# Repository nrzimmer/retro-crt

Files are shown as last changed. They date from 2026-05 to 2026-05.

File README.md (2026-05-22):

# CRT — Setup de Videogames em CRT

Documentação para uso e modificação de TV CRT Sony Trinitron KV-21FS140 com consoles retro via RGB SCART.

## Estrutura

```
tv/          — tudo sobre a KV-21FS140 (manuais, circuitos, mod, reparo)
scart/       — padrão SCART, switches, cabos por console
consoles/    — mods internos dos consoles (RGB, áudio, etc.)
```

| Pasta | Conteúdo |
|---|---|
| [`tv/`](tv/) | Manual de serviço, análise de circuitos, mod RGB, reparo pincushion |
| [`scart/`](scart/README.md) | Padrão SCART, switch, cabos por console, fornecedores |
| [`consoles/`](consoles/) | Mods de consoles (NES NESRGB/PPU-LITE, N64 RGB, SNES Mini, MD stereo) |

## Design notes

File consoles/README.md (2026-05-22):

# Consoles — Mods Internos

Mods de hardware nos consoles para habilitar ou melhorar saída RGB/áudio.  
Cabos SCART correspondentes estão em [`scart/cables/`](../scart/cables/).

| Pasta | Console | Mods documentados |
|---|---|---|
| [`nes/`](nes/) | NES / Famicom | NESRGB, PPU-LITE (open source), áudio stereo, expansion audio |
| [`n64/`](n64/) | Nintendo 64 | RGB amp (THS7316), opções de mod analógico |
| [`snes/`](snes/) | Super Nintendo | SNES Mini — csync no chip S-RGB |
| [`megadrive/`](megadrive/) | Sega Mega Drive | Mod stereo áudio (MD1) |

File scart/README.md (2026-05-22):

# Cabos SCART RGB

Documentação para construção de cabos SCART RGB para consoles retro.  
Alvo principal: mod RGB no KV-21FS140 (`../tv/mod_rgb/rgb_mod.md`).

## Índice

| Arquivo | Conteúdo |
|---|---|
| [standard.md](standard.md) | Padrão SCART 21 pinos — referência |
| [switch.md](switch.md) | Switch SCART: topologias, chips, projetos OSS |
| [fornecedores.md](fornecedores.md) | Onde comprar conectores e componentes |

### Cabos por console (`cables/`)

| Arquivo | Console | Conector | Status |
|---|---|---|---|
| [cables/nes.md](cables/nes.md) | NES / Famicom | MultiAV 12P (via NESRGB mod) | documentado — requer mod RGB |
| [cables/snes.md](cables/snes.md) | Super Nintendo / Super Famicom | MultiAV 12P card-edge | documentado |
| [cables/megadrive.md](cables/megadrive.md) | Sega Mega Drive 1 e 2 | DIN-8U / mini-DIN 9 | documentado |
| [cables/ps1.md](cables/ps1.md) | PlayStation 1 / PSone | Proprietário 12P | documentado |
| [cables/ps2.md](cables/ps2.md) | PlayStation 2 | Proprietário 12P (= PS1) | documentado |
| [cables/n64.md](cables/n64.md) | Nintendo 64 | MultiAV 12P (= SNES) | documentado — requer mod RGB |
| [cables/saturn.md](cables/saturn.md) | Sega Saturn | mini-DIN 10 | documentado |
| [cables/neogeo.md](cables/neogeo.md) | SNK Neo Geo AES/MVS | DIN-8C | documentado |

### Mods de consoles (`../consoles/`)

| Arquivo | Console | Conteúdo |
|---|---|---|
| [../consoles/nes/](../consoles/nes/) | NES / Famicom | NESRGB, PPU-LITE, mods de áudio |
| [../consoles/n64/](../consoles/n64/) | Nintendo 64 | THS7316, opções de mod RGB |

## Componentes comuns a todos os cabos

| Componente | Valor | Função |
|---|---|---|
| R_blank_top | 820Ω | Divisor blanking (SCART pin 16) |
| R_blank_bot | 1kΩ | Divisor blanking → ~2.6V |

## Componentes específicos por console

| Console | Componente extra | Motivo |
|---|---|---|
| SNES NTSC | 220µF ×3 nas linhas RGB | DC offset ~1V na saída |
| SNES PAL | 75Ω ×3 para GND nas linhas RGB | Redução de contraste |
| NES (NESRGB) | 220µF ×3 nas linhas RGB | Mesmo DC offset do SNES |
| N64 (após mod) | 220µF ×3 nas linhas RGB | Mesmo DC offset do SNES |
| PS1 | 220µF ×3 nas linhas RGB | PS1 não tem caps internamente |
| PS2 | Nenhum extra | PS2 já tem 220µF internamente |
| Saturn | 470Ω + 220µF na linha csync | Artefatos no Model 2 sem eles |

## Avisos críticos

> ⚠️ **SNES PAL:** Pin 3 = +12V. Cabo NTSC em SNES PAL danifica equipamento.  
> ⚠️ **NES:** sem mod NESRGB, zero RGB — nem composite RGB.  
> ⚠️ **N64 NTSC:** sem mod RGB interno, cabo SCART RGB não funciona.  
> ⚠️ **PS1 ≠ PS2:** cabos não são intercambiáveis — caps nos canais RGB diferem.  
> ⚠️ **PS2 + 480p:** muitos jogos forçam 480p (31kHz) — incompatível com KV-21FS140.

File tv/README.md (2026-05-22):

# TV — Sony Trinitron KV-21FS140

Documentação técnica, mods e reparo da KV-21FS140 (chassis BX1S).

## Estrutura

| Pasta | Conteúdo |
|---|---|
| [`manual/`](manual/README.md) | PDFs e páginas extraídas dos dois manuais de serviço |
| [`circuits/`](circuits/) | Análise dos blocos de circuito, service mode, diagnóstico |
| [`mod_rgb/`](mod_rgb/rgb_mod.md) | Mod RGB SCART (esquemático, netlist, KiCad) |
| [`repair/`](repair/) | Reparo pincushion — lista de componentes |

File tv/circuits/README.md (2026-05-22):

# Circuits — Análise de Circuitos KV-21FS140

Análise dos blocos de circuito da A Board e C Board, parâmetros de service mode e diagnóstico.  
Baseado em ambos os manuais — diferenças entre rev_brazil e rev_s79aa são anotadas em cada arquivo.

## Arquivos

### Blocos de circuito (A Board)

| Arquivo | Bloco | Conteúdo |
|---|---|---|
| [block_001_processor.md](block_001_processor.md) | Block 001 | IC001 One-Chip — System/Video/Audio Processor |
| [block_002_audio.md](block_002_audio.md) | Block 002 | IC200 Audio Amp (AN5276T / AN17804A) |
| [block_003_psu.md](block_003_psu.md) | Block 003 | SMPS — transformador T600, reguladores |
| [block_004_deflection.md](block_004_deflection.md) | Block 004 | Deflexão H/V — Q805, IC804, FBT T801, EW |
| [block_005_if_tuner.md](block_005_if_tuner.md) | Block 005 | IF — tuner, VIF SAW, SIF, AGC |
| [block_006_av_inputs.md](block_006_av_inputs.md) | Block 006 | Entradas AV, SCART, RGB |
| [c_board_rgb_amp.md](c_board_rgb_amp.md) | C Board | IC751 TDA6108AJF — RGB amp para cátodos do CRT |

### Service Mode e Diagnóstico

| Arquivo | Conteúdo |
|---|---|
| [self_diagnostic.md](self_diagnostic.md) | Códigos LED, diagnóstico por sintoma, proteções |
| [service_mode_categories.md](service_mode_categories.md) | Todas as categorias GEOM/WHBL/SADJ/etc. com valores por variante |
| [geom_service_params.md](geom_service_params.md) | Parâmetros GEOM detalhados, sequência de ajuste |
| [voltage_waveform_table.md](voltage_waveform_table.md) | Tensões nominais e formas de onda |

### Análise geral

| Arquivo | Conteúdo |
|---|---|
| [schematic_analysis.md](schematic_analysis.md) | Análise completa de todos os blocos do esquemático |

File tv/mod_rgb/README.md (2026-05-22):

# Mod RGB — KV-21FS140

Mod para habilitar entrada RGB SCART via CN004/CN701 (C Board).

| Arquivo | Conteúdo |
|---|---|
| [rgb_mod.md](rgb_mod.md) | Descrição do mod, componentes, procedimento de instalação |
| [rgb_mod_netlist.md](rgb_mod_netlist.md) | Netlist do circuito do mod |
| [rgb_mod_schematic.svg](rgb_mod_schematic.svg) | Esquemático em SVG |
| [rgb_mod.kicad_sch](rgb_mod.kicad_sch) | Projeto KiCad |
| [gen_kicad_sch.py](gen_kicad_sch.py) | Script Python que gerou o esquemático KiCad |

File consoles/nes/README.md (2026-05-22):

# NES / Famicom — Mods RGB e Áudio

---

## RGB — NES não tem saída nativa

NES padrão (front-loader e top-loader USA) só tem saída **RF e composite**.  
RGB requer mod interno obrigatório.

| Modelo | RGB nativo | Notas |
|---|---|---|
| NES front-loader (USA) | ✗ | Mod obrigatório |
| NES top-loader (USA) | ✗ | Mod obrigatório |
| Famicom original (JP) | ✗ | Composite + RF apenas |
| AV Famicom (HVC-101) | ✗ RGB nativo | Composite + S-Video; sem RGB sem mod |
| Famicom Titler | ✓ | Raríssimo — saída RGB/S-Video nativa |

---

## Mods RGB disponíveis

| Mod | Saída | Conector instalado | Notas |
|-----|---|---|---|
| **NESRGB** (Tim Worthington) | RGB analógico | Multi-out estilo SNES | Melhor opção — usa PPU original |
| PC-10 (Playchoice-10) | RGB analógico | Depende da instalação | Original Nintendo, difícil de encontrar |
| Hi-Def NES | HDMI digital | HDMI | Não usa SCART |
| UltraHDMI | HDMI digital | HDMI | Não usa SCART |

---

## PPU-LITE — alternativa open source ao NESRGB

**PPU-LITE** (andkorzh) — substituto FPGA do PPU, open source, custo reduzido.

| Aspecto | NESRGB (original) | PPU-LITE (open source) |
|---|---|---|
| Licença | Proprietário (Tim Worthington) | Open source — GitHub |
| PCB | 4 camadas | **2 camadas** — mais barato |
| FPGA | — | Cyclone I EP1C3T100C8N (Altera) ou Lattice LCMXO2 |
| Forma/tamanho | Referência | **Idêntico ao NESRGB** — mesmos adaptadores |
| Paletas (Cyclone) | — | 4: NES Classic, SONY CXA, Smooth, Natural Nestopia YUV |
| Paletas (Lattice) | — | 8: + CDIRECT, PC-10, PVM Style, WaveBeam |
| Seleção paleta | — | Jumpers J3/J4 (Cyclone) ou J3/J4/J5 (Lattice) |
| DAC | ADV7125 | R2R discreto com arrays de resistores |
| Venda | Tim Worthington / revendedores | Ninguém vendendo ainda — fabricar próprio |
| Instalação | Igual ao NESRGB | Igual ao NESRGB |

**Repositório:** https://github.com/andkorzh/PPU-LITE  
**Gerbers:** inclusos no repo — mandar fabricar JLCPCB/PCBWay  
**Upload FPGA:** somente arquivo `.jic` (Cyclone) ou equivalente Lattice — NÃO usar `.pof`

> PPU-LITE foi intencionalmente dimensionado igual ao NESRGB para reaproveitar todos os métodos de instalação e adaptadores existentes.

---

## Onde comprar

### Conector Multi-out para cabo DIY

| Fornecedor | Link | Notas |
|---|---|---|
| Humble Bazooka | [SNES Multi-Out for NESRGB](https://www.humblebazooka.com/products/snes-style-multi-out-connector-for-nesrgb/) | Conector específico para instalar no NES |
| Console5 | [SNES/N64/GCN AV Multi-Out plug](https://console5.com/store/nintendo-snes-super-famicom-n64-av-multi-out-plug-for-custom-rgb-cables-repair.html) | Conector macho para o cabo (lado do cabo, não do console) |

### Mod NESRGB

| Fornecedor | Link | Notas |
|---|---|---|
| 8BitMods (oficial) | [NESRGB by Tim Worthington](https://8bitmods.com/nesrgb-by-tim-worthington/) | Original — qualidade garantida, frete internacional |
| AliExpress (clone) | [1:1 copy NESRGB kit](https://www.aliexpress.com/item/1005006858950207.html) | Clone — "1:1 copy", funciona mas não é original |
| AliExpress (clone) | [NESRGB kit — busca geral](https://www.aliexpress.com/w/wholesale-nesrgb.html) | Vários vendedores, preços variados |
| AliExpress (clone) | [5× NESRGB PCB board](https://www.aliexpress.com/i/1005003035447719.html) | PCB avulso — precisa soldar componentes |
| **PPU-LITE (open source)** | [GitHub andkorzh/PPU-LITE](https://github.com/andkorzh/PPU-LITE) | Fabricar gerbers no JLCPCB — mais barato |

> **Clone AliExpress vs original:** clones "1:1" geralmente funcionam mas qualidade de fabricação varia. Para uso sério, preferir original da 8BitMods ou fabricar PPU-LITE pelos gerbers.

---

## Alternativas de vídeo ao RGB SCART

NES não tem saída component nativa. Opções além de RGB/SCART:

| Alternativa | Qualidade | Notas |
|---|---|---|
| NESRGB / PPU-LITE → SCART | ✓✓ Melhor analógico | Mod interno obrigatório |
| Hi-Def NES / UltraHDMI | ✓✓ Digital | HDMI direto, sem SCART |
| Upscaler (RetroTINK 2x) | ✓ Boa | Composite/S-Video → HDMI; sem mod no NES |
| S-Video (NES top-loader) | ✓ Razoável | Top-loader tem saída S-Video melhorada |
| Composite direto | Baixa | Sem mod; funciona com mod RGB da KV-21FS140 via AV2 |

> Não existe mod component para NES. RGB → SCART é o melhor analógico disponível.

---

## Mod Áudio

### Áudio mono (sem mod)

Sem nenhum mod de áudio, simplar o pino mono nos dois canais do SCART:

```
NES Audio (mono) ──┬──► SCART Pin 6  (Audio In L)
                   └──► SCART Pin 2  (Audio In R)
```

TV recebe mesmo sinal nos dois canais — ambos os alto-falantes funcionam.

### Mod "Stereo" (pseudo-stereo)

O NES tem APU com **duas saídas separadas antes do mixer interno**:

| Canal | Conteúdo |
|---|---|
| AUX A (canal 1) | Pulso 1 + Pulso 2 (square waves) |
| AUX B (canal 2) | Triângulo + Ruído + DPCM |

Não é stereo real — é separação dos grupos de canais do APU em duas saídas.

**Plain mod:**
- Desconectar AUX A e AUX B do mixer interno
- Adicionar cap 1µF em série em cada canal (polo − para o console)
- Adicionar conector de saída (RCA L/R ou P2 stereo)

**Mixback mod:**
- Tocar AUX A e AUX B sem desconectar do mixer
- Adicionar potenciômetro duplo para misturar o sinal mono de volta (controle de separação)
- Permite ajustar de mono completo a separação máxima

### Expansion Audio (Famicom)

Alguns cartuchos Famicom têm chips de som extras (VRC6, VRC7, MMC5, FDS, etc.) que misturam áudio adicional pelo pino 46 do slot de 60 pinos. No NES (72 pinos) esses pinos não existem — expansão é silenciada.

**O EverDrive N8 suporta expansion audio** — emula os chips de som nos mappers. Mas o NES front-loader precisa de mod para rotear esse áudio até a saída.

#### Mod expansion audio — NES front-loader com EverDrive N8 / flashcart 72 pinos

Soldar **resistor 47kΩ** entre dois pinos da porta de expansão (conector na parte inferior do front-loader):

```
Expansion pin 9  (EXP6) ── 47kΩ ──► Expansion pin 3  (Audio mix input)
```

Opcional mas recomendado para reduzir ruído:
```
Expansion pin 9  (EXP6) ── 1kΩ ──► Expansion pin 2  (GND)
```

> ⚠️ Não confundir **expansion pin 9 (EXP6)** com **expansion pin 6 (EXP9)** — nomes confusos intencionalmente.

**Com NESRGB instalado:** o NESRGB tem ponto de mix dedicado (hole próximo ao jumper J5). Soldar fio blindado 28AWG nesse ponto, passar resistor 47kΩ em série, conectar ao pino de expansão. Guia completo com fotos: [firebrandx.com/edn8tonesrgb.html](http://www.firebrandx.com/edn8tonesrgb.html)

**Volume:** EverDrive N8 firmware controla volume por mapper. Para VRC6, volume level 35 é o mais balanceado. Se necessário, substituir arquivo `EDFC/MAPS/024.RBF` na SD card pela versão fixada em volume 35.

**Adaptador potenciômetro (opcional):** em vez de resistor fixo 47kΩ, usar pot 100kΩ + resistor fixo 20kΩ em série — permite ajustar volume sem abrir o console.

#### Jogos com expansion audio (Famicom)

| Chip | Jogos notáveis |
|---|---|
| VRC6 | Castlevania III (JP), Akumajo Densetsu |
| VRC7 | Lagrange Point |
| MMC5 | Castlevania III (USA tem MMC5 — mas sem expansão no NES) |
| FDS | Metroid (JP), Zelda (JP), Gimmick! |
| Sunsoft 5B | Gimmick! |
| N163 | Megami Tensei II |

---

## Referências

- [NES RGB — RetroRGB](https://retrorgb.com/nesrgb.html)
- [NES "Stereo" Audio Mod — ConsoleMods](https://consolemods.org/wiki/NES:%22Stereo%22_Audio_Mod)
- [NES Expansion Audio Mod — ConsoleMods](https://consolemods.org/wiki/NES:Expansion_(EXP)_Audio_Mod)
- [EverDrive N8 + Expansion Audio + NESRGB — firebrandx.com](http://www.firebrandx.com/edn8tonesrgb.html)

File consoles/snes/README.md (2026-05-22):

# Super Nintendo / Super Famicom — Mods

---

## SNES Mini (Super Famicom Jr.) — csync

SNES Mini não expõe csync no MultiAV. Para usar cabo SCART com csync limpo:

- csync disponível no **pino 18 do chip S-RGB** (PPU2 / S-RGB encoder) na placa
- Requer acesso interno e fio soldado até o conector MultiAV ou diretamente ao cabo

Alternativa sem mod: usar luma (pin 7 do MultiAV) como sync — funciona com a maioria dos displays.

---

## Referências

- [SNES Mini RGB — RetroRGB](https://retrorgb.com/snesminijr.html)

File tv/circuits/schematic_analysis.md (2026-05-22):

# KV-21FS140 — Análise Completa dos Esquemáticos

## Estrutura da A Board (7 Blocos)

A placa principal (A Board) está dividida em 7 blocos funcionais. Cada bloco é uma seção do esquemático com nome e número de referência de grade (letras A–L, números 1–17).

Conexões entre blocos são indicadas como `XXX:YZ` → bloco:coluna/linha.

---

## BLOCK 001 — Processador Central (IC001)

**Função:** Núcleo do sistema. Contém o IC one-chip que faz tudo: controle de sistema, processamento de vídeo, processamento de áudio, demodulação, geometria.

### IC principal
| Ref | Tipo | Função |
|-----|---|---|
| IC001 | TDA12009H (ou variante) | One-chip: System Controller + Video Processor + Audio Processor |
| IC003 | CAT24WC16WI-TE13 | NVM — EEPROM 16kbit (armazena dados de serviço) |
| IC002 | RPM7240-H5 | IC Receiver (controle remoto SIRCS) |

### Transistores de interface e proteção
| Ref | Tipo | Função |
|-----|---|---|
| Q001 | UN2211 | RGB-MUTE SPOT — mute dos sinais RGB no CRT |
| Q006 | UN2216 | G LED SW — switch do LED verde (standby) |
| Q007 | UN2216 | R LED SW — switch do LED vermelho |
| Q010 | 2SA1235-F | Buffer geral |
| Q013 | (XX) | S2 switch |
| Q016 | UN2211 | PROTECTOR |

### Componentes passivos notáveis
| Ref | Valor | Função |
|-----|---|---|
| X001 | 181331121 | Cristal de referência 24.576MHz (clock principal IC001) |
| L036 | 22µH | Filtro de alimentação 3.3V |
| L040 | 10µH | Filtro alimentação |
| D914 | SPB-25MVWF | LED bicolor (standby/ativo) |
| D002 | MMDL914T1 | Diodo fornecimento 3.3V |
| D003 | MMDL914T1 | Diodo fornecimento 5V |
| D057/D058/D059 | MMDL914T1 | R-MUTE / G-MUTE / B-MUTE (mute individual de canhões RGB) |

### Pinos chave do IC001 (por função)
| Pino | Sinal | Destino/Origem |
|---|---|---|
| 21 | EWD | EWD-DEFL → Block 004 grid 5A (sinal de correção pincushion) |
| 32 | EHTO | OCP (detecção overcurrent do +B) |
| 65 | VM | VM OUT — Velocity Modulation (saída para VM coil) |
| 66 | AFC | AFC-DEFL → Block 004 (AFC horizontal) |
| 67 | HOUT | HOUT-DEFL → Block 004 grid 6A (pulso de drive horizontal) |
| 83 | ABL | ABL → Block 004 (Automatic Beam Limiter) |
| 13 | VGUARD | VGUARD-DEFL → Block 004 (proteção vertical) |
| 14/15 | PH2LF/PH1LF | Horizontal PLL phase → Block 004 |
| 22/23 | VD+/VD- | Vertical drive → Block 004 |
| 84 | IK | AKB (Auto Black Level) feedback do C Board |
| 85/86/87 | B/G/R OUT | Saída RGB → C Board via CN004/CN701 |
| 108/109 | SCL0/SDA0 | I²C bus para NVM e dispositivos auxiliares |
| 110 | VDDP(3.3V) | Alimentação digital 3.3V IC001 |

### Conectores do Block 001
| Conector | Pinos | Destino |
|---|---|---|
| CN004 | 7P | → C Board CN701 (R/G/B/IK/GND/9V) |
| CN005 | 3P | Botões frontais (KEY) |
| CN007 | (XX) | → Block 006 CN905 |

### Tensões IC001 (medidas representativas)
- Pin 4: 2.6V, Pin 5: 3.2V, Pin 21: 3.2V (EWD)
- Pin 45 (VCC8V): 8.3V, Pin 84 (IK): 1.5V
- Pin 110 (VDDP 3.3V): 3.2V

---

## BLOCK 002 — Amplificador de Áudio

**Função:** Amplificação final de áudio, circuito de mute, proteção de saída.

### IC principal
| Ref | Tipo | Função |
|-----|---|---|
| IC200 | AN5276T | Audio Amplifier — 2× 10W |

### Transistores
| Ref | Tipo | Função |
|-----|---|---|
| Q200 | UN2211 | BUFFER |
| Q201 | 2SA1235-F | BUFFER |
| Q202 | 2SA1235-F | AC MUTE |
| Q204, Q205 | (XX) | BUFFER (não montados neste modelo) |
| Q206 | UN2211 | MUTE CCT |

### Passivos notáveis
| Ref | Valor | Função |
|-----|---|---|
| C214/C215/C216/C217 | 1000/2200µF 25V | Capacitores de saída do amp |
| C218/C219 | 22µF | Filtros de feedback |
| R234, R235 | 47Ω FPRD | Resistores fusíveis de proteção (saída do amp) |
| R2646, R2647 | 1Ω / 10k FPRD | Resistores de sensing de saída |
| J200 | 177078631 | Conector de entrada de áudio |
| CN200 | 4P WHT | Conector de saída para alto-falantes |

### Sinais de controle
- `AUDIO-STDBY` ← 001:1F (standby de áudio)
- `AUDIO-MUTE` ← 001:4L (mute geral)
- `MOMUTE-AUDIO` ← 001:7A (mute de monitor out)
- `PWR-OFF-MUTE` ← 001:5A

### Tensões
- IC200: alimentado por 9V
- Q201: B=82.3V, C=0V, E=0V (em standby)

---

## BLOCK 003 — Fonte de Alimentação (SMPS)

**Função:** Conversora chaveada principal. Gera todas as tensões secundárias a partir de 110–220V AC.

### ICs e reguladores
| Ref | Tipo | Função |
|-----|---|---|
| IC601 | (175519811) | SWITCHING REGULATOR IC principal do SMPS |
| IC602 | KIA78R09API | Regulador linear 9V (entrada 11V) |
| IC603 | PQ018EF01SSH | Regulador 1.8V (para áudio) |
| IC604 | KIA7805API | Regulador linear 5V |
| IC605 | SE135N-LF38 | ERROR AMP / REG auxiliar |
| IC606 | KIA78D33P1 | Regulador linear 3.3V |
| IC607 | BA18BC0FP-E2 | Regulador 1.8V principal (digital) |

### Transistores de potência
| Ref | Tipo | Função |
|-----|---|---|
| Q601 | (não listado explicitamente) | RELAY SW — chave do relé principal |
| Q605 | (XX) | BUFFER regulador |
| Q606 | (componente crítico !) | Transistor principal de chaveamento |
| Q608 | 2SC1623-L5L6 | SW auxiliar |
| Q609 | 2SC1623-L5L6 | SW auxiliar |

### Componentes críticos de segurança (marcados !)
| Ref | Valor/Tipo | Função |
|-----|---|---|
| THP600 | TERMISTOR PTC | Proteção térmica / limitação de inrush |
| C660 | 0.22µF 275V PP | Filtro EMI fase/neutro |
| T600 | MTZJ-T-77-15 | Transformador principal SMPS (!!) |
| T603 | — | Transformador auxiliar |
| T604, T605 | — | Transformadores de isolação |
| PS602, PS603, PS604, PS605 | 5A 90V | Varistores PTC de proteção |
| F600 | FUSÍVEL | Fusível principal da A Board |
| S600 | — | Varistor de proteção (VDR600) |
| VDR600 | — | Varistor de surto |
| D604 | D3SB60F3 | Ponte retificadora AC |
| RY600 | RELAY AC POWER | Relé de entrada AC |

### Tensões produzidas
| Linha | Tensão | Observação |
|---|---|---|
| +B | ~135V | Linha principal para deflexão H |
| 11V | 11V | Input para IC602 |
| 9V | 9V | IC602 output; para áudio, tuner, etc. |
| 5V | 5V | IC604; para digital |
| 3.3V | 3.3V | IC606; para digital |
| 1.8V | 1.8V | IC607 e IC603 |
| 30V | 30V | Para RF Amp/Tuner |

### Proteções
- OCP: detectado por IC001 pin 32 ← feedback de Q816 collector (Block 004)
- OVP: detectado por IC001 pin 13 (V-GUARD) ← pulso vertical ausente
- Relé DGC: acionado por DGC-RELAY signal de IC001 (desmagnetização)

---

## BLOCK 004 — Deflexão (DEFLECTION)

**Função:** Geração e amplificação dos sinais de deflexão horizontal e vertical, incluindo circuitos de pincushion EW, S-correction, ABL, proteções OCP/OVP.

Este bloco é o mais crítico para geometria da imagem.

---

### 4A. Estágio de Driver Horizontal + Pincushion (EW)

#### Cadeia de sinal horizontal:
```
IC001 pin HOUT → [HOUT-DEFL] → Q807 (PIN DRIVE) → T800 → Q805 (H-OUT) → T801 (FBT)
```

| Ref | Tipo | Função | Tensões medidas |
|-----|---|---|---|
| Q807 | 2SA1235-F | PIN DRIVE — transistor PNP de pré-drive do horizontal + pincushion | E=0.1V, B=1.1V, C=0V |
| Q803 | 2SC3209LK | PIN AMP / H-DRIVE — amplificador do sinal de pincushion | C≈70V, E=0V, B≈133V |
| T800 | 143793622 | Transformador driver horizontal — acopla o drive para Q805 | — |
| Q805 | 2SC5885 | H-OUT — transistor de saída horizontal principal (NPN alta tensão) | Coletor: pulso >500Vp-p |
| D807 | BY228GP | DAMPER — diodo amortecedor horizontal (essencial para forma de onda) | — |
| D817 | PG156R | DAMPER secundário | — |

#### Componentes do circuito de pincushion EW (East-West):

O pincushion (efeito almofada) resulta do fato de que a tela plana ou levemente curvada precisa de maior amplitude de varredura nas linhas do centro (onde a distância ao canhão é maior) e menor nos extremos verticais. O circuito EW modula a amplitude do sinal horizontal com uma forma de onda parabólica sincronizada com a frequência vertical.

**Fluxo de sinal EW:**
```
IC001 pin EWD → [EWD-DEFL → Block 004 grid 5A]
    → IC802 (op-amp TJM4558CDT) → amplifica/formata sinal parabólico
    → Q806 (MIXER 2SC1623) → combina com sinal H
    → L802 (22mH) → bobina EW em série com yoke H
    → DY800 → Deflection Yoke (bobinas horizontais)
```

| Ref | Valor/Tipo | Função |
|-----|---|---|
| IC802 | TJM4558CDT | Op-amp duplo — formata/amplifica sinal EWD da IC001 |
| Q806 | 2SC1623-L5L6 | MIXER — mistura sinal EW na corrente horizontal |
| Q809 | 2SC3209LK | Transistor auxiliar EW/drive |
| Q810 | 2SC3209LK | Transistor auxiliar EW |
| L802 | 22mH | **Bobina EW** — em série na alimentação do yoke horizontal, modula amplitude H |
| C857 | 220µF 25V | Filtro/reservatório EW |
| C861 | 220µF 25V | Filtro/reservatório EW |
| C867 | 33µF 160V | Capacitor ressonante do estágio H-OUT (junto com L805) |
| C878 | 0.01µF 25V | Bypass EW |
| D818 | 10ERB20-TB3 | Retificador EW |
| D819 | 10ERB20-TB3 | Retificador EW |
| D821 | 10ERB20-TB3 | H-CENT1 — circuito de posição horizontal |
| D823 | PG104R | RECTIFIER EW |
| D824 | PG104R | RECTIFIER EW |
| D827 | PG104R | RECT |
| D828 | — | circuito auxiliar |
| R890 | — | Resistor de ajuste EW |
| R888 | 47kΩ | Divisor de sinal EW |
| C860 | 1000p 500V | Filtro HV EW |

**Tensões medidas IC802 (TJM4558CDT):**
| Pino | V | Função |
|---|---|---|
| 1 | 3.3V | OUT1 (saída do 1º amp) |
| 2 | 2.2V | IN1- |
| 3 | 6.0V | IN1+ (recebe EWD de IC001) |
| 4 | 8.8V | V+ (alimentação positiva) |
| 5 | 2.4V | IN2+ |
| 6 | 3.1V | IN2- |
| 7 | 3.0V | OUT2 |
| 8 | 0V | V- (GND) |

#### Circuito de S-Correction:

A S-correction compensa a distorção em S na varredura horizontal (causada pela diferença entre a trajetória do feixe e a tela plana ao longo do eixo X).

| Ref | Tipo | Função |
|-----|---|---|
| Q808 | IRF614-037 | **S-CORRECTION** — MOSFET de potência, controla a modulação de largura horizontal para compensar distorção em S |
| C825 | 0.022µF 200V PP | Capacitor de S-correction |
| C842 | 0.022µF 400V PP | Capacitor de S-correction |
| R406 | XX | Resistor de S-correction |
| D801 | — | STOPPER do S-correction |

**Tensões Q808 (IRF614 MOSFET):**
- S: 1.8V, G: 0.1V, D: 0V (em repouso)

#### Circuito de H-Center (posição horizontal):

| Ref | Tipo | Função |
|-----|---|---|
| IC801 | LM2903DT | COMPARATOR — detecta e controla posição do centro H |
| S800 | 157270711 | Ajuste de centro H (trim) |
| D819 | 10ERB20-TB3 | H-CENT1 |
| R412 | 22kΩ 1/2W | Divisor do comparador |
| R411 | 68kΩ 1/2W | Divisor do comparador |
| R413 | 0.47Ω | Sensing de corrente |
| R405 | 0.47Ω | Sensing de corrente |
| R896 | 10kΩ | Pull-up |

---

### 4B. Estágio de Saída Horizontal (H-OUT) e FBT

| Ref | Tipo | Função |
|-----|---|---|
| Q805 | 2SC5885 | **H-OUT** — transistor de saída horizontal. Coletor conectado ao FBT (T801). Alta tensão de coletor em operação. |
| Q804 | KTA1279 | STOPPER — limita o pico de tensão no coletor de Q805 |
| Q814 | 2SC1623-L5L6 | Transistor auxiliar H |
| T801 | NX-4751//M3A4 | **FBT (Flyback Transformer)** — gera HV para ânodo do CRT (~25kV), e tensões secundárias (SV, FV, -13V para vertical, etc.) |
| T802 | (XX) | — não montado |
| D807 | BY228GP | DAMPER — absorve a energia de retrace, protege Q805 |
| D816 | — | Diodo auxiliar |
| C841 | 0.1µF 400V PP | Capacitor de ressonância H |
| C846 | — | Capacitor HV |
| C847 | — | Capacitor auxiliar |
| C867 | 33µF 160V | **Capacitor de ressonância principal** — junto com L805, determina frequência de ressonância do estágio H |
| L805 | 2.2mH | **Bobina de linearidade** — em série com yoke H, corrige linearidade |
| L804 | (XX) | — não montado |
| R400, R401 | 0.47Ω 1/2W FPRD | Sensing de corrente do yoke H (resistores fusíveis!) |
| R416 | 4.7kΩ 1/2W | Resistor no circuito FBT |
| JW1840, JW1841 | fios 5mm / 7.5mm | Conexões de ajuste da bobina de linearidade |

#### Tensões do FBT (T801) — saídas secundárias
| Enrolamento | Tensão | Destino |
|---|---|---|
| HV | ~25kV | Ânodo do CRT (via cabo HV) |
| FV | ~600V | Focus (G3) do CRT |
| SV | ~500V | Screen (G2) do CRT |
| -13V (VSS) | -13V | IC804 (vertical IC) pin 1 |
| +13V (VCC) | +13V | IC804 pin 3 |

#### Pinos do FBT usados no esquemático
| Terminal | Destino |
|---|---|
| T801-1 | HV + GND_1 |
| T801-2 | HV + GND_1 |
| T801-4 | HV + GND_1 |
| T801-5 | FV / SV |
| T801-7 | Secondary |
| T801-9 | Secondary |
| T801-11 | Secondary |

---

### 4C. Estágio Vertical (IC804)

| Ref | Tipo | Função |
|-----|---|---|
| IC804 | STV9302A | **VERTICAL IC** — amplificador de deflexão vertical completo |
| Q009 | (MIXER) | Amplificador auxiliar do vertical |
| C854 | 2.2µF 35V | Capacitor de bootstrap vertical |
| C855, C858 | — | Filtros verticais |
| R326 | 220Ω | Resistor de ganho |
| R327 | 3.3kΩ | Resistor de ganho |
| D820 | PG102R | Retificador auxiliar vertical |
| R891 | 100Ω FPRD | Resistor fusível de saída vertical |
| R895 | 2.2Ω FPRD | Sensing de corrente vertical (fusível) |

**Tensões IC804 (STV9302A):**
| Pino | V | Função |
|---|---|---|
| 1 | -13.5V | VSS — alimentação negativa |
| 2 | * | (pulso — não mensurável com multímetro) |
| 3 | 13.9V | VCC — alimentação positiva |

**Sinais de entrada no IC804:**
- VD+ e VD-: pulso vertical de IC001 (pinos 22/23)
- PH2LF: sinal de fase horizontal baixo de IC001

**Sinais de saída do IC804:**
- V+ e V- → Yoke vertical via DY800
- H+ → parte do estágio H (feedback)

---

### 4D. Conectores e Proteções do Block 004

| Ref | Pinos | Função |
|-----|---|---|
| DY800 | 6P | **Deflection Yoke** — pinos H.DY (2 pinos H) e V.DY (2 pinos V) |
| CN801 | (XX) → CN703 | Conector → C Board (sinal H1 para yoke de foco) |

**Proteções:**
| Sinal | Detectado por | Ação |
|---|---|---|
| OVP-DEFL | IC001 pin 13 (VGUARD) | Standby se deflexão V parar |
| OCP-PROTECT | IC001 pin 32 (EHTO) ← Q816 | Standby se +B tiver overcurrent |
| HOLD_DOWN | ← Block 003 (fonte) | Mantém transistores desligados |
| ABL | IC001 pin 83 ← FBT | Limita corrente do feixe |

**Componentes de proteção adicionais:**
| Ref | Tipo | Função |
|-----|---|---|
| D829 | (FPRD) | Clamp |
| D812 | RD5.1ESB2 | PROTECTOR |
| D816 | RD5.6SB-T1 | CLAMP REG |
| D832, D833 | MMDL914T1 | STOPPER — proteção do CN801 |
| D804, D805, D808, D809 | 1SS133T-77 | STOPPER |
| TH800 | — | Termistor — proteção térmica do estágio H |
| R421, R422, R423 | — | Resistores de proteção |

---

### 4E. Circuito de Rotation (Rotação de Imagem)

| Ref | Função |
|-----|---|
| IC800 | (XX) ROTATION AMP — não montado neste modelo |
| CN800 | (XX) — não montado |
| R800–R817 | (todos XX) — não montados |

Sinal ROT_CTRL e ROT_SW vêm de IC001 mas o circuito de rotação não está populado.

---

## BLOCK 005 — IF / Tuner

**Função:** Recepção e demodulação do sinal de RF. Inclui tuner, filtros SAW, circuito IF de vídeo e áudio.

### Componentes principais
| Ref | Tipo | Função |
|-----|---|---|
| TU101 | 169369411 | **Tuner principal** |
| TU102 | (XX) | Tuner secundário — não montado |
| SWF100 | 179592911 | SAW filter — filtro IF de vídeo (44MHz) |
| SWF101 | 181339111 | SAW filter — filtro IF de som |
| SWF103 | (XX) | SAW auxiliar — não montado |
| CF101 | (XX) | Filtro cerâmico — não montado |
| CT131 | (XX) | Capacitor trim — não montado |
| CT139 | 178152621 | Capacitor trim do PLL |
| L100 | 100µH | Indutor filtro do tuner |
| L101 | 0.33µH | Indutor IF |
| L102 | (XX) | Não montado |
| L103, L107 | 0Ω (short) | Jumpers de roteamento |
| L105 | (XX) | Não montado |
| L106 | 100µH | Indutor de filtro |

### Transistores
| Ref | Tipo | Função |
|-----|---|---|
| Q100 | 2SC1623-L5L6 | BUFFER — buffer de saída IF |
| Q102 | 2SC3779C,D-AA | BUFFER — buffer de sinal IF |
| Q103, Q104 | (XX) | SWITCH — não montados |
| Q111 | (XX) | BUFFER — não montado |

### Reguladores auxiliares
| Ref | Tipo | Função |
|-----|---|---|
| D103 | MTZJ-33B | Regulador 33V para o tuner |
| D106 | RD3.3B | Regulador 3.3V auxiliar |

### Sinais de saída do Block 005
| Sinal | Destino |
|---|---|
| VIFIN1, VIFIN2 | → IC001 pins (entrada IF de vídeo) |
| SIFIN1, SIFIN2 | → IC001 pins (entrada IF de som) |
| PLLIF | → IC001 (PLL do tuner) |
| IFVO/IF_MON_OUT | → IC001 e Block 006 (monitor out de IF) |
| TU-AGC | → Block 006 (AGC do tuner) |
| 2SIF | → IC001 (2nd IF de som) |

---

## BLOCK 006 — Entradas AV / SCART / Monitor Out

**Função:** Gerencia todas as entradas e saídas de A/V: AV1, AV2, AV3, SCART, DVD/RGB, monitor out.

### Transistores
| Ref | Tipo | Função |
|-----|---|---|
| Q900 | 2SA1235-F | MONITOR OUT BUFFER |
| Q901 | UN2216 | Chave auxiliar |
| Q902 | UN2216 | Chave de vídeo |
| Q910, Q911 | (XX) | Não montados |
| Q912 | (XX) | AMP GAIN ADJUST — não montado |

### Passivos notáveis
| Ref | Valor | Função |
|-----|---|---|
| C901, C900 | 2.2µF 16V | Acoplamento AV |
| C955 | 47µF 35V | Filtro de alimentação |
| L902 | 47µH | Filtro de áudio |
| R9028, R9030 | 100Ω | Terminadores de entrada de vídeo |
| R928, R929, R930 | 75Ω | Terminadores de saída de vídeo (75Ω standard) |

### Conectores
| Ref | Pinos | Função |
|-----|---|---|
| J900 | (XX) | AV1 (não montado neste modelo) |
| J901 | 11P | SCART / AV |
| J903 | 3P | Conector auxiliar |
| J904 | (XX) | Não montado |
| J905–J909 | (XX) | Não montados |
| CN903, CN904 | — | I²C bus do tuner / conector auxiliar |
| CN905 | (XX) | → Block 001/002 |

---

## BLOCK 007 — (Referenciado como HS-A007)

Referenciado no Block 003 como "HS-A007:1B". Provavelmente circuito de soft-start ou Horizontal-Sync auxiliary. Detalhes não extraídos nos TXTs disponíveis.

---

## C BOARD (C/CV Board) — Amplificador RGB para o CRT

**Função:** Recebe os sinais RGB processados da A Board e os amplifica para o nível necessário para pilotar os cátodos do tubo (tipicamente 100–200V de excursão).

### IC principal
| Ref | Tipo | Função |
|-----|---|---|
| IC751 | TDA6108AJF/N1 | **RGB Output Amplifier** — 3 canais de alta tensão para cátodos R, G, B |

### Componentes de alta tensão
| Ref | Valor | Função |
|-----|---|---|
| C752 | 4700p 2kV | Desacoplamento de HV |
| C754 | 4.7µF 250V | Filtro 250V |
| C751 | 10µF 250V | Filtro HV |
| L780 | 22µH | Indutor de suavização HV |
| R781 | 0.56Ω 2W | Resistor de sensing |
| R795 | 100kΩ 1/2W FPRD | Divisor de HV (resistor de descarga!) |
| R757, R756, R758 | 1kΩ 1/2W | Resistores de entrada RGB |
| R774 | 150Ω 3W RS | Resistor de sensing de corrente (IK) |
| RV750 | 110MΩ | Resistor de descarga do ânodo (!) |
| D750 | PG102R | PROTECTOR |
| D780 | 1SS133T-77 | STOPPER |
| D781 | 1SS133T-77 | STOPPER |
| D754, D755, D756 | HSS82-TJ | PROTECTOR — proteção de HV |
| J751 | 145154411 | **Socket do CRT** — encaixa no neck do tubo |

### Pino IK (AKB)
- R774 (150Ω 3W) faz sensing da corrente de cátodo
- Sinal IK vai via CN701 → CN004 → IC001 pin 84 (feedback de auto black level)

### Conectores da C Board
| Conector | Pinos | Destino |
|---|---|---|
| CN701 | 7P WHT | ← A Board CN004 (R/G/B/IK/GND/9V) |
| CN703 | 5P WHT | ← A Board CN801 (H1/GND/NC) |
| CN704 | 1P | GND do CRT |
| CN705 | 1P | Aterramento |

### Ajuste de convergência estática
- RV750 (H.STAT) — ajuste horizontal de convergência estática (potenciômetro de 110MΩ... na verdade este valor parece ser da C Board, é um resistor de descarga. O potenciômetro H.STAT é mecânico na placa.)

---

## Resumo dos Sinais de Interface Entre Blocos

```
IC001 (Block 001)
  │
  ├─ EWD ──────────────────────────→ Block 004 (pincushion/EW)
  ├─ HOUT ─────────────────────────→ Block 004 (drive horizontal)
  ├─ AFC ──────────────────────────→ Block 004 (AFC horizontal)
  ├─ VD+/VD- ──────────────────────→ Block 004 (drive vertical)
  ├─ VGUARD ───────────────────────→ Block 004 (proteção V)
  ├─ ABL ──────────────────────────→ Block 004 ← (FBT feedback)
  │
  ├─ R/G/B OUT ────────────────────→ C Board (cátodos do CRT)
  ├─ IK ───────────────────────────← C Board (auto black level)
  │
  ├─ VIFIN1/2 ─────────────────────← Block 005 (IF vídeo)
  ├─ SIFIN1/2 ─────────────────────← Block 005 (IF áudio)
  │
  ├─ OUTL/OUTR ────────────────────→ Block 002 (áudio para amp)
  └─ I²C (SCL0/SDA0) ─────────────→ IC003 (NVM) + Tuner

Block 003 (SMPS)
  ├─ +B (135V) ────────────────────→ Block 004, Block 005, Block 001
  ├─ 9V ───────────────────────────→ Block 001, 002, 004, 005, 006
  ├─ 5V ───────────────────────────→ Block 001, 002, 004, 005, 006
  ├─ 3.3V ─────────────────────────→ Block 001, 004
  └─ 1.8V ─────────────────────────→ Block 001

Block 004 (Deflexão)
  ├─ FBT (T801) → HV (25kV) ───────→ C Board (ânodo CRT)
  ├─ FBT → FV/SV ──────────────────→ C Board (focus/screen CRT)
  ├─ FBT → -13V/+13V ──────────────→ IC804 alimentação
  ├─ OCP-PROTECT ──────────────────→ Block 001 (IC001 proteção)
  ├─ OVP-DEFL ─────────────────────→ Block 001 (IC001 proteção)
  └─ DY800 ─────────────────────────→ Deflection Yoke (externo)
```

---

## ANÁLISE DETALHADA: Circuito Horizontal / Pincushion (EW)

### Visão Geral do Problema

O efeito almofada (pincushion) é uma distorção geométrica onde os lados verticais da imagem se curvam para dentro. Acontece porque:
- O CRT tem geometria cônica/esférica
- A tela é plana (ou quase)
- As linhas horizontais do centro têm maior amplitude que as dos extremos verticais (top/bottom)

A correção EW modula a **amplitude do sinal horizontal** com uma onda **parabólica na frequência vertical** (50Hz/60Hz): nas linhas do centro da tela a amplitude H é maior, nos extremos é menor.

### Cadeia Completa do Sinal EW neste TV

```
[Dados GEOM no NVM (IC003)]
        │
        ▼
[IC001 — calcula forma de onda EWD digital]
  pino EWD (pin 21) → sinal analógico parabólico a 50/60Hz
        │
        │ EWD-DEFL (001:10L → 004:5A)
        ▼
[IC802 — TJM4558CDT — Dual Op-Amp]
  Amplifica e formata o sinal EWD
  Pin 3 (IN1+): recebe EWD da IC001
  Pin 1 (OUT1): sinal EW amplificado → 3.3V medido
  Pin 7 (OUT2): saída para próximo estágio → 3.0V medido
        │
        ▼
[Q806 — 2SC1623-L5L6 — MIXER]
  Combina o sinal parabólico EW com a corrente DC de alimentação
  E=(9.3)V, B=0V (ou próximo), C=4.9V
        │
        ▼
[L802 — 22mH — Bobina EW]
  ← Ponto crítico! Esta bobina fica em série com o fornecimento de +B
     para o estágio horizontal. A corrente através dela modula a 
     tensão disponível para Q805 (H-OUT), alterando a amplitude
     de varredura horizontal proporcionalmente.
        │
        ▼
[Q805 — 2SC5885 — H-OUT]
  Transistor de saída horizontal. Sua amplitude de operação varia
  conforme a tensão de alimentação modulada por L802.
        │
        ▼
[T801 — FBT — Flyback]
        │
        ▼
[DY800 — Deflection Yoke]
  Bobinas horizontais com amplitude variável → corrige pincushion
```

### Parâmetros de Serviço que Controlam o Pincushion EW

Todos estes parâmetros são programados digitalmente via IC001 e afetam o sinal EWD:

| Código GEOM | Nome | Efeito no pincushion |
|---|---|---|
| GEOM 005 | HSIZ (EW Width) | Amplitude geral do pincushion — aumentar = ampliar todos os lados |
| GEOM 006 | EWPW (EW Parabola/Width) | Curvatura da parábola EW — ajusta quanto os lados curvam |
| GEOM 007 | UCOP (EW Upper Corner Parabola) | Correção de pincushion no canto superior |
| GEOM 008 | LCOP (EW Lower Corner Parabola) | Correção de pincushion no canto inferior |
| GEOM 009 | EWTZ (EW Trapezoid) | Correção trapezoidal — corrige se um lado é maior que o outro |
| GEOM 000 | HPOS | Posição horizontal (não afeta pincushion, só shift) |
| GEOM 001 | HPAR | Horizontal Parallelogram (inclinação das linhas H) |
| GEOM 002 | HBOW | Horizontal Bow (curvatura em arco das linhas horizontais) |

**Como ajustar via service mode:**
1. Entrar: `[DISPLAY] → [5] → [VOL+] → [POWER]` (standby)
2. Navegar: `[1]/[4]` para selecionar GEOM
3. Selecionar item: `[2]/[5]` para navegar nos números
4. Ajustar: `[3]/[6]` para mudar valor
5. Gravar: `[MUTING] → [-]`

**Padrão recomendado para ajuste de geometria:** SPCB (Special Color Bar) ou Monoscópio

### Pinos do STV9302A (IC804) — Vertical IC

| Pino | Sinal | V medido |
|---|---|---|
| 1 | VSS (-13V) | -13.5V |
| 2 | Input (pulso V) | * |
| 3 | VCC (+13V) | 13.9V |
| 4,5 | Saídas V | Para yoke vertical via DY800 |

### Componentes da Bobina de Deflexão (DY800 — 6 pinos)
| Pino DY800 | Sinal | Origem |
|---|---|---|
| H.DY (2 pinos) | Bobinas horizontais | Q805 ← T801 + L805 + C867 |
| V.DY (2 pinos) | Bobinas verticais | IC804 (STV9302A) |

### Falhas Comuns no Circuito Horizontal/Pincushion

| Sintoma | Causa provável | Componente |
|---|---|---|
| Sem imagem, TV liga e desliga (OCP) | Q805 em curto | Q805 (2SC5885) |
| LED pisca 2x | Q805 ou IC751 em curto | Q805 / IC751 |
| Raster muito estreito / largo | Valor errado em HSIZ | Ajuste GEOM 005 |
| Pincushion não corrige | L802 aberta ou Q806 defeituoso | L802 (22mH) / Q806 |
| Pincushion só em cima ou só embaixo | UCOP ou LCOP incorreto | Ajuste GEOM 007/008 |
| Imagem trapezoidal | EWTZ incorreto | Ajuste GEOM 009 |
| Imagem em S (largura varia verticalmente) | Q808 (IRF614) defeituoso | Q808 |
| Falta de linearidade H | L805 com valor alterado | L805 (2.2mH) |
| Posição H incorreta | HPOS errado | Ajuste GEOM 000 |
| Imagem inclinada | HPAR incorreto | Ajuste GEOM 001 |
| Scan width instável | C867 seco | C867 (33µF 160V) |
| LED pisca 4x (V-Protect) | IC804 (STV9302A) | IC804 |
| Sem varredura vertical (raster horizontal único) | IC804 defeituoso | IC804 (STV9302A) |
| Deflexão vertical pequena | R891 ou R895 abertos (fusíveis) | R891/R895 FPRD |

### Tensões de Referência no Circuito H

| Ponto | V esperado | Observação |
|---|---|---|
| +B linha principal | 135V DC | Alimenta Q805 via L802 |
| Coletor Q805 (em operação) | Pulso >500Vp-p | Nunca medir com multímetro comum |
| IC804 VCC | +13.9V | Saída do FBT |
| IC804 VSS | -13.5V | Saída do FBT (negativa) |
| IC802 pin 4 | 8.8V | Alimentação op-amp EW |
| IC802 pin 3 | 6.0V | Entrada do sinal EWD |
| Q806 emitter | ~9.3V (PAL) / 9.9V (NTSC) | Ponto de operação EW |
| DY800 H | Pulso ~28Vp-p (na yoke) | Waveform 15 NTSC: 28.80Vp-p |

---

## Formas de Onda Chave (da tabela de medições, pág. 47–48)

| Ref | Waveform | Amplitude | Observação |
|-----|---|---|---|
| 15 | DY800 H (yoke horizontal) | 28.80Vp-p | Medida na bobina H do yoke |
| 16 | Q806 (EW MIXER) | 9.20Vp-p | Sinal EW no transistor mixer |
| 12 | Estágio H | 132.0Vp-p | Pulso horizontal no circuito |
| 14 | IC804 saída V | 1.40Vp-p | Saída vertical |
| 17 | IC804 saída V | 1.34Vp-p | Saída vertical |

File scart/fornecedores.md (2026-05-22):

# Fornecedores — Componentes para Cabos SCART e Mod RGB

## Conectores

### Conector SCART macho soldável (ponta do cabo → entra na TV)

| Fornecedor | Link | Notas |
|---|---|---|
| AliExpress | [SCART solder plug](https://www.aliexpress.com/w/wholesale-scart-connector.html) | Buscar "Euro SCART solder plug" — vende em kit de 5–20 |
| AliExpress direto | [Euro SCART macho soldável](https://www.aliexpress.com/item/32568127296.html) | ~$2–3/un |
| AliExpress lote | [Lote 20 pçs SCART macho](https://es.aliexpress.com/i/1005004046744467.html) | Mais barato em lote |
| Console5 (USA) | [SCART connectors](https://console5.com/store/parts/av-jacks-1/scart.html) | Qualidade confirmada, frete internacional |
| Mercado Livre | [busca: conector scart](https://lista.mercadolivre.com.br/conector-scart) | Verificar se é soldável e não apenas adaptador |

### Conector SCART fêmea PCB-mount (soquete no painel da TV — para o mod)

Para instalar na traseira/lateral da TV KV-21FS140 como entrada SCART permanente.

| Fornecedor | Link | Notas |
|---|---|---|
| AliExpress | [21 pin SCART fêmea 90° PCB — lote 50](https://www.aliexpress.com/item/1005004046652944.html) | 90° right-angle, through-hole — ideal para painel |
| AliExpress | [21 pin SCART fêmea 90° PCB — un.](https://www.aliexpress.com/item/4000771556293.html) | ~$1/un, right angle |
| eBay | [Euro SCART female socket PCB x10](https://www.ebay.com/itm/155519159118) | Lote de 10 |
| Console5 (USA) | [SCART fêmea 90° through-hole](https://console5.com/store/female-scart-jp21-through-hole-pcb-mount-21-pin-connector-right-angle.html) | Qualidade boa, frete caro |
| Console5 (USA) | [SCART fêmea 180° sem abas](https://console5.com/store/female-scart-jp21-through-hole-pcb-mount-21-pin-connector-straight-angle-180-no-mounting-tabs.html) | Montagem reta |

> **Ângulo:** 90° (right-angle) é mais fácil de montar em painel — cabo sai paralelo à superfície.

### Conector AV PlayStation 1 / PSone (macho, para plug no console)

Conector proprietário Sony 12 pinos. **Mesmo conector no PS1 fat e PSone slim** — e também PS2.

| Fornecedor | Link | Notas |
|---|---|---|
| AliExpress | [PS1 multi AV connector](https://www.aliexpress.com/w/wholesale-ps1-multi-av-connector.html) | Buscar "PS1 AV multi out connector" |
| AliExpress | [Playstation AV connector](https://www.aliexpress.com/w/wholesale-playstation-av-connector.html) | Alternativa de busca |
| Console5 (USA) | [PS1/PS2 AV Multi Out plug](https://console5.com/store/sony-playstation-1-2-ps1-ps2-av-multi-out-plug-for-custom-rgb-cables-repair.html) | Conector avulso soldável, qualidade confirmada |
| eBay | [PS1 AV cables/adapters](https://www.ebay.com/b/Video-Game-AV-Cables-and-Adapters-for-Sony-PlayStation-1/171814/bn_73692602) | Buscar plug avulso |
| **Opção prática** | Cabo AV composto PS1 barato | Comprar cabo composite genérico PS1 no ML (~R$15) e reaproveitar o plug |

> **PS1 = PS2 = PSone:** mesmo conector AV nos três. Um cabo serve para todos.

#### ⚠️ Cuidados ao reutilizar cabo composite barato (PS1 e SNES)

Cabos composite/RCA baratos frequentemente **não conectam todos os pinos** do plug ao cabo — apenas os necessários para composite + áudio. Pinos RGB ficam presentes fisicamente no conector mas **não soldados ou sem contato**.

**Como verificar antes de usar:**
1. Abrir o plug (geralmente encaixe snap ou parafuso pequeno)
2. Checar se pinos R, G, B têm fios soldados — no PS1: pins 9 (B), 11 (R), 12 (G)
3. No SNES: pins 1 (R), 2 (G), 4 (B) devem ter contato
4. Medir com multímetro: continuidade entre pino do plug e terminal no cabo

**Se pinos RGB não estiverem soldados:** o conector ainda é aproveitável — soldar fios diretamente aos pinos no plug.

**Alternativa segura:** Console5 vende plugs avulsos "fully populated" com todos os pinos presentes e prontos para soldar.

### Conector MultiAV SNES (macho, para plug no console)

O conector é um card-edge 12 pinos de 0.1" passo dupla face — muito raro.

| Fornecedor | Link | Notas |
|---|---|---|
| AliExpress | [Multi AV SNES female connector DIY](https://www.aliexpress.com/item/1005008842958975.html) | Fêmea (para fazer extensão) |
| AliExpress (lote) | [2 sets SNES/N64/GCN 12pin connector](https://www.aliexpress.com/i/4000049095963.html) | Macho para cabo |
| eBay | [SNES MultiAV plug](https://www.ebay.com/itm/233655497140) | Importado, demora |
| Retro Access (USA) | [Connector Male AV Multi-Out SNES](https://retro-access.com/product/connector-male-snes/) | Melhor qualidade, frete caro |
| **Opção prática** | Cabo AV composto barato SNES | Comprar cabo genérico barato e reaproveitar o plug — mais fácil |

> **Recomendação:** comprar cabo AV composto genérico para SNES no Mercado Livre (~R$20) e usar o plug MultiAV dele. Cabo em si é lixo, mas o conector serve.

---

## Componentes eletrônicos — Brasil

### Lojas online nacionais

| Loja | URL | Observação |
|---|-----|---|
| GSV Eletrônica | gsveletronica.com.br | Tem 74HC4053 em estoque |
| Evatron | evatron.com.br | 74HC4053 SMD confirmado |
| Ponto da Eletrônica | pontodaeletronica.com.br | >13.000 itens, entrega rápida |
| Achei Componentes | acheicomponentes.com.br | SP, atacado e varejo |
| Mamute Eletrônica | mamuteeletronica.com.br | Arduino/ESP + componentes |

### Componentes por item

#### 74HCT4053 (mux analógico — mod board)

| Opção | Fornecedor | Notas |
|---|---|---|
| 74HC4053 DIP-16 | GSV Eletrônica | HC (não HCT) — threshold CMOS, ok para sinal 5V |
| 74HCT4053 DIP-16 | AliExpress | Buscar "74HCT4053 DIP" — confirmar HCT (threshold TTL ~1.4V) |
| 74HC4053 SMD | Evatron | Se preferir montar SMD |

> **HCT vs HC:** Para controle via fast blanking SCART (1–3V), o HCT é mais seguro (threshold ~1.4V). HC requer >2.5V para acionar — pode não funcionar com alguns consoles. Preferir HCT.

#### Capacitores eletrolíticos

| Valor | Uso | Onde comprar |
|---|-----|---|
| 220µF 6.3V ou 16V | Acoplamento RGB (SNES NTSC) | Qualquer loja nacional, muito comum |
| 47µF 16V | Acoplamento RGB (mod board) | Qualquer loja |
| 220µF 16V | Saturn — linha csync | Qualquer loja |
| 10µF 16V | Bulk decoupling mod board | Qualquer loja |
| 100nF cerâmico | Bypass VCC | Qualquer loja |

#### Resistores 1/4W

| Valor | Uso |
|---|-----|
| 820Ω | Divisor blanking (top) |
| 1kΩ | Divisor blanking (bottom) |
| 75Ω | Terminação RGB (mod board) |
| 10kΩ | Vários (bias, pull-up/down, BC547) |
| 1.5kΩ | Bias mod board |
| 470Ω | Saturn csync |

Resistores são commodity — qualquer loja nacional (Ponto da Eletrônica, GSV, etc.).

#### Transistor BC547 NPN

Disponível em qualquer loja de eletrônica nacional — ~R$0,30/unidade.  
Substituto: 2N2222, BC548, PN2222.

---

## Materiais de cabo

### Vias necessárias para cabo SCART completo

| Sinal | Qtd | Shield individual? | Impedância |
|---|-----|---|---|
| R, G, B | 3 | **Sim** — obrigatório | 75Ω |
| CSync | 1 | **Sim** — recomendado | 75Ω |
| Audio L, Audio R | 2 | Recomendado | ~600Ω |
| GND geral | 1 | Não (não blindado) | — |
| **Total** | **7** | 6 blindados + 1 nu | — |

### Opção 1 — Cabo VGA reutilizado (melhor custo-benefício)

Cabo VGA interno contém **3 coaxiais 75Ω individuais** (R, G, B) + fios extras não blindados.  
Com VGA de boa qualidade (cabo grosso):
- 3 coaxiais individuais → R, G, B
- Fios extras → Sync, Audio L, Audio R, GND
- Malha geral → shield externo

**Onde encontrar:** Goodwill / brechós de informática / sucata de TI. Cabo VGA grosso de monitor CRT é o ideal.  
**Custo:** praticamente zero.

### Opção 2 — Mini-Coax profissional (melhor qualidade)

| Produto | Fornecedor | Specs | Preço |
|---|---|---|---|
| Mini-Coax 75Ω — 6 blindados + 1 nu | [Retro Access](https://retro-access.com/product/mini-coax/) | 9mm OD, 7 condutores, 6 shields isolados | ~$3/pé (USA) |

Fabricado especificamente para cabos RGB retro. Qualidade broadcast. Frete dos EUA.

### Opção 3 — Cabo paralelo blindado (prática, menos ideal)

| Material | Onde comprar | Notas |
|---|---|---|
| Cabo impressora paralela blindado (DB25) | Mercado Livre | Múltiplos condutores blindados coletivamente — shield único, não individual |
| Cabo CFTV RG59 ×3 + cabo áudio | ML / eletrônicas | 3× RG59 para RGB, cabo áudio par trançado para L/R |

> Blindagem coletiva (um shield pra todos) é inferior — pode haver crosstalk entre RGB e áudio.  
> Aceitável para cabos curtos (<1m), ruim para comprimentos maiores.

### Componentes auxiliares de cabo

| Material | Onde comprar | Notas |
|---|---|---|
| Termocontrátil sortido | Mercado Livre / eletrônicas | Isolamento das soldas no SCART |
| Fio esmaltado 0.1mm | Eletrônicas especializadas | Para pontes em perfboard |
| Ferrite bead (núcleo ferrite) | Mercado Livre / AliExpress | Opcional — suprimir RFI se aparecer ruído |

---

## Fontes de referência consultadas

- [RetroRGB — SNES RGB Cables](https://retrorgb.com/snescsync.html)
- [RetroRGB — Genesis RGB Cables](https://retrorgb.com/genesisrgbcables.html)
- [Retro Access — connectors](https://retro-access.com/knowledge-center/connectors/)
- [sector.sunthar.com — SNES DIY SCART](https://sector.sunthar.com/guides/nintendo/snes/snes-diy-scart-cable.html)
- [Console SCART Diagrams — arcadecontrols](https://mirrors.arcadecontrols.com/eviltim/eviltim/gamescart/gamescart.htm)

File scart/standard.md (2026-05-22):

# SCART — Padrão Euro (IEC 60807-9 / BS EN 50049-1)

## Pinagem completa (conector fêmea, vista frontal)

```
         ┌─────────────────────────────────────────┐
         │  1   3   5   7   9  11  13  15  17  19  21 │
         │   2   4   6   8  10  12  14  16  18  20    │
         └─────────────────────────────────────────┘
```

| Pin | Sinal | Direção (TV) | Nível | Impedância |
|-----|---|---|---|---|
| 1 | Audio Out R | saída | 0.5 Vrms | <1kΩ |
| 2 | Audio In R | entrada | 0.5 Vrms | >10kΩ |
| 3 | Audio Out L + Mono | saída | 0.5 Vrms | <1kΩ |
| 4 | Audio GND | — | — | — |
| 5 | Blue GND | — | — | — |
| 6 | Audio In L + Mono | entrada | 0.5 Vrms | >10kΩ |
| 7 | **Blue In** | entrada | 0.7 Vpp | 75Ω |
| 8 | Switch / Widescreen | — | 0V=4:3, 12V=16:9 | — |
| 9 | Green GND | — | — | — |
| 10 | Clock Out (legado) | — | — | — |
| 11 | **Green In** | entrada | 0.7 Vpp | 75Ω |
| 12 | Data Out (legado) | — | — | — |
| 13 | Red GND | — | — | — |
| 14 | Data GND | — | — | — |
| 15 | **Red In** | entrada | 0.7 Vpp | 75Ω |
| 16 | **Fast Blanking** | entrada | 1–3V=RGB / 0–0.4V=composto | 75Ω |
| 17 | Video / Luma GND | — | — | — |
| 18 | Blanking GND | — | — | — |
| 19 | Composite Video Out | saída | 1 Vpp | 75Ω |
| 20 | **Composite Video In / Sync** | entrada | 1 Vpp | 75Ω |
| 21 | Shield / Chassis GND | — | — | — |

## Modos de operação

| Pin 16 (Blanking) | Pin 20 (sync) | Modo |
|---|---|---|
| 0–0.4V (ou aberto) | composite video | composite |
| 1–3V | csync ou composite | **RGB** ← usar este |

## Fast Blanking — como gerar

Fonte típica dos consoles é 5V (de pino de alimentação do conector AV). Precisa reduzir para 1–3V:

**Divisor resistivo simples:**
```
+5V ──┬── R1 (820Ω) ──┬── SCART pin 16
      │               │
      │              R2 (1kΩ) ── GND   → ~2.6V ✓
```

**Ou via pino de controle do console (quando disponível):**
Alguns consoles já fornecem sinal de blanking correto — verificar pinout específico.

## Sync — opções por ordem de preferência

1. **csync** — sync composto dedicado, melhor opção
2. **luma** (pino Y do S-Video) — sync em cima do sinal de luminância
3. **composite video** — sync extraído do sinal composto (aceito pela maioria dos CRTs)

> Para displays que exigem csync limpo (PVMs, scalers): usar sync stripper (LM1881 ou 74HC04).

## Aterramento — regra

Conectar **todos** os GNDs de vídeo ao aterramento comum do cabo:
- Pins 4 (audio), 5 (B), 9 (G), 13 (R), 17 (video), 18 (blanking), 21 (shield)

Malha do cabo blindado → pin 21 (shield), conectada em **uma ponta apenas** para evitar ground loop.

## Referências

- Fonte: [SCART pinout — PinoutGuide](https://pinoutguide.com/Audio-Video-Hardware/Scart_pinout.shtml)
- Fonte: [SCART specs — sector.sunthar.com](https://sector.sunthar.com/guides/crt-rgb-mod/scart.html)
- Fonte: [RGB Blanking — martin.hinner.info](http://martin.hinner.info/vga/scart.html)

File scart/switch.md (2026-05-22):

# Switch SCART RGB

**Função:** N consoles conectados simultaneamente → 1 entrada SCART na TV. Troca de fonte sem desconectar cabo.

```
Console 1 ──► [SCART IN 1] ┐
Console 2 ──► [SCART IN 2] ├── Switch ──► [SCART OUT] ──► TV
Console 3 ──► [SCART IN 3] ┘
Console 4 ──► [SCART IN 4]
```

---

## Tipos

### Passivo (chave mecânica)

Chave rotativa conecta pinos diretamente — sem eletrônica. Funciona mas carrega o sinal: cada entrada desconectada cria impedância paralela → atenuação e possível reflexão. Aceitável para 2–3 entradas, problemático com mais.

### Ativo (com amplificação)

Mux eletrônico + buffer de saída. Sinal regenerado — qualidade independente do número de entradas.

---

## Por que 74HC4053 não serve para wired-bus

4053 é SPDT: Y sempre conectado a A ou B, **nunca high-Z**. Se Y de múltiplas unidades em paralelo:

- Selecionado: Y → sinal ✓
- Não selecionados: Y → GND (ou input flutuando) → pull-down no barramento

Resultado: sinal atenuado ou curto. Não funciona para topologia wired-bus.

O 4053 é adequado apenas como **mux em árvore** (2:1 por estágio):

```
4 entradas, 6 sinais (R,G,B,sync,L,R):

Entrada 1 ─┐
Entrada 2 ─┤── 4053_A (2:1, 3ch) ──┐
Entrada 3 ─┤                        ├── 4053_C (2:1, 3ch) ──► R,G,B out
Entrada 4 ─┘── 4053_B (2:1, 3ch) ──┘
(repetir com 4053_D para sync+audio)
```

2 bits de controle → 4 entradas. Sem barramento compartilhado.

---

## Chip correto para wired-bus: SN74CBT3244

FET bus switch octal. Tem pino **OE#** (output enable ativo baixo) que coloca **todas as saídas em high-Z** quando desabilitado — permite barramento compartilhado real.

| Parâmetro | 74HC4053 | SN74CBT3244 |
|---|---|---|
| Tipo | Mux CMOS SPDT | FET bus switch |
| Ron típico | 100–200Ω | <5Ω |
| High-Z disponível | ✗ | ✓ (via OE#) |
| Canais | 3× 2:1 | 8× SPST |
| Uso em vídeo | Sofrível | Transparente |

**Topologia com CBT3244:**

- Um IC por entrada SCART (habilita/desabilita todos os sinais daquela entrada)
- Todas as entradas no mesmo barramento
- MCU controla OE# de cada IC — só um habilitado por vez
- Barramento → buffer de vídeo → saída

---

## Arquitetura típica de switch ativo completo

```
Console 1 ──► CBT3244 (OE# = LOW  → ativo) ──┐
Console 2 ──► CBT3244 (OE# = HIGH → high-Z) ──┤── barramento RGB+sync+audio
Console 3 ──► CBT3244 (OE# = HIGH → high-Z) ──┤         │
Console N ──► CBT3244 (OE# = HIGH → high-Z) ──┘         ▼
                                                     THS7374 (buffer 4ch)
                    MCU ──► OE# de cada IC               │
                    ▲                                     ▼
              IR remote /                          LM1881 (sync stripper)
              botões /                                    │
              fast blanking                               ▼
              detector                              SCART OUT → TV
```

### Chips de buffer e sync

| Chip | Função | Notas |
|---|---|---|
| THS7374 | Buffer vídeo 4ch + LPF | Regenera sinal após mux, filtro selecionável |
| THS7314/THS7316 | Buffer vídeo 3ch | Alternativa mais simples |
| LM1881 | Sync stripper | Extrai csync de composite ou luma |
| LMH1980 | Sync stripper alternativo | Auto-detecta tipo de sync |

### Auto-switch por fast blanking (pin 16 SCART)

Console ligado → pin 16 vai para 1–3V → comparador detecta → MCU comuta para essa entrada. Sem apertar botão.

Implementação simples: comparador LM393 ou transistor NPN em cada entrada monitorando pin 16.

---

## Projetos open source

### OSSW — Open SCART SWitch ⭐ ativo

**Repositório:** https://github.com/BinaryS010/ossw  
**Status:** alpha/protótipo funcional. Autor não vende kit, gerbers disponíveis para fabricação própria.

**Especificações:**
- 8 entradas SCART, 2 saídas SCART simultâneas (não testado)
- Euro SCART apenas (sem JP-21)
- Switching manual (auto-switch planejado, não implementado)
- Saída de áudio stereo via RCA

**Hardware principal:**
| Chip | Função |
|---|---|
| SN74CBT3244 | FET bus switch octal (mux das entradas) |
| THS7374 | Amp vídeo 4ch + LPF selecionável |
| LM1881 | Sync stripper + seleção csync/composite/luma |
| ATSAMD21J18A | ARM Cortex-M0 (controle, UI, IR) |
| 24LC64 | EEPROM 64Kb (salva configuração) |
| TSOP38238 | Receptor IR 38kHz |
| SN74HC14 | Debounce hardware dos botões |

**PCB:** 4 camadas (~400×130mm) + placa filha LCD 2 camadas. Case acrílico cortado a laser.  
**Alimentação:** 7.5V DC 1A, conector 2.5mm barrel jack centro-positivo.

**Limitações:**
- Switching somente manual (auto por blanking não implementado)
- Sync TTL pode danificar dispositivos upstream — usar apenas cabos com sync 75Ω atenuado
- Firmware: upgrade requer programador Atmel ICE

---

### Osmagtor/8-to-4-scart-switch ⭐ ativo (atualizado abr/2026)

**Repositório:** https://github.com/Osmagtor/8-to-4-scart-switch  
**Status:** passivo, funcional, PCB KiCAD disponível. Sem eletrônica ativa.

**Especificações:**
- 8 entradas, 4 saídas simultâneas — diferencial raro
- Passivo: spring-loaded push buttons mecânicos (mesmo mecanismo de switches baratos de hardware store)
- Seleção RGB via botão dedicado (controla pin 16)
- Diodos 1N4148 em pin 8 (aspect ratio) e pin 16 (blanking) para evitar feedback entre entradas
- Entradas RCA: injeção de áudio estéreo (ex: Mega Drive headphone jack) e lightgun
- Saídas RCA: para captura ou monitor externo

**Como funciona internamente:**
```
Cada spring-loaded button commuta 6 sinais de uma entrada:
  SCART pins: 2 (R audio), 6 (L audio), 7 (B), 11 (G), 15 (R), 20 (composite/sync)
Pin 8 e pin 16: roteados via traces separados com diodos 1N4148
  → impede que uma entrada "alimente" outra quando múltiplos botões pressionados
```

**Limitações:**
- Passivo: sem buffer → alguma degradação com muitas entradas
- Sem auto-switch por blanking
- STL para case não incluído

---

### mrehkopf/WuetendesSeil — firmware para Hydra SCART

**Repositório:** https://github.com/mrehkopf/WuetendesSeil  
**Status:** ativo (last commit 2025-09). Firmware replacement para o Hydra SCART switch v1 (produto comercial).

**Melhorias sobre firmware original:**
- Seleção manual de input (botão do meio alterna auto/manual)
- Busca rápida de input — sem running light animation
- PWM dos LEDs desabilitado (eliminava buzzing no áudio)
- Tolerância de 2s para perda de sinal (evita troca acidental no reset do console)

> Hydra é produto comercial com hardware fechado. Firmware open source apenas.

---

### gbrown128/SCARTer — crosspoint matrix (abandonado)

**Repositório:** https://github.com/gbrown128/SCARTer  
**Status:** abandonado desde 2018. Interessante pelo chip usado.

12 entradas × 3 saídas com **FMS6501** — crosspoint matrix de vídeo 12×9. Permite qualquer entrada para qualquer saída simultaneamente. ATMEGA328 como controlador. Não chegou a ser finalizado.

---

### Numbski/open-source-scart-switch (2017, inativo)

**Repositório:** https://github.com/Numbski/open-source-scart-switch  
3 entradas, manual. Chips: CBT3244 + LMH1980. Sem firmware documentado. Não recomendado — desatualizado.

---

## Como switch passivo barato funciona (dissecado)

O projeto Osmagtor documenta o mecanismo dos switches de R$20–50 vendidos em hardwares stores e AliExpress:

- Spring-loaded push buttons de 18 pinos (2×9): cada botão commuta 6 sinais da sua entrada
- Mecanismo físico garante só um botão pressionado por vez (como botões de rádio vintage)
- Todas as saídas dos botões conectadas em barramento comum → saída SCART
- Pin 8 e pin 16 em traces separados com diodos 1N4148 (sem passar pelos botões) — evita feedback
- Botão RGB adicional corta/passa o sinal RGB (controla pin 16)

**Degradação:** sem high-Z real no barramento — entradas não selecionadas ficam "penduradas". Aceitável para 3–4 entradas, perceptível com 8+.

---

## Aplicação: NES/SNES/N64/PS1/PS2 na KV-21FS140

5 consoles → 1 entrada SCART (via mod CN004 da TV).

OSSW cobre com folga (8 entradas). Opção mais simples: switch de 4–5 entradas com CBT3244 + THS7374 + LM1881.

| Console | RGB nativo | Obs |
|---|---|-----|
| SNES | ✓ | Direto, caps 220µF no cabo |
| PS1 | ✓ | Direto, caps 220µF no cabo |
| PS2 | ✓ | Direto, sem caps no cabo |
| N64 | ✗ | Requer mod RGB interno |
| NES | ✗ | Requer NESRGB ou PPU-LITE |

Todos operam em 240p/480i — 100% compatíveis com 15kHz do KV-21FS140.

---

## Opções comerciais — AliExpress e lojas retro

### AliExpress — switches passivos baratos

Switches mecânicos passivos vendidos em AliExpress por ~$5–25. Funcionam, qualidade variável.

**Links de busca diretos:**

| Busca | Link |
|---|---|
| SCART switch geral | [aliexpress.com/w/wholesale-scart-switch.html](https://www.aliexpress.com/w/wholesale-scart-switch.html) |
| SCART switcher 4 port | [aliexpress.com — "scart switcher 4 port"](https://www.aliexpress.com/wholesale?SearchText=scart+switcher+4+port) |
| Euro SCART selector | [aliexpress.com — "euro scart selector"](https://www.aliexpress.com/wholesale?SearchText=euro+scart+selector) |
| SCART switch RGB | [aliexpress.com — "scart switch rgb"](https://www.aliexpress.com/wholesale?SearchText=scart+switch+rgb) |

> AliExpress bloqueia scraping automatizado — links de busca são mais confiáveis que links diretos de produto (expiram ou mudam de vendedor).

**O que esperar:**
- Spring-loaded push buttons mecânicos (mesmo mecanismo do Osmagtor acima)
- Sem buffer ativo — sinal pode degradar com muitas entradas
- Sem auto-switch
- Qualidade aceitável para 2–3 consoles, problemática para 5+
- Muitos não comutam todos os 21 pinos — verificar se comuta R/G/B/sync e não só composite+audio

> ⚠️ Switches baratos de AliExpress frequentemente **omitem pin 16 (blanking)** do barramento — TV pode não ativar modo RGB automaticamente. Testar antes de comprar.

### gSCARTsw — Lotharek (comercial, ativo, recomendado)

**Loja:** https://lotharek.pl (buscar "gSCARTsw")  
Produto polonês, enviado para o Brasil via correios. Referência da comunidade retro.

- 8 entradas, 2 saídas
- Ativo com buffer — sinal limpo independente do número de entradas
- **Auto-switch por fast blanking** (pin 16) — troca automático ao ligar console
- Suporta todos os 21 pinos SCART incluindo pin 8 e pin 16
- Firmware: closed source, hardware fechado (firmware replacement open source: WuetendesSeil acima)

**Custo:** ~€60–80 + frete internacional (~€15–25 para Brasil).

### Hydra SCART Switch (comercial)

Produto da comunidade retro europeia. Auto-switch por blanking, 8 entradas. Hardware fechado, firmware substituível pelo WuetendesSeil (ver acima).

### Keene Electronics SCART Switch (comercial UK)

Switches SCART ativos de qualidade, 4–8 entradas. Difícil de encontrar fora da Europa.

---

## Recomendação para o setup NES/SNES/N64/PS1/PS2

| Opção | Custo | Auto-switch | Buffer | DIY |
|---|---|---|---|-----|
| Switch passivo AliExpress | ~$10 | ✗ | ✗ | ✗ |
| Osmagtor PCB (fabricar) | ~$5 PCB + ~$10 componentes | ✗ | ✗ | ✓ |
| OSSW (fabricar, 4 camadas) | ~$40 PCB + ~$50 componentes | ✗ (planejado) | ✓ THS7374 | ✓ |
| gSCARTsw Lotharek | ~$90 com frete | ✓ | ✓ | ✗ |

Para 5 consoles sem auto-switch: switch passivo de AliExpress funciona. Para uso confortável com auto-switch: gSCARTsw é o mais maduro e testado pela comunidade, mas caro. OSSW é a melhor alternativa DIY ativa.

---

## Referências

- [OSSW — GitHub BinaryS010](https://github.com/BinaryS010/ossw)
- [Osmagtor/8-to-4-scart-switch — GitHub](https://github.com/Osmagtor/8-to-4-scart-switch)
- [WuetendesSeil firmware Hydra — GitHub mrehkopf](https://github.com/mrehkopf/WuetendesSeil)
- [SN74CBT3244 datasheet — TI](https://www.ti.com/product/SN74CBT3244)
- [THS7374 datasheet — TI](https://www.ti.com/product/THS7374)
- [LM1881 datasheet — TI](https://www.ti.com/product/LM1881)
- [gSCARTsw — Lotharek](https://lotharek.pl) — referência comercial de qualidade
- [SCART Switches — RetroRGB](https://retrorgb.com/scartswitches.html)

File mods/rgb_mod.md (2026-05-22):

# RGB Mod — KV-21FS140 (Chassis BX1S)

**Status:** Documentado, não executado  
**Dificuldade:** Média — sem mexer em HV se seguir procedimento correto

---

## Contexto

IC001 (TDA12009H) **não tem** pinos de entrada RGB analógico externo para SCART.  
Sinais SCART presentes no IC001 são apenas:
- `SCARTFBL/A16` — fast-blanking (detecta presença de SCART)
- `CVBSO` — composto do SCART (não RGB)
- `SCARTHPR/L` — áudio do SCART

O conector J901 (11P, borda direita da placa, D13/14) carrega **vídeo componente (Y/Pb/Pr)** + áudio, não RGB.

**Único ponto de injeção RGB viável: CN004 (A Board) / CN701 (C Board).**

---

## Caminho do sinal RGB atual

```
IC001 pin87(R) / pin86(G) / pin85(B)
    → CN004 (A Board, 7 pinos)
    → [cabo]
    → CN701 (C Board, 7 pinos)
    → IC751 (TDA6108AJF)
    → Cátodos R/G/B do CRT
```

### Pinagem CN701 (C Board) / CN004 (A Board)

| Pin | Sinal |
|-----|---|
| 1 | GND |
| 2 | B OUT |
| 3 | G OUT |
| 4 | R OUT |
| 5 | GND |
| 6 | IK (AKB sensing) |
| 7 | 9V |

### Resistores de entrada na C Board (antes do IC751)

| Ref | Valor | Canal |
|-----|---|---|
| R757 | 1kΩ | R |
| R756 | 1kΩ | G |
| R758 | 1kΩ | B |
| R752 | 680Ω | R (da A Board) |
| R753 | 680Ω | G |
| R754 | 680Ω | B (não montado neste modelo) |

---

## Esquema do mod

```
                    ┌─────────────────────────────┐
                    │        MOD BOARD            │
                    │                             │
 Fonte RGB          │  75Ω    100µF   R_bias      │
 R (0–0.7V) ───────┤──┤├──┤├──────┤>─────────────┼──┐
 G (0–0.7V) ───────┤──┤├──┤├──────┤>─────────────┼──┤  74HCT4053 ──> CN004
 B (0–0.7V) ───────┤──┤├──┤├──────┤>─────────────┼──┘     │
                    │                             │         │
 Enable (5V=RGB) ──┼─────────────────────────────┼─── pino S (controle)
 Enable (0V=TV)    │                             │
                    │                             │
 IC001 RGB out ────┼─────────────────────────────┼──> CN004 (passthrough quando S=0)
                    └─────────────────────────────┘
```

### Chip de chaveamento: 74HCT4053

- 3× mux analógico 2:1, single supply 5V
- Um pino de controle (S) chave os 3 canais simultaneamente
- S = LOW (0V) → passa sinal IC001 (TV normal)
- S = HIGH (5V) → passa RGB externo

---

## Detecção automática + chave manual

### Detecção automática via Fast Blanking (SCART pino 16)

Cabos SCART RGB enviam 1–3V no pino FB (fast blanking) quando console está ativo.
Esse sinal controla o pino S do 74HCT4053 automaticamente via transistor NPN.

```
Pino FB (SCART p16)
    │
    R1 (10kΩ)
    │
    Base ── Q1 (BC547 / 2N2222)
    Emissor ── GND
    Coletor ── pino S do 74HCT4053
              └── R2 (10kΩ pull-down para GND)
```

- FB alto (console ativo) → Q1 conduz → S=HIGH → RGB ativo
- FB baixo / cabo desconectado → Q1 corta → S=LOW → TV normal

**Requisito:** cabo SCART deve conectar pino 16 (FB). Verificar no cabo utilizado.

---

### Chave manual de 3 posições

Permite forçar modo independente do FB — útil para debug, consoles sem FB, ou forçar TV normal sem desconectar cabo.

| Posição | Comportamento | Conexão do pino S |
|---|---|---|
| AUTO | FB controla via Q1 | Saída do coletor de Q1 |
| RGB | Força RGB sempre | VCC 5V fixo |
| TV | Força TV normal sempre | GND fixo |

```
                    ┌─── AUTO: coletor Q1 (saída FB)
Pino S (74HCT4053) ─┤─── RGB:  VCC 5V
                    └─── TV:   GND
```

Chave: rotativa 3 posições ou alavanca ON-OFF-ON (SP3T). Custo ~R$5–10.

### Alimentação 5V para o mod

**Ponto de coleta:** IC604 (KIA7805API) pino 3 — saída regulada 4.8V.

IC604 fica na PSU board (Block 003), fora do RF shield do IC001. TO-220, pino 3 = saída 5V. Solda fio direto no pino ou no capacitor de filtro de saída adjacente.

Não usar CN004 pino 7 (9V) — exigiria regulador adicional.

### Componentes adicionais

| Componente | Qtd | Observação |
|---|-----|---|
| Transistor NPN BC547 ou 2N2222 | 1x | Driver FB |
| Resistor 10kΩ 1/4W | 2x | Base (R1) e pull-down (R2) |
| Chave SP3T (3 posições) | 1x | AUTO / RGB / TV |

### Nível de sinal e acoplamento

| Parâmetro | IC001 out | Fonte externa | IC751 espera |
|---|---|---|---|
| DC offset | ~1.5V | ~0V | ~0.7V |
| Swing | ~0.7Vpp | ~0.7Vpp | ~0.7Vpp |

Solução: cap de acoplamento (100µF) remove DC da fonte + resistor para referência de ~0.7V via divisor resistivo (ex: 1kΩ para 1.5V, 680Ω para GND → ~0.8V de bias).

---

## Conexões completas do mod

| Sinal da fonte | Conecta em | Observação |
|---|---|---|
| CSYNC (ou composite com sync) | J901 pin 1 (V1) | IC001 trava deflexão aqui |
| R (0–0.7V, 75Ω) | CN004 pin 4 via 74HCT4053 | Com cap + bias |
| G (0–0.7V, 75Ω) | CN004 pin 3 via 74HCT4053 | Com cap + bias |
| B (0–0.7V, 75Ω) | CN004 pin 2 via 74HCT4053 | Com cap + bias |
| Audio L | J901 pin 5 (L1) | AV1 áudio esquerdo |
| Audio R | J901 pin 4 (R1) | AV1 áudio direito |
| Enable/FB | 74HCT4053 pino S | LOW=TV, HIGH=RGB |
| GND | Chassis / CN004 pin 1 ou 5 | Referência comum |

**TV deve estar no modo AV1** para receber sync e áudio da fonte externa.

---

## Compatibilidade com videogames

### Funciona nativamente (saída 15kHz)

| Console | Resolução típica | Observação |
|---|---|---|
| SNES / Super Famicom | 224p / 240p / 448i | RGB nativo, perfeito |
| Mega Drive / Genesis | 224p / 240p | RGB nativo, perfeito |
| Master System | 192p / 224p | RGB nativo |
| Neo Geo (AES/MVS) | 240p | RGB nativo |
| PlayStation 1 | 240p / 480i | Ambos 15kHz, troca transparente |
| Saturn | 240p / 480i | Ambos 15kHz |
| N64 | 240p / 480i | Requer mod RGB interno |
| GameCube | 480i | Modo 480i = 15kHz |
| Dreamcast | 240p / 480i | Via SCART, não VGA |

### Problemático

| Console | Problema |
|---|---|
| PS2 | Muitos jogos forçam 480p (31kHz) — imagem some nesses momentos |
| GameCube | 480p mode = 31kHz, não funciona |
| Dreamcast VGA | 31kHz, não funciona |
| Xbox / PS3+ | 31kHz+, incompatível sem upscaler |

### Mudança de resolução em tempo real

- **Mesma freq H (ex: PS1 trocando 240p ↔ 480i):** IC001 re-trava automaticamente. Sem problema.
- **Muda freq H (15kHz → 31kHz):** IC001 perde sync. Imagem some até voltar a 15kHz. Sem dano.
- **Muda largura de pixels (ex: MD 256↔320):** Mesma freq H, só muda pixels ativos. IC001 fica travado. Funciona.

### Solução para fontes 31kHz

Interpor um **RetroTINK 2x-Mini** ou similar entre console e TV:
```
Console → RetroTINK 2x-Mini → [480p → 480i 15kHz] → TV
```
Adiciona ~1 frame de latência. Permite qualquer console independente de resolução.

---

## Segurança

### Para a TV

| Risco | Mitigação |
|---|---|
| Overdrive do CRT por nível alto | 75Ω terminação + cap acoplamento corretos |
| AKB ler nível errado durante bypass | Causa variação de brilho por alguns frames — sem dano |
| Mod reversível | CN004/CN701 é conector físico — desconecta e volta ao original |

### Para você — PERIGOS DO CRT

> **ATENÇÃO: A TV mantém tensões letais após desligar da tomada.**

| Tensão | Local | Tempo de descarga |
|---|---|---|
| ~25kV | Ânodo do CRT (capa vermelha) | **horas a dias** |
| ~200V | C Board — alimentação IC751 | minutos |
| ~135V | B+ na A Board | minutos |

**Procedimento obrigatório antes de abrir a TV:**

1. Desligar da tomada
2. Aguardar 5 minutos mínimo
3. Descarregar ânodo do CRT:
   - Resistor **10MΩ 2W** em série com fio isolado
   - Inserir ponta sob a capa vermelha do ânodo
   - Outra ponta no chassis metálico da TV
   - Segurar pelo cabo, nunca pelo resistor
   - Aguardar até parar faíscas/som de descarga
4. Só então trabalhar

**Este mod específico (CN004/CN701)** fica na A Board, longe do FBT e ânodo. Com TV desligada e ânodo descarregado, área segura para trabalhar. Não é necessário mexer perto do HV.

---

## Lista de materiais

| Componente | Qtd | Observação |
|---|-----|---|
| 74HCT4053 (DIP ou SMD) | 1x | Mux analógico 3× 2:1 |
| Resistor 75Ω 1/4W | 3x | Terminação RGB |
| Capacitor eletrolítico 100µF 16V | 3x | Acoplamento AC |
| Resistor bias ~1kΩ 1/4W | 3x | Bias para IC751 |
| Resistor bias ~680Ω 1/4W | 3x | Divisor de bias |
| Conector compatível CN004/CN701 | 1x | Verificar passo e tipo in situ |
| Cabo para sinais RGB | — | Blindado |
| Chave ou transistor de controle | 1x | Para pino S do 74HCT4053 |

---

## Referências internas

- `circuits/cboard_rgb_amp.md` — IC751, CN701, resistores de entrada R/G/B
- `circuits/block006_av_inputs.md` — J901 pinagem, entradas AV1/SCART
- `circuits/voltage_waveform_table.md` — IC001 pinos 85/86/87 tensões
- `circuits/block001_processor.md` — IC001 TDA12009H visão geral

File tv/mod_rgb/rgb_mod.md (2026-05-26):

# RGB Mod — KV-21FS140 (Chassis BX1S)

**Status:** Documentado, não executado  
**Dificuldade:** Média — sem mexer em HV se seguir procedimento correto

---

## Contexto

IC001 (TDA12009H) **não tem** pinos de entrada RGB analógico externo para SCART.  
Sinais SCART presentes no IC001 são apenas:
- `SCARTFBL/A16` — fast-blanking (detecta presença de SCART)
- `CVBSO` — composto do SCART (não RGB)
- `SCARTHPR/L` — áudio do SCART

O conector J901 (11P, borda direita da placa, D13/14) carrega **vídeo componente (Y/Pb/Pr)** + áudio, não RGB.

**Único ponto de injeção RGB viável: CN004 (A Board) / CN701 (C Board).**

---

## Caminho do sinal RGB atual

```
IC001 pin87(R) / pin86(G) / pin85(B)
    → CN004 (A Board, 7 pinos)
    → [cabo]
    → CN701 (C Board, 7 pinos)
    → IC751 (TDA6108AJF)
    → Cátodos R/G/B do CRT
```

### Pinagem CN701 (C Board) / CN004 (A Board)

| Pin | Sinal |
|-----|---|
| 1 | GND |
| 2 | B OUT |
| 3 | G OUT |
| 4 | R OUT |
| 5 | GND |
| 6 | IK (AKB sensing) |
| 7 | 9V |

### Resistores de entrada na C Board (antes do IC751)

| Ref | Valor | Canal |
|-----|---|---|
| R757 | 1kΩ | R |
| R756 | 1kΩ | G |
| R758 | 1kΩ | B |
| R752 | 680Ω | R (da A Board) |
| R753 | 680Ω | G |
| R754 | 680Ω | B (não montado neste modelo) |

---

## Esquema do mod

```
                    ┌─────────────────────────────┐
                    │        MOD BOARD            │
                    │                             │
 Fonte RGB          │  75Ω    100µF   R_bias      │
 R (0–0.7V) ───────┤──┤├──┤├──────┤>─────────────┼──┐
 G (0–0.7V) ───────┤──┤├──┤├──────┤>─────────────┼──┤  74HCT4053 ──> CN004
 B (0–0.7V) ───────┤──┤├──┤├──────┤>─────────────┼──┘     │
                    │                             │         │
 Enable (5V=RGB) ──┼─────────────────────────────┼─── pino S (controle)
 Enable (0V=TV)    │                             │
                    │                             │
 IC001 RGB out ────┼─────────────────────────────┼──> CN004 (passthrough quando S=0)
                    └─────────────────────────────┘
```

### Chip de chaveamento: opções

#### 74HCT4053 — recomendado

- 3× mux analógico 2:1, single supply 5V
- Um pino de controle (S) chave os 3 canais simultaneamente
- S = LOW (0V) → passa sinal IC001 (TV normal)
- S = HIGH (5V) → passa RGB externo
- Ron ~80–120Ω, BW ~100MHz, DIP-16 disponível
- Entrada de controle compatível com TTL (threshold ~1.4V) — FB de console aciona direto

#### Alternativas drop-in (mesmo pinout DIP-16)

| Chip | Diferença | Quando usar |
|---|---|---|
| **74HC4053** | Threshold de controle CMOS (~2.5V) em vez de TTL | Se sinal de controle for 3.3V ou CMOS |
| **CD4053** | CMOS 4000 original — Ron ~300Ω a 5V, BW menor | Só se não achar HCT/HC — Ron mais alto mas aceitável no trecho curto |
| **MAX4053** | Ron ~30Ω, melhor crosstalk, mesmo pinout | Melhor performance, mesma montagem |

#### Alternativas SMD (performance superior, mais difícil de soldar)

| Chip | Package | Ron | Vantagem |
|---|---|-----|---|
| TS3A5017 (TI) | SOT-23-8 | ~3Ω | Ron muito baixo, single supply |
| ADG712 (AD) | SOIC-16 | ~5Ω | Baixo distorção, precisão |
| TS5A3159 (TI) | SOT-23-6 | ~1Ω | Single channel — precisa 3x |

**Para este projeto:** 74HCT4053 DIP é suficiente. Ron de 100Ω no trecho curto interno introduz atenuação de ~0.06% com carga de 1kΩ+680Ω — imperceptível.

---

## Detecção automática + chave manual

### Detecção automática via Fast Blanking (SCART pino 16)

Cabos SCART RGB enviam 1–3V no pino FB (fast blanking) quando console está ativo.
Esse sinal controla o pino S do 74HCT4053 automaticamente via transistor NPN.

```
Pino FB (SCART p16)
    │
    R1 (10kΩ)
    │
    Base ── Q1 (BC547 / 2N2222)
    Emissor ── GND
    Coletor ── pino S do 74HCT4053
              └── R2 (10kΩ pull-down para GND)
```

- FB alto (console ativo) → Q1 conduz → S=HIGH → RGB ativo
- FB baixo / cabo desconectado → Q1 corta → S=LOW → TV normal

**Requisito:** cabo SCART deve conectar pino 16 (FB). Verificar no cabo utilizado.

---

### Chave manual de 3 posições

Permite forçar modo independente do FB — útil para debug, consoles sem FB, ou forçar TV normal sem desconectar cabo.

| Posição | Comportamento | Conexão do pino S |
|---|---|---|
| AUTO | FB controla via Q1 | Saída do coletor de Q1 |
| RGB | Força RGB sempre | VCC 5V fixo |
| TV | Força TV normal sempre | GND fixo |

```
                    ┌─── AUTO: coletor Q1 (saída FB)
Pino S (74HCT4053) ─┤─── RGB:  VCC 5V
                    └─── TV:   GND
```

Chave: rotativa 3 posições ou alavanca ON-OFF-ON (SP3T). Custo ~R$5–10.

### Alimentação 5V para o mod

**Ponto de coleta:** IC604 (KIA7805API) pino 3 — saída regulada 4.8V.

IC604 fica na PSU board (Block 003), fora do RF shield do IC001. TO-220, pino 3 = saída 5V. Solda fio direto no pino ou no capacitor de filtro de saída adjacente.

Não usar CN004 pino 7 (9V) para alimentar o mod board 5V — exigiria regulador adicional.  
**Opção B (LM1203N):** CN004 pino 7 (9V) pode alimentar o LM1203N diretamente (margem reduzida) ou via módulo boost MT3608 para 12V.

### Componentes adicionais

| Componente | Qtd | Observação |
|---|-----|---|
| Transistor NPN BC547 ou 2N2222 | 1x | Driver FB |
| Resistor 10kΩ 1/4W | 2x | Base (R1) e pull-down (R2) |
| Chave SP3T (3 posições) | 1x | AUTO / RGB / TV |

### Nível de sinal e acoplamento

| Parâmetro | IC001 out | Fonte externa | IC751 espera |
|---|---|---|---|
| DC offset | ~1.5V | ~0V | ~0.7V |
| Swing | ~0.7Vpp | ~0.7Vpp | ~0.7Vpp |

Fonte externa tem DC em 0V e swing de ~0.35Vpp no ponto de terminação (divisor 75Ω+75Ω). Precisa de ganho ×2 + acoplamento + bias antes do mux.

Duas opções de implementação:

---

### Opção A — Op-amp (TLV2374) + componentes discretos

**Alimentação:** 5V do IC604. Componentes comuns, fáceis de encontrar.

#### Cadeia de sinal por canal

```
Fonte RGB
(0–0.7V, 75Ω)
     │
     ├──[R_term 75Ω]── GND               ← termina linha → ~0.35Vpp no nó
     │
     ├──[C_in 47µF 16V]                  ← remove DC da fonte
     │         │
     │    [R_a 33kΩ]── 5V  ┐
     │         │            ├── virtual GND ~1.16V (compartilhado R/G/B)
     │    [R_b 10kΩ]── GND ┘
     │         │ (+ C_vgnd 10µF em paralelo com R_b)
     │
     [TLV2374 — não-inversor, alimentado a 5V]
          (+) = ~1.16V + sinal AC
          (−) conectado à saída via R_f (10kΩ) e ao GND via R_g:
          R_g = R_gmin(5kΩ) + R_wb(trimpot 0–1kΩ) + R_contraste(0–10kΩ, seção pot 3-gang)
          Ganho = 1 + 10k / (5k + R_wb + R_contraste)
          Nominal (R_wb=0, R_contraste=5kΩ): ganho = 2.0 → 0.35×2 = 0.70Vpp ✓
          DC saída = 1.16V × ganho (máx 3.48V a ganho=3 — dentro do rail 5V ✓)
     │
     ├──[C_out 47µF 16V]                 ← remove DC do op-amp (~1.16V×ganho)
     │
     ├──[R_top 10kΩ]── 5V    ┐
     │                        ├── divisor de bias de brilho
     ├──[R_bmin 470Ω]─┐       │
     │         [pot_brightness 2kΩ lin]── GND
     │                 │
     │          bias DC ~0.22–0.99V (compartilhado R/G/B)
     │
     └──── entrada do 74HCT4053 (canal externo)

IC001 RGB out ──────────── entrada do 74HCT4053 (canal TV)
74HCT4053 saída ────────────────────────────────────────> CN004 pin R/G/B
```

#### Contraste — ganho do op-amp

`Ganho = 1 + R_f / (R_gmin + R_wb + R_contraste)`

| R_contraste | R_wb | Ganho | Swing saída | DC saída op-amp | Headroom (5V) |
|---|---|---|---|---|---|
| 0Ω (máx) | 0Ω | 3.00× | 1.05Vpp | 3.48V → pico 4.0V | 1.0V ✓ |
| 5kΩ (meio) | 0Ω | 2.00× | 0.70Vpp ✓ | 2.32V → pico 2.67V | 2.33V ✓ |
| 10kΩ (mín) | 0Ω | 1.67× | 0.58Vpp | 1.94V → pico 2.23V | 2.77V ✓ |
| 5kΩ | 1kΩ | 1.83× | 0.64Vpp | 2.13V → pico 2.45V | 2.55V ✓ |

Ponto nominal: R_contraste ≈ 5kΩ (meio do pot). White balance trim ajusta ganho ±8% por canal.

> **Erro anterior corrigido:** virtual GND em 2×10kΩ (2.5V) colocaria DC de saída em 5V exatos a ganho=2 — clipping garantido. Correto é 33kΩ+10kΩ → ~1.16V.

#### Brilho — bias compartilhado

`V_bias = 5V × (R_bmin + pot) / (R_top + R_bmin + pot)`

| pot_brightness | V_bias | Efeito |
|---|---|---|
| 0Ω | ~0.22V | Imagem escura, pretos esmagados |
| ~900Ω | ~0.59V | Neutro — equivale ao IC001 nominal |
| 2kΩ | ~0.99V | Imagem clara, pretos elevados |

R_bmin=470Ω evita bias=0V. Um pot, 3 canais simultâneos — sem desvio de cor.

#### Polaridade dos capacitores eletrolíticos

| Cap | Polo + | Polo − | Tensão típica |
|-----|---|---|---|
| C_in | lado op-amp (1.16V) | lado fonte (~0V) | ~1.16V |
| C_out | lado op-amp (2.3V–3.5V) | lado bias (0.2V–1.0V) | ~1.3V–3.3V |

#### Componentes Opção A — por canal (×3)

| Componente | Valor | Função |
|---|---|---|
| R_term | 75Ω 1/4W | Terminação 75Ω da fonte |
| C_in | 47µF 16V eletrolítico | Acoplamento — remove DC da fonte |
| C_out | 47µF 16V eletrolítico | Acoplamento — remove DC do op-amp |
| R_gmin | 5kΩ 1/4W | Define ganho máximo (×3 com pot=0) |
| R_f | 10kΩ 1/4W | Resistor de realimentação |
| R_wb | trimpot 1kΩ multivolta | White balance por canal (ajuste único) |
| R_top | 10kΩ 1/4W | Divisor de bias, lado 5V |
| R_bmin | 470Ω 1/4W | Bias mínimo |

#### Componentes Opção A — globais (×1)

| Componente | Valor | Função |
|---|---|---|
| TLV2374 ou LMV324 | DIP-14 ou SOP-14 | Quad op-amp single-supply 5V |
| R_a virtual GND | 33kΩ 1/4W | Divisor virtual GND (lado 5V) |
| R_b virtual GND | 10kΩ 1/4W | Divisor virtual GND (lado GND) → ~1.16V |
| C_vgnd | 10µF 16V eletrolítico | Filtra ruído no nó virtual GND |
| pot_brightness | 2kΩ linear | Brilho — 1 pot, 3 canais |
| pot_contraste | 10kΩ linear 3-gang | Contraste — 3 seções, mesmo eixo |
| C_bypass VCC 74HCT4053 | 100nF cerâmico | Desacoplamento próximo ao chip |
| C_bypass VCC op-amp | 100nF cerâmico | Desacoplamento próximo ao TLV2374 |
| C_bulk VCC | 10µF eletrolítico | Bulk decoupling 5V |

---

### Opção B — LM1203N (chip dedicado de vídeo RGB)

**Chip:** National Semiconductor LM1203N, 28-pin DIP.  
**Alimentação:** 12V (preferencial) ou 9V do CN004 pino 7 (margem reduzida).  
Projetado especificamente para pré-amplificação RGB de monitores CRT — contraste e white balance nativos no chip.

#### Arquitetura interna relevante

| Função | Pinos | Método |
|---|---|---|
| Entradas RGB | 4 (R), 6 (G), 9 (B) | Entrada diferencial com clamp |
| Saídas RGB | 25 (R), 20 (G), 16 (B) | Corrente para driver de saída |
| Contraste | 12 | Tensão 0V–V_ref → atenuador resistivo interno igualado |
| Brilho (black level) | 14 (CLAMP GATE) | Pulso de blanking trava o nível de preto |
| White balance (drive) | 27 (R), 22 (G), 18 (B) | Trimpot por canal — ajusta ganho individual |
| White balance (cutoff) | 26 (R), 21 (G), 17 (B) | Ajusta ponto de corte de preto por canal |
| Clamp caps | 5 (R), 8 (G), 10 (B) | Cap externo 0.1µF — segura DC de preto |
| VREF saída | 11 | Referência interna (~1.2V) — usar para divisor de contraste |
| VCC | 1, 13, 23, 28 | Alimentação — todos conectar ao 12V |
| GND | 7 | Ground |

#### Cadeia de sinal (Opção B)

```
Fonte RGB
(0–0.7V, 75Ω)
     │
     ├──[R_term 75Ω]── GND          ← ~0.35Vpp após terminação
     │
     ├──[C_in 100nF film]            ← acoplamento AC (chip espera sinal sem DC)
     │
     [LM1203N pino R/G/B in]
          Ganho interno ajustado pelos pinos DRIVE (trimpots)
          Contraste via pino 12 (0V = mín, VREF = máx)
          Brilho via CLAMP GATE (pino 14) + CSYNC
     │
     [LM1203N pinos R/G/B out → 25/20/16]
     │
     ├──[R_out 1kΩ]                  ← adapta saída de corrente para tensão
     │
     └──── entrada do 74HCT4053 (canal externo)
```

> **Nota nível de saída:** LM1203N saída é corrente. Com 1kΩ de carga → tensão. Ajustar R_out ou trimpot DRIVE para obter ~0.7Vpp na entrada do 74HCT4053. Verificar com osciloscópio na primeira calibração.

#### Contraste (Opção B)

Pino 12 (CONTRAST): tensão de 0V (mínimo contraste) até V_ref/pino 11 (máximo).  
Pot simples de 10kΩ entre GND e VREF (pino 11), wiper no pino 12.  
**Um pot, 3 canais igualmente — atenuadores internos são igualados pelo fabricante.**

#### Brilho (Opção B)

CLAMP GATE (pino 14) requer pulso de blanking para travar o nível de preto.  
Conectar ao sinal de blanking do console (SCART pino 16 / FB) ou ao CSYNC via circuito de detecção.  
Sem esse pulso: brilho fixo no valor de inicialização dos caps de clamp (funciona mas sem controle dinâmico).

Alternativa simples sem blanking: deixar pino 14 em 5V fixo (clampa continuamente) — funciona mas pode introduzir distorção no preto em alguns sinais.

#### White balance (Opção B)

- Pinos DRIVE (27/22/18): trimpot de 1kΩ por canal entre GND e VCC — ajusta ganho
- Pinos CLAMP− (26/21/17): trimpot de 1kΩ por canal — ajusta ponto de corte de preto

Calibração em duas etapas: primeiro DRIVE (ajusta branco), depois CLAMP− (ajusta preto).

#### Alimentação Opção B

| Opção | Tensão | Como obter | Observação |
|---|---|---|---|
| Ideal | 12V | Rail 12V interno da TV (verificar no PSU board) | Headroom máximo |
| Aceitável | 9V | CN004 pino 7 | Headroom reduzido, testar estabilidade |
| Alternativa | 12V boost | Módulo boost MT3608 a partir do 9V | ~R$5, simples |

Não usar 5V do IC604 — tensão insuficiente para LM1203N.

#### Componentes Opção B — por canal (×3)

| Componente | Valor | Função |
|---|---|---|
| R_term | 75Ω 1/4W | Terminação 75Ω da fonte |
| C_in | 100nF film (MKT/MKP) | Acoplamento AC — film preferível a eletrolítico em HF |
| C_clamp | 100nF film | Clamp cap por canal (pinos 5/8/10) |
| R_out | 1kΩ 1/4W | Converte saída de corrente em tensão |
| trimpot DRIVE | 1kΩ multivolta | White balance ganho por canal |
| trimpot CUTOFF | 1kΩ multivolta | White balance corte de preto por canal |

#### Componentes Opção B — globais (×1)

| Componente | Valor | Função |
|---|---|---|
| LM1203N | DIP-28 | Chip pré-amp RGB dedicado |
| pot_contraste | 10kΩ linear | Contraste — 1 pot, 3 canais (atenuador interno) |
| Fonte 12V (se necessário) | MT3608 ou rail TV | Alimentação do LM1203N |
| C_bypass VCC | 100nF cerâmico ×4 | Bypass em cada pino VCC (1, 13, 23, 28) |
| C_bulk VCC | 10µF eletrolítico | Bulk decoupling 12V |

> **Brilho na Opção B:** controlado pelo circuito de clamp — não há pot externo de brilho como na Opção A. O brilho ajusta-se automaticamente pelo nível de preto do sinal se CLAMP GATE estiver conectado ao blanking. Se precisar de ajuste manual, interpor trimpot no VREF (pino 11).

---

#### Comparativo das opções

| Critério | Opção A (TLV2374) | Opção B (LM1203N) |
|---|---|---|
| Tensão supply | 5V (já disponível) | 12V (pode precisar de boost) |
| Disponibilidade | Alta — op-amp genérico | Média — chip legacy, achar em estoque |
| Complexidade | Média | Maior (28 pinos, clamp, blanking) |
| Contraste | Pot 3-gang (3 seções) | Pot simples (atenuador interno) |
| Brilho | Pot externo direto | Clamp automático ou VREF trimpot |
| White balance | 3 trimpots (ganho) | 6 trimpots (ganho + cutoff por canal) |
| Qualidade de sinal | Boa (op-amp genérico) | Melhor (igualamento interno, projetado p/ vídeo) |
| **Recomendação** | Primeira opção — menor risco | Se achar o chip e quiser qualidade extra |

---

## Conexões completas do mod

| Sinal da fonte | Conecta em | Observação |
|---|---|---|
| CSYNC (ou composite com sync) | AV2 VIDEO RCA (frontal) | IC001 trava deflexão aqui |
| R (0–0.7V, 75Ω) | CN004 pin 4 via 74HCT4053 | Com cap + bias |
| G (0–0.7V, 75Ω) | CN004 pin 3 via 74HCT4053 | Com cap + bias |
| B (0–0.7V, 75Ω) | CN004 pin 2 via 74HCT4053 | Com cap + bias |
| Audio L | AV2 AUDIO L RCA (frontal) | AV2 áudio esquerdo |
| Audio R | AV2 AUDIO R RCA (frontal) | AV2 áudio direito |
| Enable/FB | 74HCT4053 pino S | LOW=TV, HIGH=RGB |
| GND | Chassis / CN004 pin 1 ou 5 | Referência comum |

**TV deve estar no modo AV2** — sync e áudio entram pelos RCAs frontais do AV2, deixando AV1 e componente livres para outros dispositivos.

### Por que AV2 e não AV1

AV2 usa os RCAs frontais da TV (borda oposta a J901). Sync e áudio entram por lá. RGB bypass via CN004 é independente da entrada selecionada — IC001 trava deflexão em AV2, mas RGB vai direto para IC751.

Resultado: AV1 (J901) e componente continuam disponíveis normalmente.

---

## Compatibilidade com videogames

### Funciona nativamente (saída 15kHz)

| Console | Resolução típica | Observação |
|---|---|---|
| SNES / Super Famicom | 224p / 240p / 448i | RGB nativo, perfeito |
| Mega Drive / Genesis | 224p / 240p | RGB nativo, perfeito |
| Master System | 192p / 224p | RGB nativo |
| Neo Geo (AES/MVS) | 240p | RGB nativo |
| PlayStation 1 | 240p / 480i | Ambos 15kHz, troca transparente |
| Saturn | 240p / 480i | Ambos 15kHz |
| N64 | 240p / 480i | Requer mod RGB interno |
| GameCube | 480i | Modo 480i = 15kHz |
| Dreamcast | 240p / 480i | Via SCART, não VGA |

### Problemático

| Console | Problema |
|---|---|
| PS2 | Muitos jogos forçam 480p (31kHz) — imagem some nesses momentos |
| GameCube | 480p mode = 31kHz, não funciona |
| Dreamcast VGA | 31kHz, não funciona |
| Xbox / PS3+ | 31kHz+, incompatível sem upscaler |

### Mudança de resolução em tempo real

- **Mesma freq H (ex: PS1 trocando 240p ↔ 480i):** IC001 re-trava automaticamente. Sem problema.
- **Muda freq H (15kHz → 31kHz):** IC001 perde sync. Imagem some até voltar a 15kHz. Sem dano.
- **Muda largura de pixels (ex: MD 256↔320):** Mesma freq H, só muda pixels ativos. IC001 fica travado. Funciona.

### Solução para fontes 31kHz

Interpor um **RetroTINK 2x-Mini** ou similar entre console e TV:
```
Console → RetroTINK 2x-Mini → [480p → 480i 15kHz] → TV
```
Adiciona ~1 frame de latência. Permite qualquer console independente de resolução.

---

## Segurança

### Para a TV

| Risco | Mitigação |
|---|---|
| Overdrive do CRT por nível alto | 75Ω terminação + cap acoplamento corretos |
| AKB ler nível errado durante bypass | Causa variação de brilho por alguns frames — sem dano |
| Mod reversível | CN004/CN701 é conector físico — desconecta e volta ao original |

### Para você — PERIGOS DO CRT

> **ATENÇÃO: A TV mantém tensões letais após desligar da tomada.**

| Tensão | Local | Tempo de descarga |
|---|---|---|
| ~25kV | Ânodo do CRT (capa vermelha) | **horas a dias** |
| ~200V | C Board — alimentação IC751 | minutos |
| ~135V | B+ na A Board | minutos |

**Procedimento obrigatório antes de abrir a TV:**

1. Desligar da tomada
2. Aguardar 5 minutos mínimo
3. Descarregar ânodo do CRT:
   - Resistor **10MΩ 2W** em série com fio isolado
   - Inserir ponta sob a capa vermelha do ânodo
   - Outra ponta no chassis metálico da TV
   - Segurar pelo cabo, nunca pelo resistor
   - Aguardar até parar faíscas/som de descarga
4. Só então trabalhar

**Este mod específico (CN004/CN701)** fica na A Board, longe do FBT e ânodo. Com TV desligada e ânodo descarregado, área segura para trabalhar. Não é necessário mexer perto do HV.

---

## Lista de materiais

### Chaveamento e controle

| Componente | Qtd | Observação |
|---|-----|---|
| 74HCT4053 (DIP ou SMD) | 1× | Mux analógico 3× 2:1 |
| Transistor NPN BC547 ou 2N2222 | 1× | Driver FB |
| Resistor 10kΩ 1/4W | 2× | Base (R1) e pull-down (R2) do transistor FB |
| Chave SP3T (3 posições) | 1× | AUTO / RGB / TV |

### Ganho e controles de imagem — Opção A (TLV2374)

| Componente | Qtd | Observação |
|---|-----|---|
| TLV2374 ou LMV324 (quad op-amp) | 1× | Single-supply 5V, DIP-14 ou SOP-14 |
| Resistor 75Ω 1/4W | 3× | R_term — terminação RGB por canal |
| Resistor 5kΩ 1/4W | 3× | R_gmin — ganho mínimo por canal |
| Resistor 10kΩ 1/4W | 3× | R_f — realimentação por canal |
| Resistor 33kΩ 1/4W | 1× | R_a virtual GND (lado 5V) |
| Resistor 10kΩ 1/4W | 1× | R_b virtual GND (lado GND) → ~1.16V |
| Resistor 10kΩ 1/4W | 3× | R_top bias brilho por canal |
| Resistor 470Ω 1/4W | 1× | R_bmin — bias mínimo brilho |
| Capacitor eletrolítico 47µF 16V | 6× | C_in + C_out por canal (polo + para lado de maior tensão) |
| Capacitor eletrolítico 10µF 16V | 2× | C_vgnd (virtual GND) + bulk VCC |
| Capacitor cerâmico 100nF | 2× | Bypass VCC 74HCT4053 + TLV2374 |
| Trimpot 1kΩ multivolta | 3× | White balance R, G, B |
| Pot linear 2kΩ | 1× | Brilho |
| Pot linear 10kΩ 3-gang | 1× | Contraste — 3 seções, mesmo eixo |

### Ganho e controles de imagem — Opção B (LM1203N)

| Componente | Qtd | Observação |
|---|-----|---|
| LM1203N | 1× | DIP-28 — verificar disponibilidade antes de escolher esta opção |
| Resistor 75Ω 1/4W | 3× | R_term — terminação RGB por canal |
| Resistor 1kΩ 1/4W | 3× | R_out — converte saída corrente em tensão |
| Capacitor film 100nF (MKT) | 6× | C_in (×3) + C_clamp (×3) por canal |
| Capacitor cerâmico 100nF | 5× | Bypass VCC pinos 1, 13, 23, 28 + 74HCT4053 |
| Capacitor eletrolítico 10µF | 1× | Bulk VCC 12V |
| Trimpot 1kΩ multivolta | 6× | White balance: DRIVE ×3 + CUTOFF ×3 |
| Pot linear 10kΩ | 1× | Contraste (wiper no pino 12, entre GND e VREF pino 11) |
| Fonte 12V | 1× | Rail 12V interno da TV ou módulo boost MT3608 do 9V |

### Conectores e cabeamento

| Componente | Qtd | Observação |
|---|-----|---|
| Conector compatível CN004/CN701 | 1× | Verificar passo e tipo in situ |
| Cabo fino blindado (tipo áudio) | — | Sync + áudio AV2 — pode ser longo |
| Cabo fino simples (flat ou 0.1mm) | — | RGB interno (curto, mod board ao lado do CN004) |

---

## Cabeamento interno

### RGB (curto — mod board ao lado do CN004)

Cabo fino simples funciona. Efeitos de linha de transmissão irrelevantes para trecho de ~15cm a 5MHz (comprimento de onda ~40m).

- Cabo tipo flat cable ou fios 0.1mm individuais
- A terminação 75Ω é feita por **resistor no pino de entrada** do mod board, não pelo cabo
- Adicionar blindagem só se aparecer ruído visível após montagem

### Sync + áudio (longo — da mod board/fonte até AV2 frontal)

Sinal de baixa frequência — blindagem básica suficiente.

- Cabo de áudio blindado fino (tipo P2-P2 fino)
- Malha conectada ao GND **em uma ponta apenas** (evita ground loop)
- Pode cruzar a placa sem problema

### Rota dos cabos na A Board

Passar pelos **bordas da placa**, evitar cruzar sobre:
- T801 (FBT) — campo EM forte
- Q805 (H-OUT) — pulsos alta amplitude 15kHz
- Seção EW (L802, Q808)

```
[AV2 frontal]  ←──── sync/áudio (blindado fino, pode ser longo)
       |
   borda da placa
       |
[mod board] ←── RGB curto e simples
       |
    [CN004]
```

---

## Alternativa sem mod — conversor RGB→YPbPr + J901

**Confirmado:** IC001 aceita 240p/15kHz na entrada componente J901. Testado com PS1 (FF8 — troca 240p↔480i em tempo real durante o jogo).

Isso abre uma alternativa sem abrir a TV: usar conversor RGB→YPbPr analógico + J901.

### Requisito crítico: conversor sem upscaling

Conversores com scaler interno (ex: BITFUNX B0FSKMJGXK) convertem 240p→480i internamente — **não servem**. Precisar de conversor de **matriz analógica pura** que só faz conversão de espaço de cor, sem frame buffer.

### Opções confirmadas para 240p nativo

| Produto | Método | 240p | Preço aprox. | Onde |
|---|---|---|---|---|
| **RetroTINK RGB2COMP** | Matriz analógica | ✅ confirmado | ~$45 USD | retrotink.com |
| **Genérico AliExpress** (LM1881 + BA7230LS) | Matriz analógica | ✅ confirmado com osciloscópio | ~$20 USD | AliExpress |
| **DIY op-amp** | Summing amps + resistores 1% | ✅ (sem frame buffer por definição) | ~$5–10 | componentes |

O genérico do AliExpress usa **LM1881** (separador de sync) + **BA7230LS** (encoder YPbPr) — revisão externa confirmou ausência de conversão de resolução.

### Comparativo com RGB mod direto

| Critério | Conversor + J901 | RGB mod (CN004) |
|---|---|---|
| Mod na TV | Nenhum | Sim |
| 240p | ✅ | ✅ |
| 480i / 480p | ✅ | ✅ / ❌ (31kHz não passa) |
| Qualidade | Boa (RGB→YPbPr→IC001→RGB) | Melhor (sinal direto) |
| Brilho/contraste | Knobs no adaptador | Pots externos no mod |
| Custo | $20–45 adaptador | $15–25 componentes |
| Reversível | Trivial | Sim (CN004 é conector) |
| AV1 + componente livres | AV1 livre, componente ocupado | Componente + AV1 livres |

### Quando usar cada um

- **Conversor + J901:** uso imediato sem modificação, consoles com SCART RGB, qualidade suficiente para uso casual
- **RGB mod CN004:** melhor qualidade de imagem, libera J901 para outros dispositivos, vale a pena para uso permanente

---

## Referências internas

- [`tv/circuits/c_board_rgb_amp.md`](../circuits/c_board_rgb_amp.md) — IC751, CN701, resistores de entrada R/G/B
- [`tv/circuits/block_006_av_inputs.md`](../circuits/block_006_av_inputs.md) — J901 pinagem, entradas AV1/SCART
- [`tv/circuits/voltage_waveform_table.md`](../circuits/voltage_waveform_table.md) — IC001 pinos 85/86/87 tensões
- [`tv/circuits/block_001_processor.md`](../circuits/block_001_processor.md) — IC001 TDA12009H visão geral

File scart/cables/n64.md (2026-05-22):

# Cabo SCART RGB — Nintendo 64
> ⚠️ N64 NTSC não tem saída RGB nativa. Mod obrigatório antes de usar este cabo.  
> Ver [`consoles/n64/README.md`](../../consoles/n64/README.md) para opções de mod.

---

## Conector MultiAV — mesmo do SNES

**Idêntico ao SNES** — mesmo conector card-edge 12 pinos, mesma pinagem.

| Pin | Sinal |
|-----|---|
| 1 | Red (após mod) |
| 2 | Green (após mod) |
| 3 | CSync (NTSC) / +12V (PAL) |
| 4 | Blue (após mod) |
| 5 | GND |
| 6 | GND |
| 7 | Y / Luma |
| 8 | C / Chroma |
| 9 | CVBS |
| 10 | +5V |
| 11 | Audio L |
| 12 | Audio R |

---

## Cabo após mod RGB — igual ao SNES NTSC

Após instalar mod RGB, o cabo é **idêntico ao cabo SNES NTSC**:

```
MultiAV                  Componentes              SCART
────────                 ───────────              ─────
Pin 1  (R)  ──── C+ 220µF C- ───────────────────► Pin 15 (Red In)
Pin 2  (G)  ──── C+ 220µF C- ───────────────────► Pin 11 (Green In)
Pin 4  (B)  ──── C+ 220µF C- ───────────────────► Pin 7  (Blue In)
Pin 3  (CSync) ──────────────────────────────────► Pin 20 (Sync In)
Pin 10 (+5V) ── 820Ω ─┬─ 1kΩ ─ GND ─────────────► Pin 16 (Blanking)
Pin 11 (Audio L) ───────────────────────────────► Pin 6  (Audio In L)
Pin 12 (Audio R) ───────────────────────────────► Pin 2  (Audio In R)
Pin 5/6 (GND) ──────────────────────────────────► Pins GND
```

Caps 220µF nas linhas RGB (mesmo DC offset do SNES).

---

## Diferenças em relação ao SNES

| Aspecto | SNES | N64 |
|---|---|-----|
| RGB nativo (NTSC) | ✓ Sim | ✗ Requer mod |
| Conector MultiAV | Idêntico | Idêntico |
| Cabo RGB SCART | ✓ direto | Só após mod |
| Caps 220µF no cabo | ✓ Sim | ✓ Sim (mesmo) |
| csync no pin 3 | ✓ (exceto 1CHIP-03) | Depende da revisão |
| S-Video nativo | ✓ | ✓ NTSC sim |
| Blur interno | — | N64 tem blur nativo — mod adicional para remover |

---

## Conector para cabo DIY

**Mesmo conector do SNES** — mesmas opções de fornecedor (ver `../fornecedores.md`).  
Console5 vende plug MultiAV avulso compatível com SNES/N64/GCN.

---

## Resoluções — compatibilidade KV-21FS140

| Modo | Freq H | Compatível |
|---|---|---|
| 240p | 15.7 kHz | ✓ |
| 480i | 15.7 kHz | ✓ |

N64 só opera em 240p/480i — **100% compatível** com o mod.

---

## Referências

- [N64 RGB Cable / csync — RetroRGB](https://retrorgb.com/n64cablecsync.html)
- [Nintendo MultiAV — GameSX](https://gamesx.com/wiki/doku.php?id=av:nintendomultiav)

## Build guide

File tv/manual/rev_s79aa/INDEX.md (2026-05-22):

# KV-21FS140 Service Manual — Index (Edição LATIN NORTH/SOUTH)

**Modelo:** Sony Trinitron KV-21FS140  
**Chassis:** BX1S  
**Commander:** RM-YA005  
**Part No.:** 9-965-997-01 (Rev 1, 2/2006)  
**Destinos:** LATIN NORTH (SCC-S79A-A), LATIN SOUTH (SCC-S79B-A)

> Este manual cobre modelos **NTSC apenas** — sem suporte PAL/NTSC multi.  
> Comparar com `../rev_brazil/INDEX.md` para diferenças vs modelo Brazil.

---

## Sumário por Seção

### Páginas 1–3 — Capa e Índice

- Histórico de revisão, modelos/destinos/chassis, tabela de conteúdo completa
- Aviso de segurança: curto-circuitar anodo do tubo antes de remover

---

### Páginas 4–8 — Especificações e Diagnóstico

**Especificações (Página 4):**
- Sistema de TV: NTSC (American standard)
- Canais: VHF 2–13 / UHF 14–69 / CATV 1–125
- Antena: 75-ohm externa VHF/UHF
- Tubo: FD Trinitron — 21" diagonal (20" visível)
- Acessórios: Commander RM-YA005, 2× pilhas AA

**Avisos e Precauções (Página 5):**
- Transformador de isolação obrigatório durante serviço
- Chassis conectado diretamente à linha AC (live chassis)
- Componentes críticos marcados com ! — substituir apenas com part numbers Sony

**Verificação de Segurança (Página 6):**
- Verificar soldas, bridges, fios pressionados
- Teste de vazamento AC: máximo 0.5 mA
- Métodos de medição documentados

**Função Auto-diagnóstico (Páginas 7–8):**

| Flashes | Código | Causa provável |
|---|---|---|
| Sem energia | — | Cabo desligado ou fusível F600 queimado |
| 2x | OCP (2:0–2:255) | Q805 ou IC751 em curto |
| 4x | V-Protect/OVP (4:0–4:255) | +13V ausente ou IC804 defeituoso |
| 5x | IK/AKB (5:0–5:255) | IC1545 ou IC001 defeituoso; G2 mal ajustado |
| 8x | Power NG +5V (8:0–8:255) | IC604 ou IC602 defeituoso |

**Como acessar diagnóstico:**
- Entrar: `[DISPLAY] → [5] → [VOL-] → [POWER]` (em standby)
- ⚠️ **Diferente do Brasil:** este manual usa **VOL-** para diagnóstico e **VOL+** para service mode
- Limpar resultado: `[CH 8]`
- Sair: desligar TV

---

### Páginas 9–11 — Seção 1: Desmontagem

**Sequência:**
1. Tampa traseira — 7 parafusos (+BVTP 4×16)
2. Soltar A Board catch tab
3. Posição de serviço — desconectar CN200
4. Remoção do tubo de imagem (CRT)

**Remoção do CRT:**
- Descarregar anodo (tensão residual alta — atenção)
- Desconectar: Deflection Yoke, Neck Assy, DGC, strap de aterramento
- Remover: C Board, chassis, neck assembly, deflection yoke, bobina de degaussing
- Remover CRT com suportes de mola
- **ATENÇÃO:** Curto-circuitar anodo após remoção

---

### Páginas 12–15 — Seção 2: Ajustes Físicos (Setup Adjustments)

**Equipamentos necessários:**
- Gerador de padrões, degaussing, osciloscópio, multímetro digital, XCV Adjuster, Landing Checker, fonte DC

**Sequência obrigatória de ajuste:**
1. Beam Landing (purity)
2. Convergência
3. Focus
4. G2 (Screen)
5. White Balance

**2-1 Beam Landing:**
- Sinal verde, mover DY para trás, ajustar purity control
- Centro = verde, lados = vermelho/azul
- Avançar DY até tela inteira verde
- Verificar vermelho e azul; ajustar discos magnéticos nos cantos

**2-2 Convergência:**
- Estático vertical: ímã 4 polos — alinhar R, G, B no centro
- Estático horizontal: ímã 6 polos — alinhar azul com R/G
- Grosso: TLH (H-conv R/B), YCH (balanço Y), TLV (V-conv R/B), XCV (balanço X)
- Cantos: Piece A(90) Permaloy ou Convergence Correct Assy

**2-3 Focus:**
- Padrão monoscópio digital, modo DYNAMIC
- Ajustar VR de focus no centro; verificar anel magenta com padrão azul

**2-4 G2 (Screen):**
- Condição: Picture/Brightness STANDARD, TV em Video mode, WHBL 016 "RGBB" = 01
- Catodo R/G/B a 165 ±2 VDC
- Ajustar Screen VR no FBT até linha de varredura desaparecer
- Restaurar RGBB = 00

---

### Página 16 — Seção 3: Modo Serviço

**Entrada no Service Mode:**
`[DISPLAY] → [5] → [VOL+] → [POWER]` (em standby)

**Saída:** `[POWER]` → standby → `[POWER]` novamente

**Navegação:**
- `[1]/[4]` — selecionar item
- `[3]/[6]` — ajustar valor
- `[MUTING] → [−]` — gravar

**Display:** `categoria | nº item | nome | dado decimal | SERVICE | freq | canal`

---

### Páginas 17–30 — Tabelas de Ajuste (Service Mode Items)

| Categoria | Descrição |
|---|---|
| GEOM | Geometria (posição H/V, tamanho, correções EW) |
| WHBL | White Balance (offset preto R/G/B, drive branco, sub-brilho) |
| SADJ | Sub-ajustes (PMAX/contraste, hue, color, bright) |
| YC | Processamento Y/C (frequência peaking, delay, matriz) |
| SYNC | Sincronismo (modo sync, PLL, identificação vídeo) |
| PICT | Qualidade de imagem (cathode drive, comb filter, gamma, coring) |
| SW | Seleção de sinal (CVBS2, SVO, proteção flash) |
| VIF | FI de vídeo (offset demodulador, AGC, modo de busca) |
| VM | Velocity Modulation (delay, amplitude, modo) |
| SDEM | Demodulador FM (janela FM, QSS, filtro bandpass) |
| TXT | Teletext |
| SDSP | Display de som (BBE, surround, equalizer, treble, bass) |
| SDEC | Decoder de som (SAP, FM A2, NICAM, DCXO) |
| HTV | Home TV (volume máximo/inicial, standby, prog inicial) |
| OPTM | Opções (timer auto-off, OSD, mute sem sinal) |
| OPUS | Opções de sistema (stay-off, canal inicial, CC) |
| OPVP | Opções vídeo/processamento |
| OPTB | Option bytes OPB1–OPB6 |

**Dados variáveis por modelo:**

| Item | LATIN (S79AA) | Brazil (S80A) |
|---|---|---|
| SYNC/FORF | 01 | 00 |
| OPTM/LANG | 01 | 02 |
| OPUS/SPCH | 06 | 05 |

**Option Bytes — LATIN:**

| Byte | DEC | Diferença vs Brazil |
|---|-----|---|
| OPB1 | 72 | Igual |
| OPB2 | 43 | Brazil = PAL/NTSC multi; LATIN = NTSC only |
| OPB3 | 4 | Igual (US Stereo) |
| OPB4 | 0 | Igual |
| OPB5 | 3 | Igual |
| OPB6 | 5 | Igual |

---

### Páginas 18–19 — Ajustes de Qualidade e Geometria

**P MAX / Contraste (SADJ 000):**
- NTSC 75% CB; PICTURE 100%, COLOR 0%, BRIGHTNESS 50%
- Osciloscópio no pino 4 (R Output) de CN004
- Alvo: **1.10 ±0.03 Vp-p** (NTSC 21" sem VM)

**Sub Color (SADJ 004):**
- NTSC: VB1=VB4 (diff ≤70mV)

**Sub Hue (SADJ 001):**
- NTSC 3.58 CB; ajustar VB1=VB2=VB3=VB4 (diff ≤80mV)

**Sub Bright (WHBL 010 SBRT):**
- RF mode, monoscópio NTSC, Brightness 50%, Picture MINIMUM
- Cutoff = 10 IRE; levemente iluminado = 20 IRE

**Geometria — 2 modos (NTSC apenas, sem PAL):**
1. NTSC 60Hz Normal
2. NTSC 60Hz Wide

**Items GEOM em ordem de ajuste:**
VPOS → VSIZ → HPOS → EWTZ → HSIZ → HBOW → EWPW → UCOP → LCOP → HPAR → SCOR → VLIN → VSCR

Alvos VSIZ: 11.5 (NTSC mono)  
Alvos HSIZ: 15.3 (NTSC mono)

---

### Páginas 35–46 — Seção 4: Diagramas

**Página 35 — Localização das Placas:**
- **A Board** — placa principal
- **C Board** — CRT neck board

**Página 36 — Diagrama de Blocos:**
- IC001 One-Chip central (System + Video + Audio)
- RF Amp/Tuner → VIF/SIF → Color Decoder → YUV → RGB Amp → CRT
- Audio Amp: AN5276T **ou** AN17804A (alternativas documentadas neste manual)
- Power: AC → SMPS → +B(135V), 30V, 11V, 9V, 5V, 3.3V, 1.8V

**Páginas 37–44 — Esquemáticos A Board (6 blocos):**

| Bloco | Função |
|---|---|
| Block 001 | IC001, NVM IC003, LEDs, conectores |
| Block 002 | Audio Amp (AN5276T/AN17804A), mute, fonte 9V |
| Block 003 | SMPS: T600, reguladores |
| Block 004 | Deflexão: Q805, IC804, FBT T801, EW |
| Block 005 | IF: tuner, VIF SAW, SIF, AGC |
| Block 006 | Entradas AV (AV1/AV2/AV3), SCART, DVD/RGB |

**Página 44 — C Board Schematic:**
- IC751 (TDA6108AJF) — RGB amp para cátodos do CRT
- CN701 → CN004 da A Board (R/G/B/IK/9V/GND)
- CN703 → CN801 da A Board (deflexão)

**Páginas 46–47 — ICs com vista superior (package drawings)** — idêntico ao Brazil

---

### Páginas 47–48 — Seção 5: Vista Explodida

**Componentes principais:**

| Ref | Part No. | Descrição |
|-----|---|---|
| 3 | 8-738-822-05 | CRT (LATIN NORTH) |
| 3 | 8-738-823-05 | CRT (LATIN SOUTH) |
| 55 | 8-451-505-71 | Deflection Yoke Y21RSA-V |
| 56 | A-1179-571-A | C Board montada |
| 61 | 1-456-153-11 | Bobina de degaussing (LATIN NORTH) |
| 61 | 1-419-287-21 | Bobina de degaussing (LATIN SOUTH) |

**A Board completa:**

| Variante | Part No. |
|---|---|
| LATIN NORTH | A-1152-116-A |
| LATIN SOUTH | A-1152-122-A |

---

### Páginas 49+ — Seção 6: Lista de Peças Elétricas

Part numbers individuais para todos componentes das placas A e C. Estrutura idêntica ao Brazil — conferir valores específicos quando substituir componentes, pois part numbers de alguns itens diferem.

---

## Referência Rápida — Tensões Nominais

| Linha | Tensão | Notas |
|---|---|---|
| +B | 135V | Principal; OCP monitora |
| HV (anodo CRT) | ~25kV | Via FBT T801 |
| VCC Audio | 30V | Para amp áudio |
| 11V | 11V | IC602 input |
| 9V | 9V | IC602 (KIA78R09API) |
| 5V | 5V | IC604 (KIA7805API) |
| 3.3V | 3.3V | IC606 (KIA78D33P1) |
| 1.8V | 1.8V | IC603 (PQ018EF01SSH) e IC607 (BA18BC0FP-E2) |
| -13V (VSS) | -13V | Para IC804 (vertical) |
| Catodo CRT | 165 ±2 VDC | Ajuste G2 |

## Referência Rápida — ICs Principais

| Ref | Part | Função |
|-----|---|---|
| IC001 | TDA12009H (variantes) | One-chip: System + Video + Audio |
| IC003 | CAT24WC16WI-TE13 | NVM EEPROM |
| IC200 | AN5276T **ou AN17804A** | Audio Amp |
| IC602 | KIA78R09API | Regulador 9V |
| IC603 | PQ018EF01SSH | Regulador 1.8V |
| IC604 | KIA7805API | Regulador 5V |
| IC605 | SE135N-LF38 | Regulador auxiliar |
| IC606 | KIA78D33P1 | Regulador 3.3V |
| IC607 | BA18BC0FP-E2 | Regulador 1.8V (áudio) |
| IC751 | TDA6108AJF/N1 | RGB Output Amp (C Board) |
| IC801 | LM2903DT | Comparador |
| IC802 | TJM4558CDT | Op-Amp (EW) |
| IC804 | STV9302A | Vertical Deflection |
| Q805 | 2SC5885 | H-Output transistor |

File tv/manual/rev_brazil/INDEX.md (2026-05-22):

# KV-21FS140 Service Manual — Index

**Model:** Sony Trinitron KV-21FS140  
**Chassis:** BX1S  
**Commander:** RM-YA005  
**Part No.:** 9-872-877-01 (Rev 1, 2005/12)  
**Destinos:** Brazil (SCC-S80A-A), E variants (SCC-S79A-A, SCC-S79B-A)

---

## Sumário por Seção

### Páginas 1–3 — Capa e Índice
- Histórico de revisão, modelos/destinos/chassis, tabela de conteúdo completa
- Aviso de segurança: curto-circuitar anodo do tubo antes de remover

---

### Páginas 4–5 — Função de Auto-diagnóstico

**Códigos de erro (flashes do LED STANDBY):**

| Flashes | Código | Causa provável |
|---|---|---|
| Sem energia | — | Cabo desligado ou fusível F600 (A board) |
| 2x | OCP (2:0–2:255) | Q805 ou IC751 em curto |
| 4x | V-Protect/OVP (4:0–4:255) | +13V ausente ou IC804 defeituoso |
| 5x | IK/AKB (5:0–5:255) | IC1545 ou IC001 defeituoso; G2 mal ajustado |
| 8x | Power NG +5V (8:0–8:255) | IC604 ou IC602 defeituoso |

**Como acessar diagnóstico:**
- Entrar: `[DISPLAY] → [5] → [VOL+] → [POWER]` (em standby)
- Limpar resultado: `[CH 8]`
- Sair: desligar TV

**Circuito diagnóstico:**
- OCP: detectado no pino 32 do IC001 (>4V → standby)
- V-Protect: detectado no pino 13 do IC001 (ausência de pulso vertical)
- IK/AKB: IC001 detecta desbalanço RGB >15s
- Power NG: IC001 detecta HV anormal por falha em IC602/IC604

---

### Páginas 6–7 — Seção 1: Desmontagem

**Sequência:**
1. Tampa traseira — 7 parafusos (+BVTP 4×16)
2. Remoção do alto-falante — 2 parafusos (washer head +P4×16)
3. Remoção do Chassis Assy
4. Posição de serviço
5. Remoção da A Board
6. Remoção do tubo de imagem (CRT)

**Remoção do CRT:**
- Desconectar: Deflection Yoke, Neck Assy, DGC, strap de aterramento
- Deitar TV com face do CRT para baixo em almofada
- Remover: cap de anodo, C Board, mola de tensão, suportes CRT, DY, Neck Assy, DGC
- **ATENÇÃO:** Curto-circuitar anodo após remoção

---

### Páginas 8–10 — Seção 2: Ajustes Físicos (Setup Adjustments)

**Equipamentos necessários:**
- Gerador de padrões, degaussing, osciloscópio, multímetro digital, XCV Adjuster, Landing Checker, fonte DC

**Sequência obrigatória de ajuste:**
1. Beam Landing (purity)
2. Convergência
3. Focus
4. G2 (Screen)
5. White Balance

**2-1 Beam Landing:**
- Sinal verde, mover DY para trás, ajustar purity control (centro = verde, lados = vermelho/azul)
- Avançar DY até tela inteira verde
- Verificar vermelho e azul; usar discos magnéticos nos cantos

**2-2 Convergência:**
- Estático vertical: ímã 4 polos — alinhar R, G, B no centro
- Estático horizontal: ímã 6 polos — alinhar azul com R/G
- Grosso: TLH (H-conv R/B), YCH (balanço Y), TLV (V-conv R/B), XCV (balanço X)
- Cantos: Piece A(90) Permaloy nos cantos com misconvergência

**2-3 Focus:**
- Padrão monoscópio digital, modo DYNAMIC
- Ajustar VR de focus no centro; verificar anel magenta com padrão azul

**2-4 G2 (Screen):**
- Condição: Picture/Brightness STANDARD, TV em Video mode, WHBL 016 "RGBB" = 01
- Catodo R/G/B a 165 ±2 VDC
- Ajustar Screen VR no FBT até linha de varredura desaparecer
- Restaurar RGBB = 00

**2-5 White Balance:**
- Modo serviço, sinal branco raster, Picture DYNAMIC, PICT 006 "WTS" = 00
- Highlight: ajustar WHBL 03 "GDRV" e 04 "BDRV" (botões 1/4 e 3/6)
- Cutoff: ajustar WHBL 000 "BKOR" e 001 "BKOG"
- Gravar: `[MUTING] → [-]`
- Restaurar WTS ao dado original

---

### Página 11 — Seção 3: Ajustes de Circuito — Modo Serviço

**Entrada no Service Mode:**
`[DISPLAY] → [5] → [VOL+] → [POWER]` (em standby)

**Saída:** `[POWER]` → standby → `[POWER]` novamente

**Navegação:**
- `[1]/[4]` ou `[2]/[5]` — selecionar item
- `[3]/[6]` — ajustar valor
- `[MUTING]` → `[-]` — gravar

**Display do Service Mode:**
`categoria | nº item | nome | dado decimal | SERVICE | freq | canal`

---

### Páginas 12–28 — Tabelas de Ajuste (Service Mode Items)

**Categorias disponíveis:**

| Categoria | Descrição | Páginas |
|---|---|---|
| GEOM | Geometria (posição H/V, tamanho, correções EW) | 12–13 |
| WHBL | White Balance (offset preto R/G/B, drive branco, sub-brilho) | 13–14 |
| SADJ | Sub-ajustes (PMAX/contraste, hue, color, bright) | 14 |
| YC | Processamento Y/C (frequência peaking, delay, matriz) | 15 |
| SYNC | Sincronismo (modo sync, PLL, identificação vídeo) | 15 |
| PICT | Qualidade de imagem (cathode drive, comb filter, gamma, coring) | 16 |
| SW | Seleção de sinal (CVBS2, SVO, proteção flash) | 16 |
| VIF | FI de vídeo (offset demodulador, AGC, modo de busca) | 17 |
| VM | Velocity Modulation (delay, amplitude, modo) | 17 |
| SDEM | Demodulador FM (janela FM, QSS, filtro bandpass) | 18 |
| TXT | Teletext (posição vertical, brilho RGB, aquisição) | 18 |
| SDSP | Display de som (BBE, surround, equalizer, treble, bass) | 19 |
| SDEC | Decoder de som (SAP, FM A2, NICAM, DCXO) | 20 |
| SDKC | Decoder Korean (apenas modelos NTSC Korean) | 20 |
| PIP | Picture-in-Picture (posição H/V, AGC, delay) | 21 |
| HTV | Home TV (volume máximo/inicial, standby, prog inicial) | 22 |
| OPTM | Opções (timer auto-off, OSD, mute sem sinal) | 22 |
| OPUS | Opções de sistema (stay-off, canal inicial, CC) | 23 |
| OPVP | Opções vídeo/processamento (bandpass, burst key) | 23 |
| OPTB | Option bytes OPB1–OPB6 (bits de configuração) | 24 |

**Dados variáveis por modelo (pág. 25):**
- SYNC/FORF: Latin=01, Brazil=00, Argentina=03
- OPTM/LANG: Brazil=02, Argentina=01
- OPUS/SPCH: Latin=06, Brazil=05, Argentina=01

**OPB1 — KV-21FS140 Brazil:** DEC=72 (Home Theatre habilitado, B/G system)  
**OPB2 — Brazil:** DEC=43 (Component YCbCr disponível, 2 composites, PAL/NTSC multi)  
**OPB3 — Brazil:** DEC=4 (US Stereo habilitado, monaural=0)  
**OPB4 — Brazil:** DEC=0 (sem VM, sem surround, sem teletext)  
**OPB5 — Brazil:** DEC=3 (IP habilitado, Wide habilitado)  
**OPB6 — Brazil:** DEC=5 (sem PiP, OSD language=Portuguese)

---

### Páginas 29–30 — Ajustes de Qualidade e Geometria

**P MAX / Contraste (SADJ 000):**
- Video mode, Picture CUSTOM
- PAL 100% CB; PICTURE 100%, COLOR 0%, BRIGHT 50%
- Osciloscópio no pino 4 (R Output) de CN004
- Alvo: 1.46 ±0.03 Vp-p (21" sem VM) ou 1.10 Vp-p (NTSC sem VM)

**Sub Color (SADJ 004):**
- PAL: VB2=VB3=VB4; NTSC: VB1=VB4 (diff ≤70mV)
- Osciloscópio no pino 2 (B Output) de CN004

**Sub Hue (SADJ 001):**
- NTSC 3.58 CB; ajustar VB1=VB2=VB3=VB4 (diff ≤80mV)

**Sub Bright (WHBL 010 SBRT):**
- RF mode, PAL monoscópio, Brightness 50%, Picture MINIMUM
- Cutoff = 10 IRE; levemente iluminado = 20 IRE

**Geometria — 4 modos obrigatórios:**
1. PAL 50Hz Normal
2. PAL 50Hz Wide
3. NTSC 60Hz Normal
4. NTSC 60Hz Wide

**Items GEOM em ordem de ajuste (PAL 50Hz Normal):**
VPOS → VSIZ → HPOS → EWTZ → HSIZ → HBOW → EWPW → UCOP → LCOP → HPAR → SCOR → VLIN → VSCR

Alvos VSIZ: 12.4 (SPCB), 11.3 (PAL mono), 11.5 (NTSC mono)  
Alvos HSIZ: 16.4 (SPCB), 14.6 (PAL mono), 15.3 (NTSC mono)

---

### Páginas 31–46 — Seção 4: Diagramas

**Página 31 — Diagrama de Blocos:**
- One-chip IC001 (System/Video/Audio Processor) central
- Seções: RF Amp/Tuner → VIF/SIF → Color Decoder → YUV Processor → RGB Amp → CRT
- Audio: ADC → DAP/Stereo → Audio Amp IC (AN5276T) → 2× 10W speakers
- Power: AC 110–220V → CISPR/PFC → SMPS → +B(135V), 30V, 11V, 9V, 5V, 3.3V, 1.8V

**Página 32 — Localização das Placas:**
- **A Board** — placa principal (processamento, deflexão, fonte)
- **C Board** (C/CV Board) — CRT neck board (RGB output para cátodos do tubo)

**Páginas 33–44 — Esquemáticos A Board (7 Blocos):**

| Bloco | Função principal |
|---|---|
| Block 001 | IC001 One-Chip (System Controller + Video + Audio), NVM IC003, LEDs, conectores |
| Block 002 | Audio Amp IC200 (AN5276T), circuito de mute, fonte 9V para áudio |
| Block 003 | Power Supply (SMPS): transformador T600, reguladores 9V/5V/3.3V/1.8V, DGC relay |
| Block 004 | Deflexão: H-Out Q805 (2SC5885), V-Out IC804 (STV9302A), FBT T801, EW |
| Block 005 | IF: tuner, VIF SAW, SIF, AGC, RF Amp LNA |
| Block 006 | Entradas AV (AV1/AV2/AV3), SCART, DVD/RGB, saídas monitor |
| Block 007 | (referenciado em HS-A007) |

**Página 45 — C Board Schematic:**
- IC751 (TDA6108AJF) — RGB output amp para cátodos do CRT
- CN701 conecta ao CN004 da A Board (R/G/B/IK/9V/GND)
- CN703 conecta ao CN801 da A Board (deflexão)

**Página 46 — Tensões e Formas de Onda** (pág. 47 no manual)

**Página 47 — ICs com vista superior (IC package drawings):**
- IC001: TDA12009H, TDA12017H, TDA12019H, TDA12027H, TDA12067H, TDA12077H
- IC602: KIA78R09API (9V reg)
- IC605: SE135N-LF38
- IC603: PQ018EF01SSH (1.8V reg)

---

### Páginas 48–49 — Seção 5: Vista Explodida

**Componentes principais com part numbers:**

| Ref | Part No. | Descrição |
|-----|---|---|
| 3 | 8-738-823-05 | Tubo de imagem A51LPT50X(SDS) — exceto SV-13105(E) |
| 3 | 8-738-822-05 | Tubo de imagem A51LPT50X — SV-13105(E) |
| 4 | 1-452-032-00 | Disco magnético |
| 5 | 2-658-334-11 | Tampa traseira |
| 6 | 4-084-918-01 | Holder cabo HV |
| 7 | 4-031-319-01 | Espaçador DY (Brazil) |
| 8 | 4-057-714-01 | Peça TLH correction |
| 9 | 8-451-505-71 | Deflection Yoke Y21RSA-V |
| 10 | A-1116-728-A | C Board montada (VAR) |
| 19 | 1-453-329-41 | Bobina de degaussing — exceto SV-13105(E) |
| 19 | 1-456-153-11 | Bobina de degaussing — SV-13105(E) |

**A Board completa por variante:**
- KV-21FS140 Brazil: A-1151-078-A
- KV-21FS140 SV-13105(E): A-1152-116-A
- KV-21FS140 SV-13106(E): A-1152-122-A

---

### Páginas 50–57 — Seção 6: Lista de Peças Elétricas

**Conteúdo:** Part numbers individuais para todos os componentes das placas A e C:
- Capacitores (C001–C2xxx)
- Resistores (R001–R2647, incluindo chips, metal film, fusíveis)
- Diodos (D002–D833)
- Transistores (Q001–Q816)
- ICs (IC001, IC200, IC602–IC607, IC751, IC800–IC804)
- Bobinas/Indutores (L001–L806)
- Conectores, jumpers (JR, JW, CN, J)
- Transformadores (T600–T605, T800–T802)
- Fusível: F600 (A board)

**Componentes críticos de segurança (marcados !):**
- Todos os itens sombreados nos esquemáticos devem ser substituídos SOMENTE com part numbers Sony especificados

---

### Página 58 — C Board: Peças e Acessórios

**C Board (CN701/CN703):**
- IC751: TDA6108AJF/N1 (RGB amp) — Part 6-703-482-01
- J751: Socket CRT — Part 1-451-544-11
- L780: Indutor 22uH — Part 1-414-742-21

**Acessórios/Embalagem:**
- Manual Brazil: 2-666-991-51
- Manual outros: 2-666-990-41
- Transformador de antena (modelos E): 1-417-182-11

---

## Referência Rápida — Tensões Nominais

| Linha | Tensão | Notas |
|---|---|---|
| +B | 135V | Principal; OCP monitora esta linha |
| HV (anodo CRT) | ~25kV | Via FBT T801 |
| VCC Audio | 30V | Para amp áudio |
| 11V | 11V | IC602 input |
| 9V | 9V | IC602 (KIA78R09API) |
| 5V | 5V | IC604 (KIA7805API) |
| 3.3V | 3.3V | IC606 (KIA78D33P1) |
| 1.8V | 1.8V | IC607 (BA18BC0FP) e IC603 (PQ018EF01SSH) |
| -13V (VSS) | -13V | Para IC804 (vertical) |
| Catodo CRT | 165 ±2 VDC | Ajuste G2; medido no catodo R/G/B |

---

## Referência Rápida — ICs Principais

| Referência | Tipo/Part | Função |
|---|---|---|
| IC001 | TDA12009H (ou variantes) | One-chip: System + Video + Audio Processor |
| IC003 | CAT24WC16WI-TE13 | NVM (memória EEPROM) |
| IC200 | AN5276T | Audio Amp |
| IC602 | KIA78R09API | Regulador 9V |
| IC603 | PQ018EF01SSH | Regulador 1.8V |
| IC604 | KIA7805API | Regulador 5V |
| IC605 | SE135N-LF38 | Regulador auxiliar |
| IC606 | KIA78D33P1 | Regulador 3.3V |
| IC607 | BA18BC0FP-E2 | Regulador 1.8V (áudio) |
| IC751 | TDA6108AJF/N1 | RGB Output Amp (C Board) |
| IC801 | LM2903DT | Comparador |
| IC802 | TJM4558CDT | Op-Amp |
| IC804 | STV9302A | Vertical Deflection IC |
| Q805 | 2SC5885 | H-Output transistor |

---

## Referência Rápida — Conectores Inter-boards

| Conector A Board | Conector C Board | Sinal |
|---|---|---|
| CN004 (7P) | CN701 | R/G/B out, IK, GND, 9V |
| CN801 | CN703 | H1, deflexão |
| CN005 (3P) | — | Key buttons |

---

## Referência Rápida — Diagnóstico de Falhas Comuns

| Sintoma | Verificar primeiro |
|---|---|
| Sem energia, fusível ok | Q805 (H-Out), IC751 (C Board), +B line |
| LED pisca 2x | Q805 ou IC751 em curto |
| LED pisca 4x | +13V ausente, IC804 (STV9302A) |
| LED pisca 5x | IC001, IC1545 (Video OUT), ajuste G2 |
| LED pisca 8x | IC604 (5V reg), IC602 (9V reg) |
| Sem varredura vertical | IC804 (STV9302A), V-Out stage |
| Sem imagem, raster ok | IC001, ajuste White Balance, G2 |
| Misconvergência cantos | Piece A(90) Permaloy, magnetos |
| Sem cor | IC001 (color decoder), ajuste SCOL/SHUE |

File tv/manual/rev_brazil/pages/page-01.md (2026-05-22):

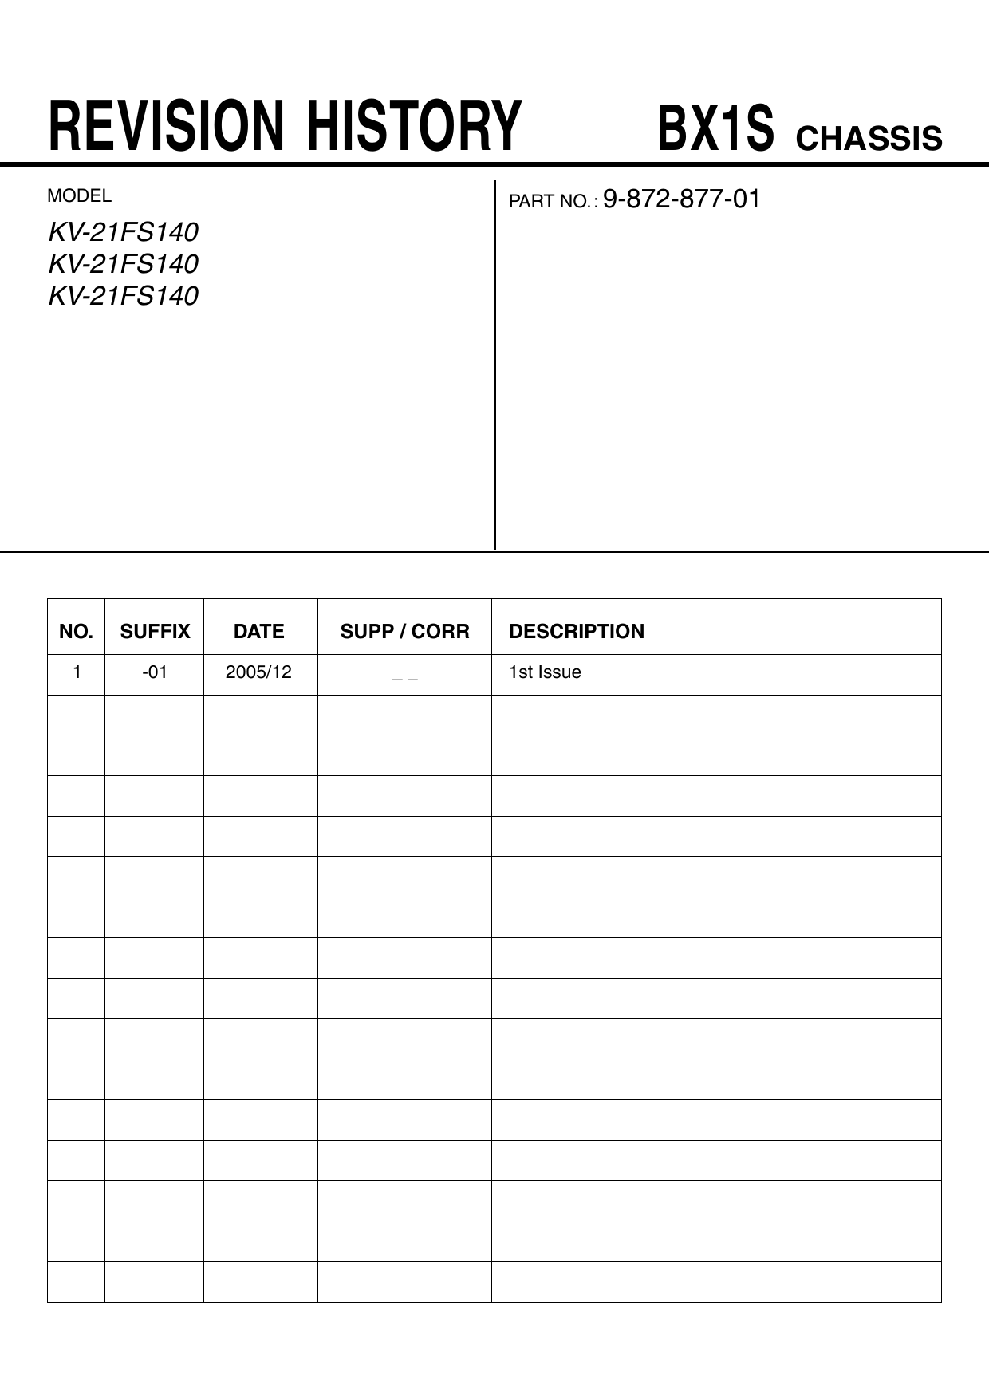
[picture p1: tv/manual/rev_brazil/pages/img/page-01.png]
page-01


REVISION HISTORY

BX1S CHASSIS

PART NO. : 9-872-877-01

MODEL

KV-21FS140
KV-21FS140
KV-21FS140

NO.

SUFFIX

DATE

SUPP / CORR

1

-01

2005/12

__

DESCRIPTION
1st Issue

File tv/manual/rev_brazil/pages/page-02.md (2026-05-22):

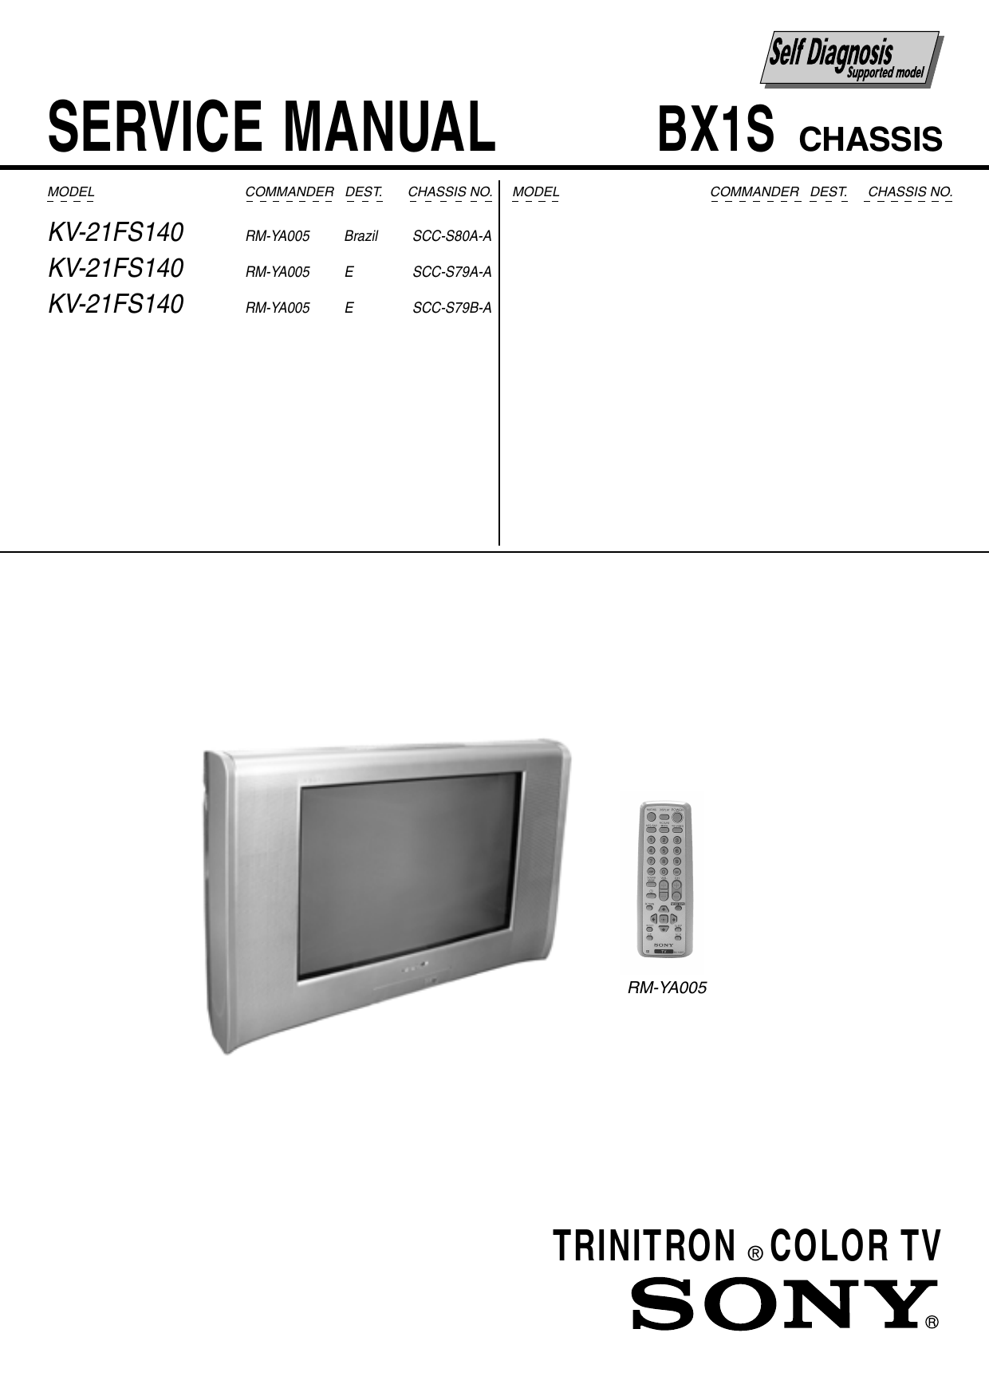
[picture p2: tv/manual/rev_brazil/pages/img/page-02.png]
page-02


SERVICE MANUAL
MODEL

KV-21FS140
KV-21FS140
KV-21FS140

COMMANDER DEST.

CHASSIS NO.

RM-YA005

Brazil

SCC-S80A-A

RM-YA005

E

SCC-S79A-A

RM-YA005

E

SCC-S79B-A

BX1S CHASSIS
MODEL

COMMANDER DEST.

CHASSIS NO.

RM-YA005

TRINITRON ® COLOR TV

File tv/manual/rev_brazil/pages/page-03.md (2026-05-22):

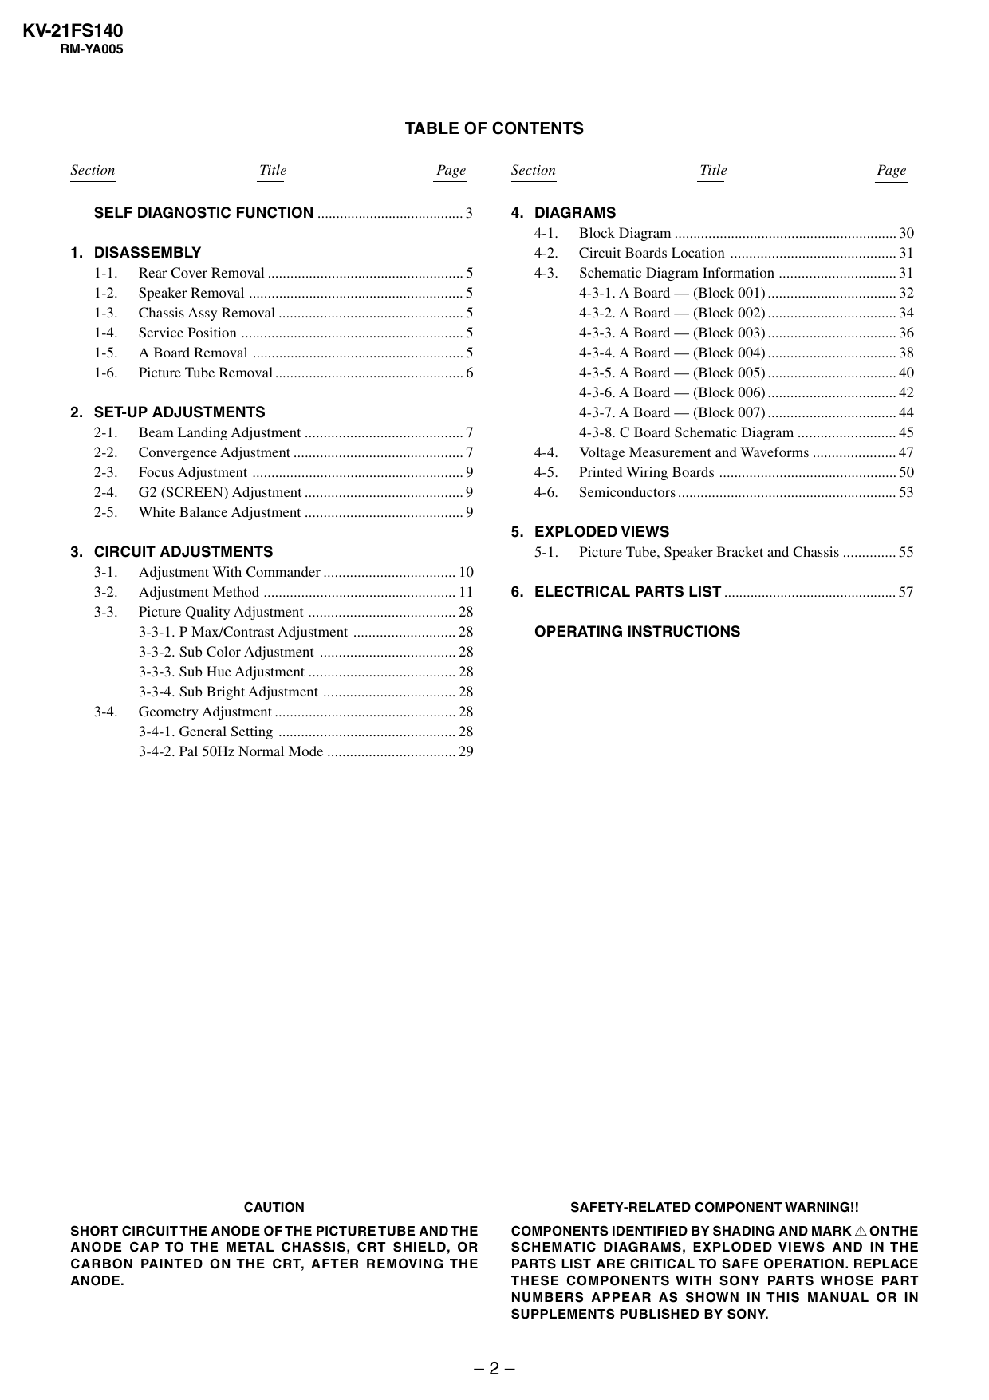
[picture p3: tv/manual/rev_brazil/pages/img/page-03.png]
page-03


KV-21FS140
RM-YA005

TABLE OF CONTENTS
Section

Title

Page

Section

Title

Page

4. DIAGRAMS
4-1. Block Diagram ........................................................... 30
4-2. Circuit Boards Location ............................................ 31
4-3. Schematic Diagram Information ............................... 31
4-3-1. A Board — (Block 001) .................................. 32
4-3-2. A Board — (Block 002) .................................. 34
4-3-3. A Board — (Block 003) .................................. 36
4-3-4. A Board — (Block 004) .................................. 38
4-3-5. A Board — (Block 005) .................................. 40
4-3-6. A Board — (Block 006) .................................. 42
4-3-7. A Board — (Block 007) .................................. 44
4-3-8. C Board Schematic Diagram .......................... 45
4-4. Voltage Measurement and Waveforms ...................... 47
4-5. Printed Wiring Boards ............................................... 50
4-6. Semiconductors .......................................................... 53

SELF DIAGNOSTIC FUNCTION ....................................... 3
1. DISASSEMBLY
1-1. Rear Cover Removal .................................................... 5
1-2. Speaker Removal ......................................................... 5
1-3. Chassis Assy Removal ................................................. 5
1-4. Service Position ........................................................... 5
1-5. A Board Removal ........................................................ 5
1-6. Picture Tube Removal .................................................. 6
2. SET-UP ADJUSTMENTS
2-1. Beam Landing Adjustment .......................................... 7
2-2. Convergence Adjustment ............................................. 7
2-3. Focus Adjustment ........................................................ 9
2-4. G2 (SCREEN) Adjustment .......................................... 9
2-5. White Balance Adjustment .......................................... 9

5. EXPLODED VIEWS
5-1. Picture Tube, Speaker Bracket and Chassis .............. 55

3. CIRCUIT ADJUSTMENTS
3-1. Adjustment With Commander ................................... 10
3-2. Adjustment Method ................................................... 11
3-3. Picture Quality Adjustment ....................................... 28
3-3-1. P Max/Contrast Adjustment ........................... 28
3-3-2. Sub Color Adjustment .................................... 28
3-3-3. Sub Hue Adjustment ....................................... 28
3-3-4. Sub Bright Adjustment ................................... 28
3-4. Geometry Adjustment ................................................ 28
3-4-1. General Setting ............................................... 28
3-4-2. Pal 50Hz Normal Mode .................................. 29

6. ELECTRICAL PARTS LIST .............................................. 57
OPERATING INSTRUCTIONS

CAUTION

SAFETY-RELATED COMPONENT WARNING!!

SHORT CIRCUIT THE ANODE OF THE PICTURE TUBE AND THE
ANODE CAP TO THE METAL CHASSIS, CRT SHIELD, OR
CARBON PAINTED ON THE CRT, AFTER REMOVING THE
ANODE.

COMPONENTS IDENTIFIED BY SHADING AND MARK ! ON THE
SCHEMATIC DIAGRAMS, EXPLODED VIEWS AND IN THE
PARTS LIST ARE CRITICAL TO SAFE OPERATION. REPLACE
THESE COMPONENTS WITH SONY PARTS WHOSE PART
NUMBERS APPEAR AS SHOWN IN THIS MANUAL OR IN
SUPPLEMENTS PUBLISHED BY SONY.

–2–

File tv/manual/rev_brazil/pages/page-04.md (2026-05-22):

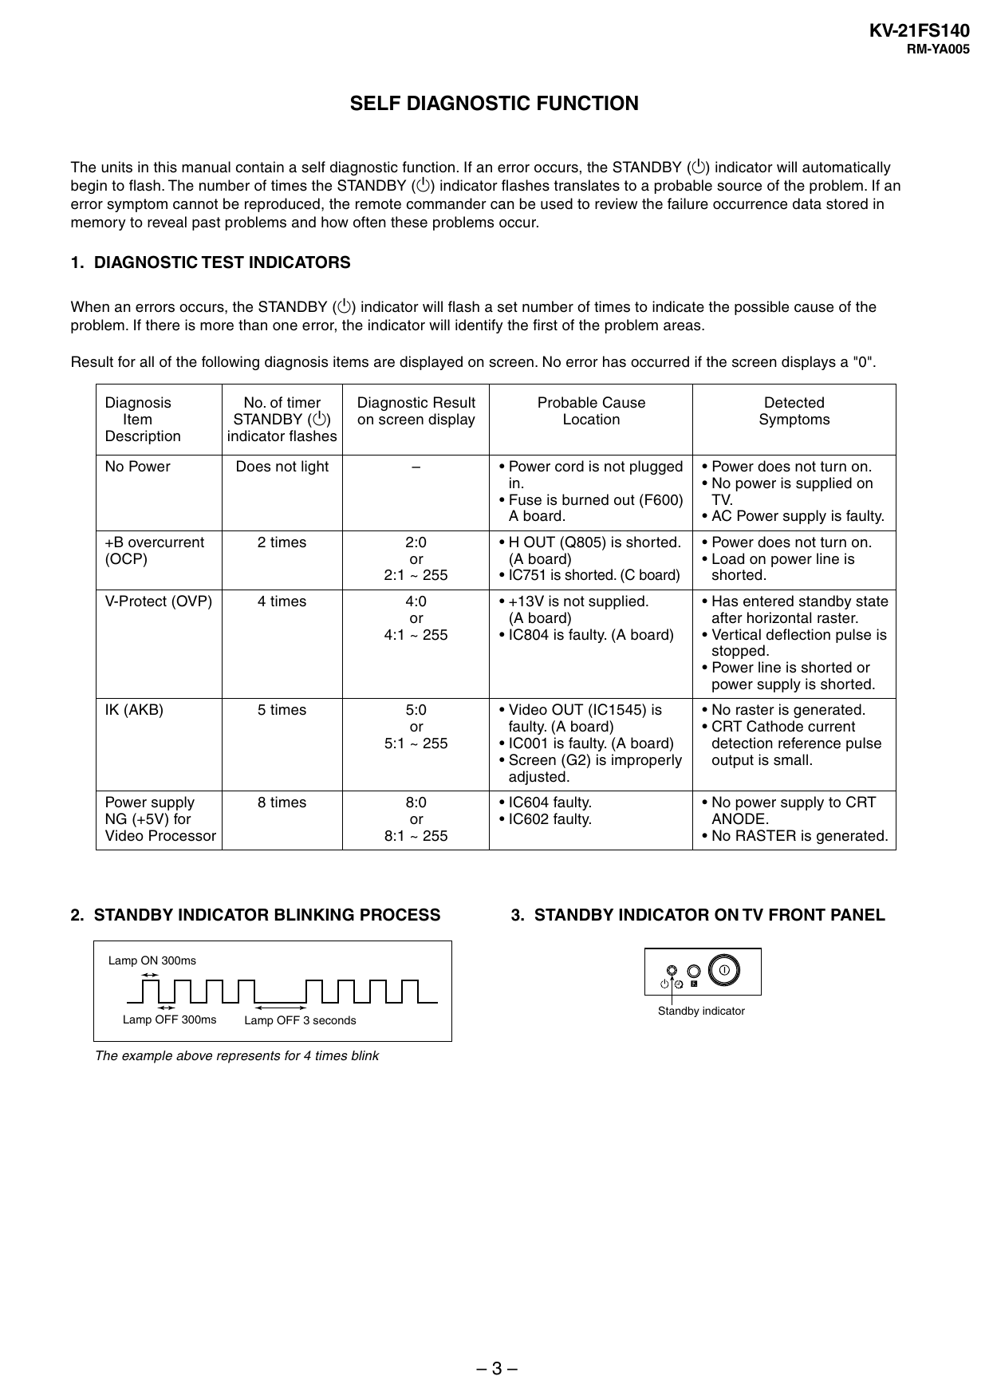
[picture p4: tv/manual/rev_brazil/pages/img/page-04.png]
page-04


KV-21FS140
RM-YA005

SELF DIAGNOSTIC FUNCTION
The units in this manual contain a self diagnostic function. If an error occurs, the STANDBY (1) indicator will automatically
begin to flash. The number of times the STANDBY (1) indicator flashes translates to a probable source of the problem. If an
error symptom cannot be reproduced, the remote commander can be used to review the failure occurrence data stored in
memory to reveal past problems and how often these problems occur.

1. DIAGNOSTIC TEST INDICATORS
When an errors occurs, the STANDBY (1) indicator will flash a set number of times to indicate the possible cause of the
problem. If there is more than one error, the indicator will identify the first of the problem areas.
Result for all of the following diagnosis items are displayed on screen. No error has occurred if the screen displays a "0".
Diagnosis
Item
Description

No. of timer
STANDBY (1)
indicator flashes

Diagnostic Result
on screen display

Probable Cause
Location

Detected
Symptoms

No Power

Does not light

–

• Power cord is not plugged
in.
• Fuse is burned out (F600)
A board.

• Power does not turn on.
• No power is supplied on
TV.
• AC Power supply is faulty.

+B overcurrent
(OCP)

2 times

2:0
or
2:1 ~ 255

• H OUT (Q805) is shorted.
(A board)
• IC751 is shorted. (C board)

• Power does not turn on.
• Load on power line is
shorted.

V-Protect (OVP)

4 times

4:0
or
4:1 ~ 255

• +13V is not supplied.
(A board)
• IC804 is faulty. (A board)

• Has entered standby state
after horizontal raster.
• Vertical deflection pulse is
stopped.
• Power line is shorted or
power supply is shorted.

IK (AKB)

5 times

5:0
or
5:1 ~ 255

• Video OUT (IC1545) is
faulty. (A board)
• IC001 is faulty. (A board)
• Screen (G2) is improperly
adjusted.

• No raster is generated.
• CRT Cathode current
detection reference pulse
output is small.

Power supply
NG (+5V) for
Video Processor

8 times

8:0
or
8:1 ~ 255

• IC604 faulty.
• IC602 faulty.

• No power supply to CRT
ANODE.
• No RASTER is generated.

2. STANDBY INDICATOR BLINKING PROCESS

3. STANDBY INDICATOR ON TV FRONT PANEL

Lamp ON 300ms

Lamp OFF 300ms

Standby indicator

Lamp OFF 3 seconds

The example above represents for 4 times blink

–3–

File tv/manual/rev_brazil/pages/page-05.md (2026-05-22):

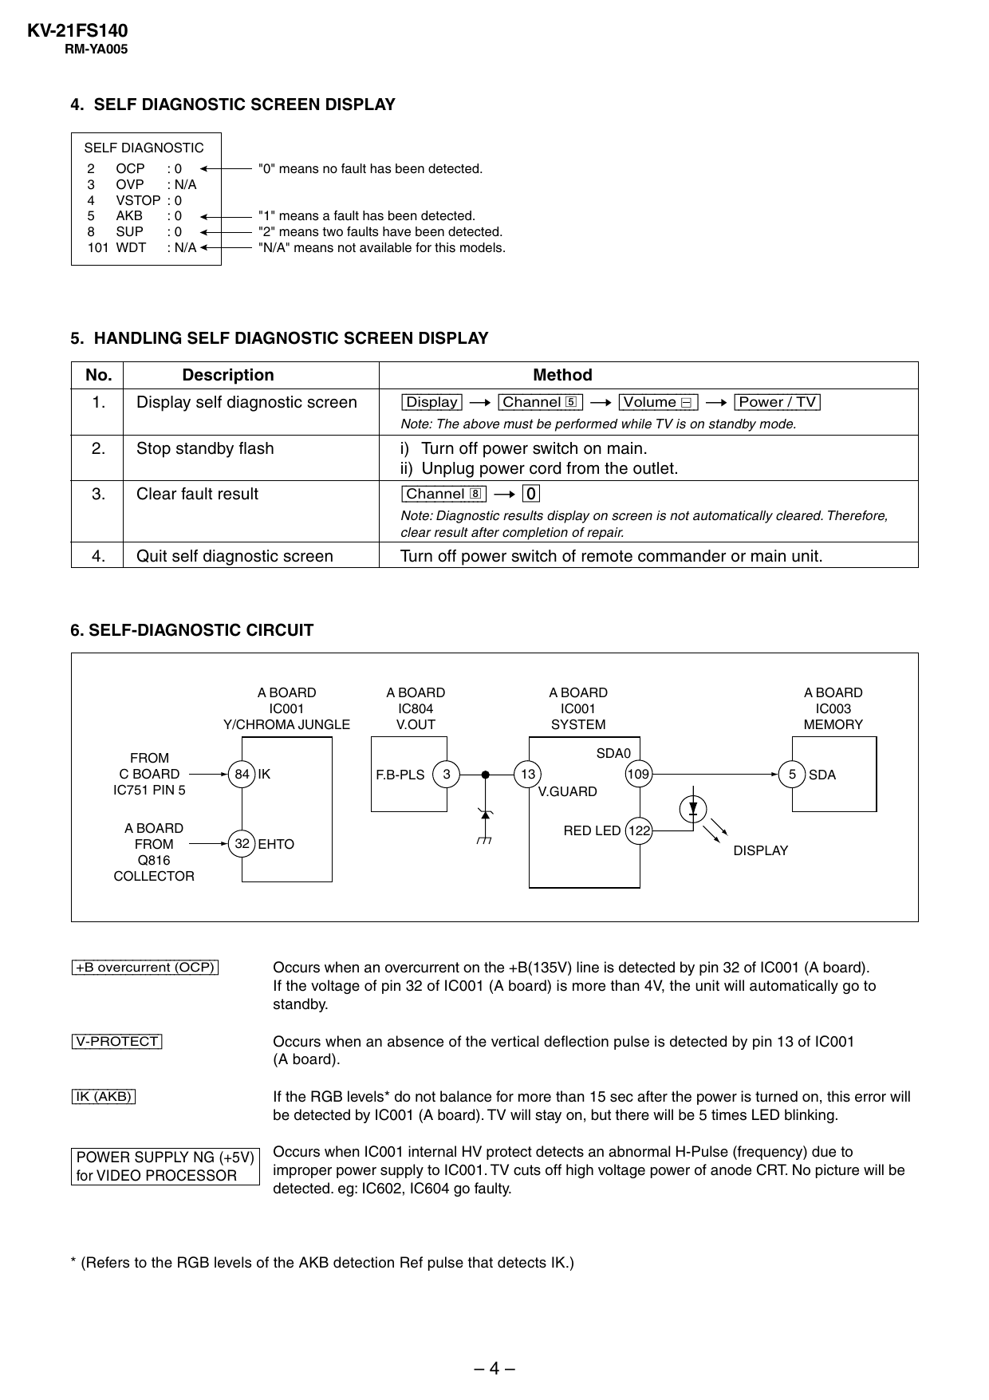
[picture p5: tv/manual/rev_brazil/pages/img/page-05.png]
page-05


KV-21FS140
RM-YA005

4. SELF DIAGNOSTIC SCREEN DISPLAY
SELF DIAGNOSTIC
2
OCP
:0
3
OVP
: N/A
4
VSTOP : 0
5
AKB
:0
8
SUP
:0
101 WDT
: N/A

"0" means no fault has been detected.

"1" means a fault has been detected.
"2" means two faults have been detected.
"N/A" means not available for this models.

5. HANDLING SELF DIAGNOSTIC SCREEN DISPLAY
No.
1.

Description
Display self diagnostic screen

Method

[Display] t [Channel 5 ] t [Volume ] t [Power / TV]
Note: The above must be performed while TV is on standby mode.

2.

Stop standby flash

i) Turn off power switch on main.
ii) Unplug power cord from the outlet.

3.

Clear fault result

[Channel 8] t Note: Diagnostic results display on screen is not automatically cleared. Therefore,
clear result after completion of repair.

4.

Quit self diagnostic screen

Turn off power switch of remote commander or main unit.

6. SELF-DIAGNOSTIC CIRCUIT

A BOARD
IC001
Y/CHROMA JUNGLE
FROM
C BOARD
IC751 PIN 5
A BOARD
FROM
Q816
COLLECTOR

A BOARD
IC804
V.OUT

A BOARD
IC001
SYSTEM

A BOARD
IC003
MEMORY

SDA0
84 IK

F.B-PLS

3

109

13

5 SDA

V.GUARD
RED LED 122
32 EHTO

DISPLAY

[+B overcurrent $OCP%]

Occurs when an overcurrent on the +B(135V) line is detected by pin 32 of IC001 (A board).
If the voltage of pin 32 of IC001 (A board) is more than 4V, the unit will automatically go to
standby.

[V-PROTECT]

Occurs when an absence of the vertical deflection pulse is detected by pin 13 of IC001
(A board).

[IK $AKB%]

If the RGB levels* do not balance for more than 15 sec after the power is turned on, this error will
be detected by IC001 (A board). TV will stay on, but there will be 5 times LED blinking.

POWER SUPPLY NG (+5V)
for VIDEO PROCESSOR

Occurs when IC001 internal HV protect detects an abnormal H-Pulse (frequency) due to
improper power supply to IC001. TV cuts off high voltage power of anode CRT. No picture will be
detected. eg: IC602, IC604 go faulty.

* (Refers to the RGB levels of the AKB detection Ref pulse that detects IK.)

–4–

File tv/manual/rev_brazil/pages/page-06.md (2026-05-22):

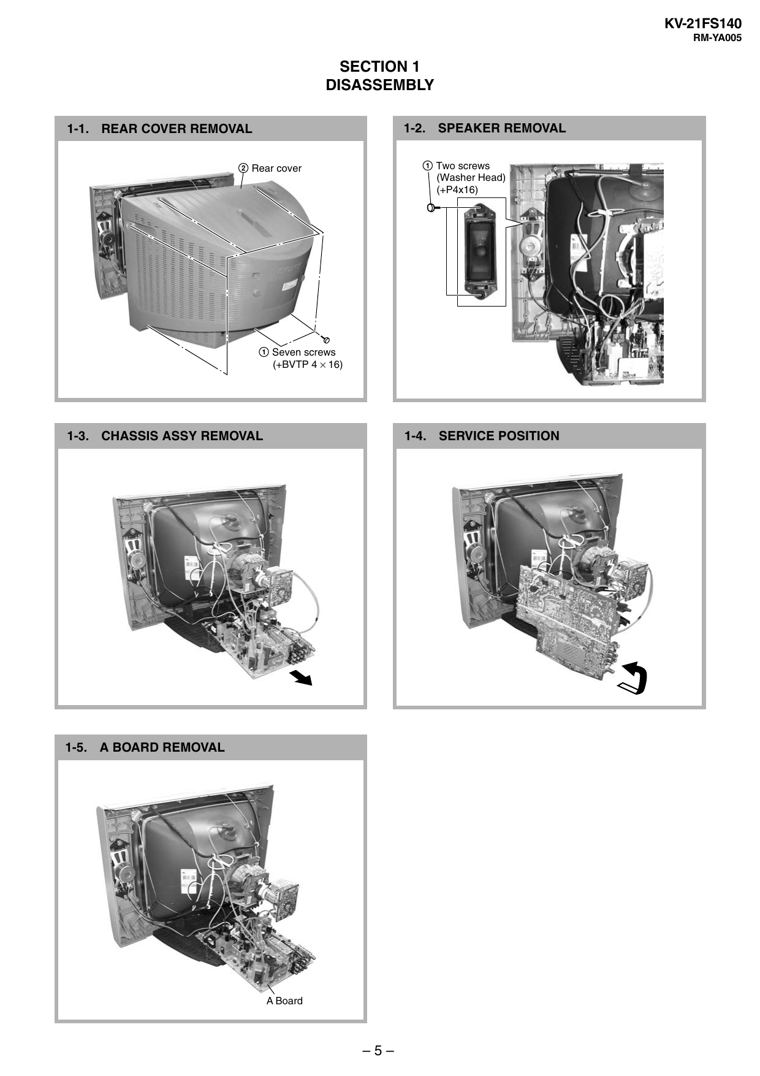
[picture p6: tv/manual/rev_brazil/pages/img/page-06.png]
page-06


KV-21FS140
RM-YA005

SECTION 1
DISASSEMBLY
1-2. SPEAKER REMOVAL

1-1. REAR COVER REMOVAL

1 Two screws
(Washer Head)
(+P4x16)

2 Rear cover

1 Seven screws
(+BVTP 4 × 16)

1-4. SERVICE POSITION

1-3. CHASSIS ASSY REMOVAL

1-5. A BOARD REMOVAL

A Board

–5–

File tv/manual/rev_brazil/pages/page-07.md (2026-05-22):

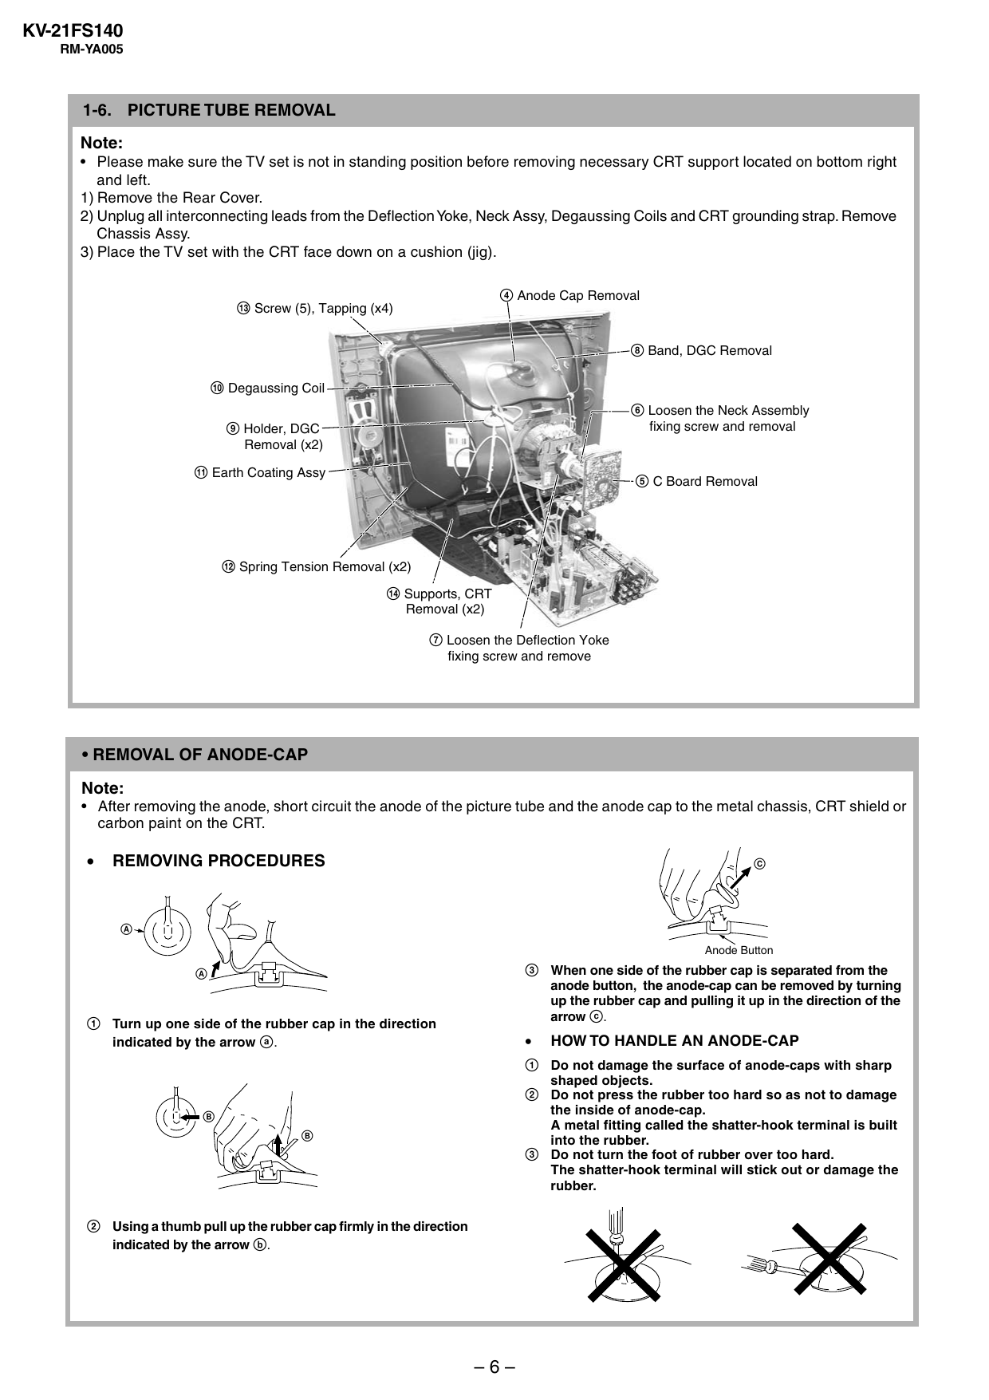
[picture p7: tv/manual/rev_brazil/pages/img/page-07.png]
page-07


KV-21FS140
RM-YA005

1-6. PICTURE TUBE REMOVAL
Note:
• Please make sure the TV set is not in standing position before removing necessary CRT support located on bottom right
and left.
1) Remove the Rear Cover.
2) Unplug all interconnecting leads from the Deflection Yoke, Neck Assy, Degaussing Coils and CRT grounding strap. Remove
Chassis Assy.
3) Place the TV set with the CRT face down on a cushion (jig).
4 Anode Cap Removal
qd Screw (5), Tapping (x4)
8 Band, DGC Removal
0 Degaussing Coil
6 Loosen the Neck Assembly
fixing screw and removal

9 Holder, DGC
Removal (x2)
qa Earth Coating Assy

5 C Board Removal

qs Spring Tension Removal (x2)
qf Supports, CRT
Removal (x2)
7 Loosen the Deflection Yoke
fixing screw and remove

• REMOVAL OF ANODE-CAP
Note:
• After removing the anode, short circuit the anode of the picture tube and the anode cap to the metal chassis, CRT shield or
carbon paint on the CRT.

•

REMOVING PROCEDURES

C

A
Anode Button

3 When one side of the rubber cap is separated from the
anode button, the anode-cap can be removed by turning
up the rubber cap and pulling it up in the direction of the
arrow c.

A

1 Turn up one side of the rubber cap in the direction
indicated by the arrow a.

•

HOW TO HANDLE AN ANODE-CAP

1 Do not damage the surface of anode-caps with sharp
shaped objects.
2 Do not press the rubber too hard so as not to damage
the inside of anode-cap.
A metal fitting called the shatter-hook terminal is built
into the rubber.
3 Do not turn the foot of rubber over too hard.
The shatter-hook terminal will stick out or damage the
rubber.

B
B

2 Using a thumb pull up the rubber cap firmly in the direction
indicated by the arrow b.

–6–

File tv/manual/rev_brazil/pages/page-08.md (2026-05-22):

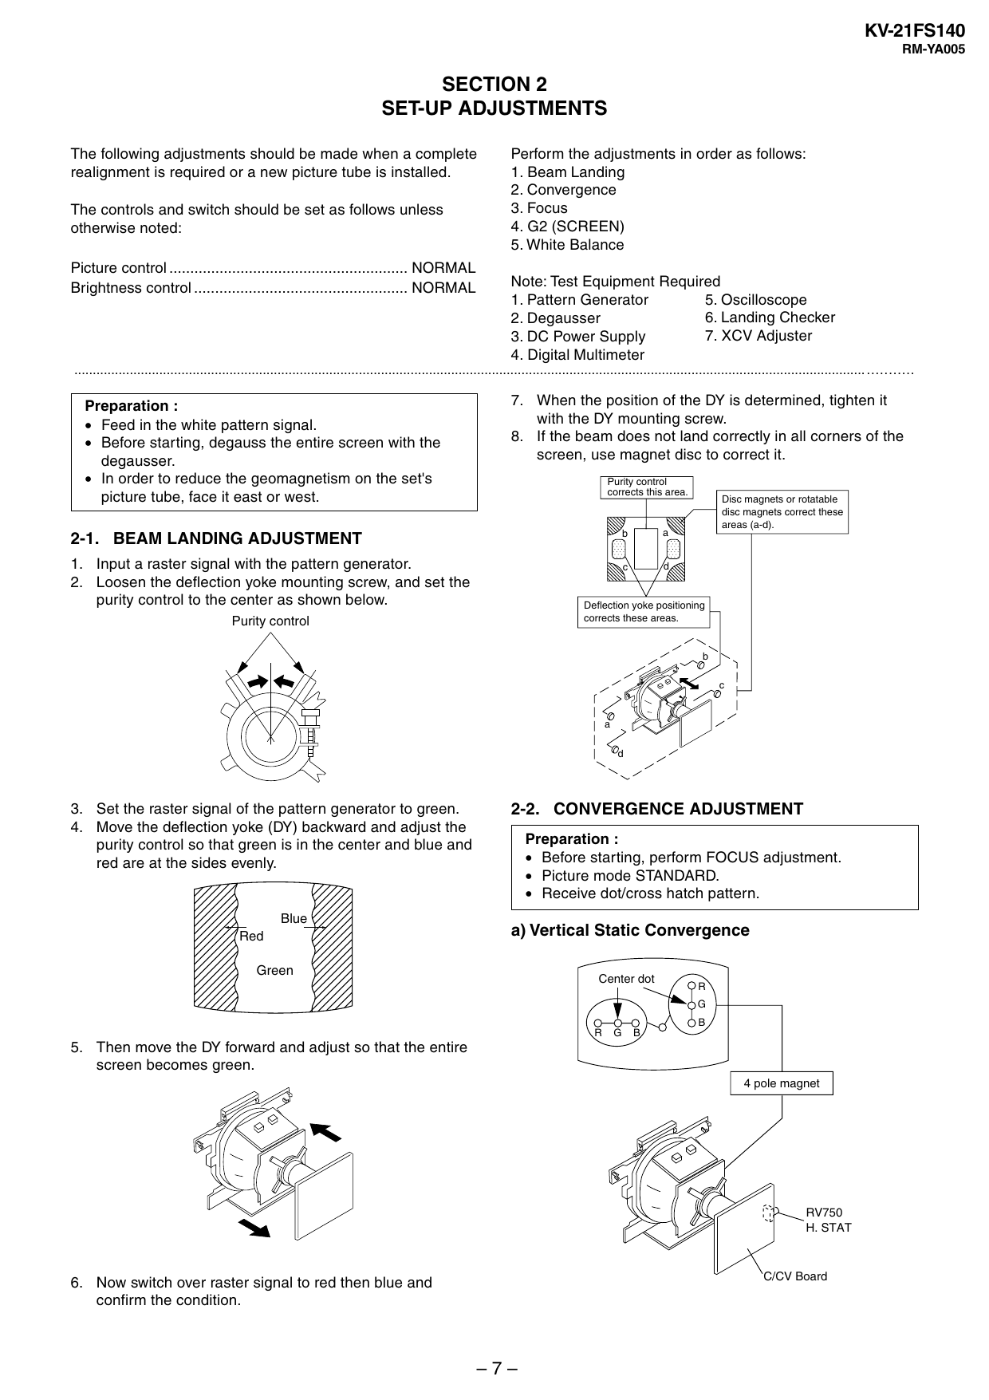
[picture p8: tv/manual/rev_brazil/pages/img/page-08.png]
page-08


KV-21FS140
RM-YA005

SECTION 2
SET-UP ADJUSTMENTS
The following adjustments should be made when a complete
realignment is required or a new picture tube is installed.
The controls and switch should be set as follows unless
otherwise noted:
Picture control ......................................................... NORMAL
Brightness control ................................................... NORMAL

Perform the adjustments in order as follows:
1. Beam Landing
2. Convergence
3. Focus
4. G2 (SCREEN)
5. White Balance
Note: Test Equipment Required
5. Oscilloscope
1. Pattern Generator
6. Landing Checker
2. Degausser
7. XCV Adjuster
3. DC Power Supply
4. Digital Multimeter

...................................................................................................................................................................................................................... ...........

Preparation :
• Feed in the white pattern signal.
• Before starting, degauss the entire screen with the
degausser.
• In order to reduce the geomagnetism on the set's
picture tube, face it east or west.

7. When the position of the DY is determined, tighten it
with the DY mounting screw.
8. If the beam does not land correctly in all corners of the
screen, use magnet disc to correct it.
Purity control
corrects this area.

2-1. BEAM LANDING ADJUSTMENT

b

a

1. Input a raster signal with the pattern generator.
2. Loosen the deflection yoke mounting screw, and set the
purity control to the center as shown below.

c

d

Disc magnets or rotatable
disc magnets correct these
areas (a-d).

Deflection yoke positioning
corrects these areas.

Purity control

b
c

a
d

3. Set the raster signal of the pattern generator to green.
4. Move the deflection yoke (DY) backward and adjust the
purity control so that green is in the center and blue and
red are at the sides evenly.

Blue
Red

2-2. CONVERGENCE ADJUSTMENT
Preparation :
• Before starting, perform FOCUS adjustment.
• Picture mode STANDARD.
• Receive dot/cross hatch pattern.

a) Vertical Static Convergence

Green

Center dot

R
G
B

R

G

B

5. Then move the DY forward and adjust so that the entire
screen becomes green.
4 pole magnet

RV750
H. STAT

C/CV Board

6. Now switch over raster signal to red then blue and
confirm the condition.

–7–

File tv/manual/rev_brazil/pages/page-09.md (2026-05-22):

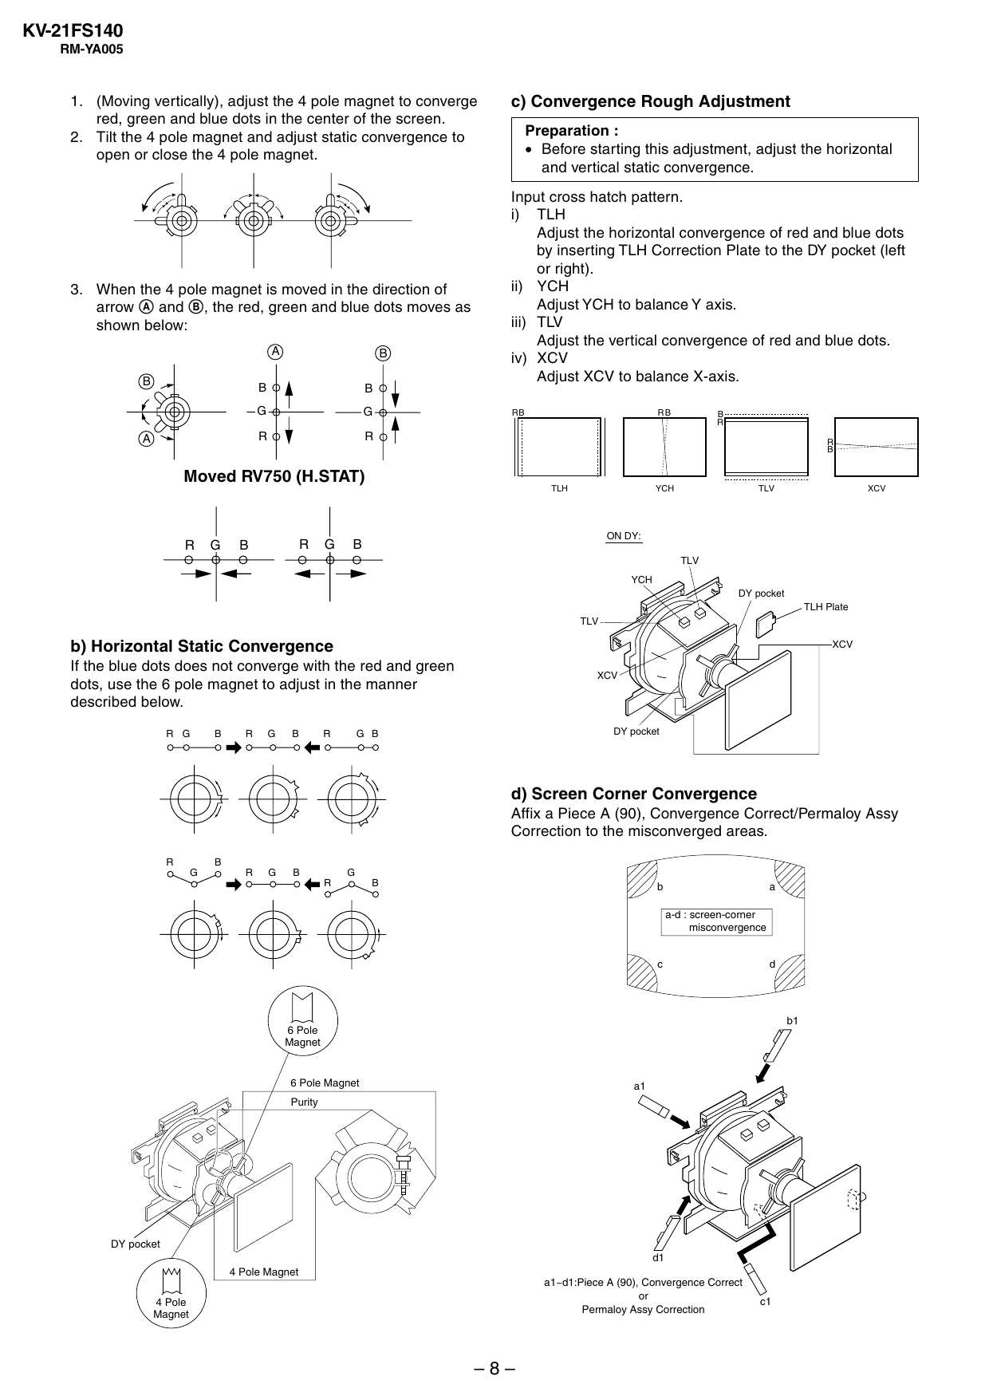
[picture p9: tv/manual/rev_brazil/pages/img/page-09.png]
page-09


KV-21FS140
RM-YA005

1. (Moving vertically), adjust the 4 pole magnet to converge
red, green and blue dots in the center of the screen.
2. Tilt the 4 pole magnet and adjust static convergence to
open or close the 4 pole magnet.

3. When the 4 pole magnet is moved in the direction of
arrow A and B, the red, green and blue dots moves as
shown below:
A
B

A

B

B

B

G

G

R

R

c) Convergence Rough Adjustment
Preparation :
• Before starting this adjustment, adjust the horizontal
and vertical static convergence.
Input cross hatch pattern.
i) TLH
Adjust the horizontal convergence of red and blue dots
by inserting TLH Correction Plate to the DY pocket (left
or right).
ii) YCH
Adjust YCH to balance Y axis.
iii) TLV
Adjust the vertical convergence of red and blue dots.
iv) XCV
Adjust XCV to balance X-axis.

G

R

B

G

B
R
R
B

Moved RV750 (H.STAT)

R

RB

RB

YCH

TLH

XCV

TLV

ON DY:

B

TLV
YCH
DY pocket
TLH Plate
TLV

b) Horizontal Static Convergence

XCV

If the blue dots does not converge with the red and green
dots, use the 6 pole magnet to adjust in the manner
described below.
R G

B

R

G

B

R

XCV

DY pocket

G B

d) Screen Corner Convergence
Affix a Piece A (90), Convergence Correct/Permaloy Assy
Correction to the misconverged areas.
R

B
G

R

G

B

G
R

B

b

a
a-d : screen-corner
misconvergence

c

d

b1

6 Pole
Magnet

6 Pole Magnet

a1

Purity

DY pocket
d1

4 Pole Magnet
a1~d1:Piece A (90), Convergence Correct
or
Permaloy Assy Correction

4 Pole
Magnet

–8–

c1

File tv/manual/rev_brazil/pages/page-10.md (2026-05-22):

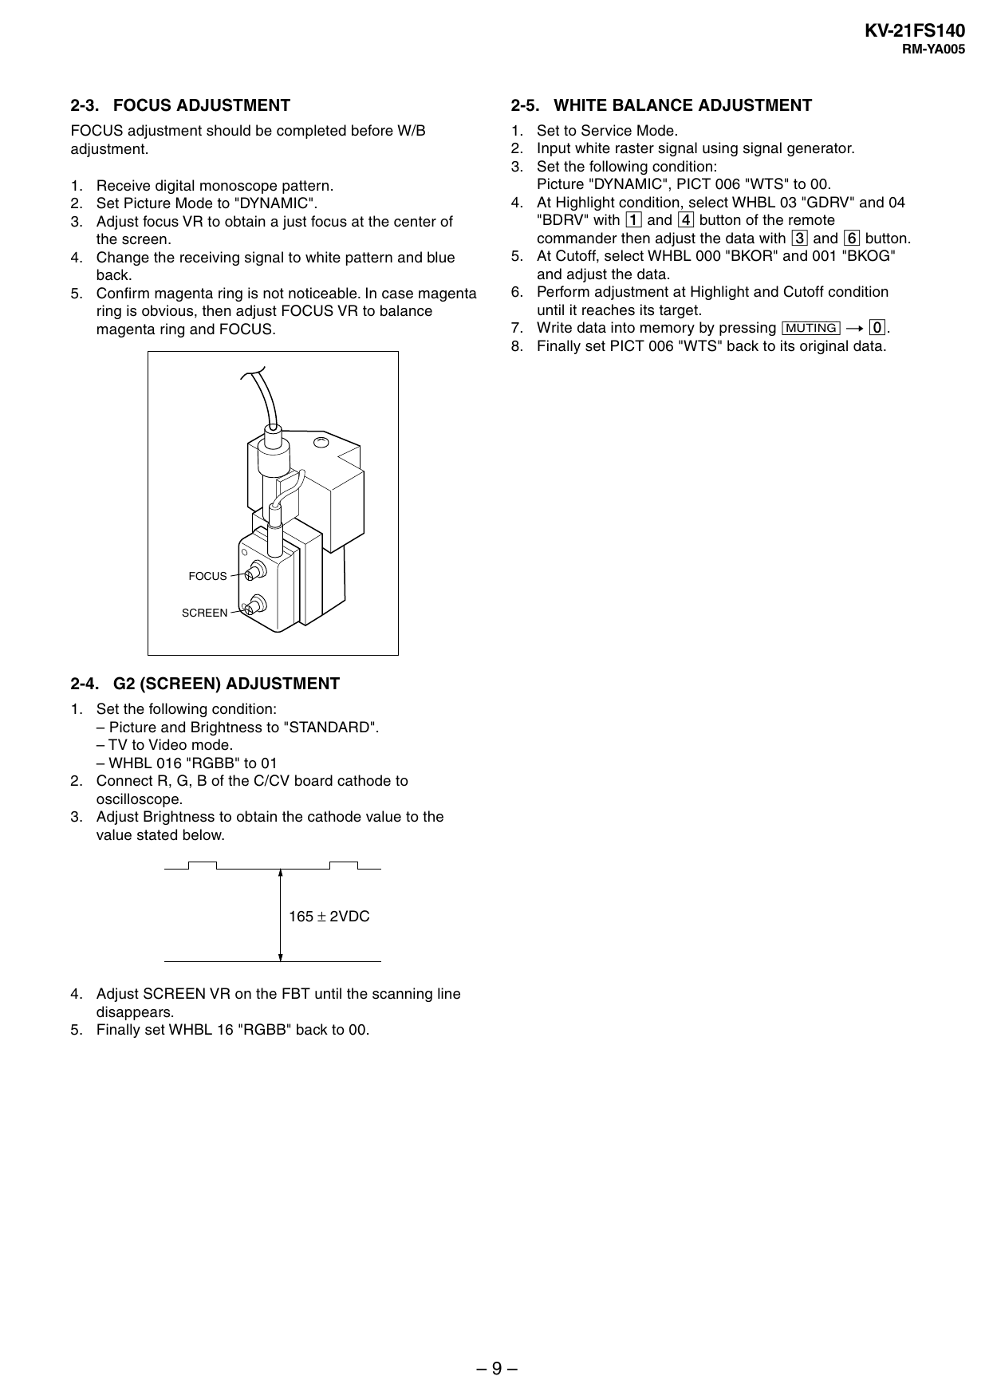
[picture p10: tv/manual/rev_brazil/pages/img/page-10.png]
page-10


KV-21FS140
RM-YA005

2-3. FOCUS ADJUSTMENT

2-5. WHITE BALANCE ADJUSTMENT

FOCUS adjustment should be completed before W/B
adjustment.

1. Set to Service Mode.
2. Input white raster signal using signal generator.
3. Set the following condition:
Picture "DYNAMIC", PICT 006 "WTS" to 00.
4. At Highlight condition, select WHBL 03 "GDRV" and 04
"BDRV" with 1 and 4 button of the remote
commander then adjust the data with 3 and 6 button.
5. At Cutoff, select WHBL 000 "BKOR" and 001 "BKOG"
and adjust the data.
6. Perform adjustment at Highlight and Cutoff condition
until it reaches its target.
7. Write data into memory by pressing [MUTING] t -.
8. Finally set PICT 006 "WTS" back to its original data.

1. Receive digital monoscope pattern.
2. Set Picture Mode to "DYNAMIC".
3. Adjust focus VR to obtain a just focus at the center of
the screen.
4. Change the receiving signal to white pattern and blue
back.
5. Confirm magenta ring is not noticeable. In case magenta
ring is obvious, then adjust FOCUS VR to balance
magenta ring and FOCUS.

FOCUS
SCREEN

2-4. G2 (SCREEN) ADJUSTMENT
1. Set the following condition:
– Picture and Brightness to "STANDARD".
– TV to Video mode.
– WHBL 016 "RGBB" to 01
2. Connect R, G, B of the C/CV board cathode to
oscilloscope.
3. Adjust Brightness to obtain the cathode value to the
value stated below.

165 ± 2VDC

4. Adjust SCREEN VR on the FBT until the scanning line
disappears.
5. Finally set WHBL 16 "RGBB" back to 00.

–9–

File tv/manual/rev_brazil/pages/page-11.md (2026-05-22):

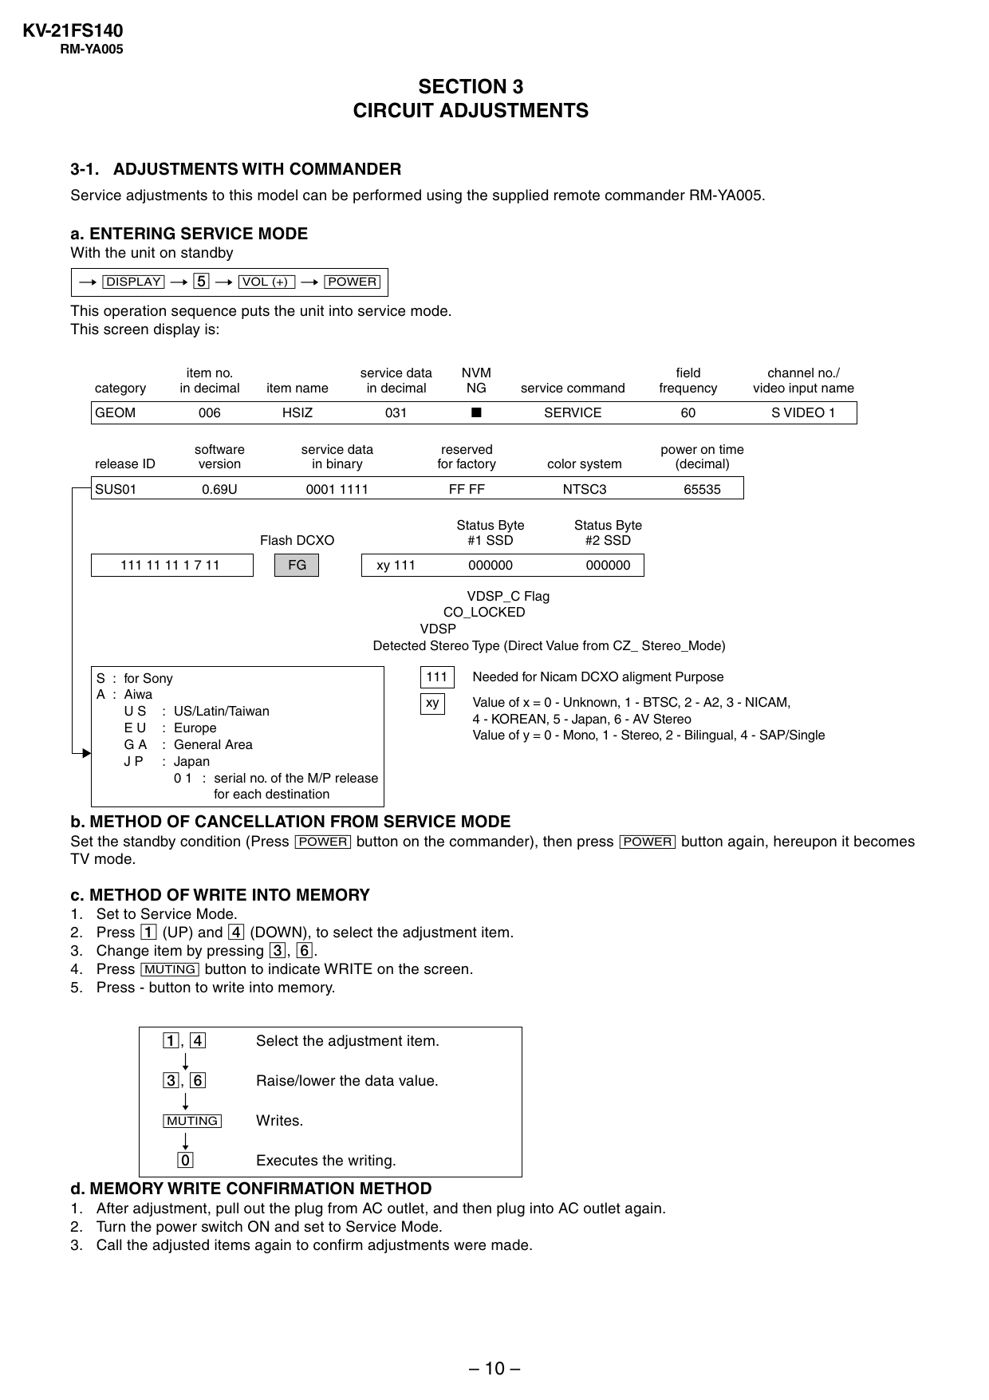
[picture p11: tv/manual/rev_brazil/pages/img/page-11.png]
page-11


KV-21FS140
RM-YA005

SECTION 3
CIRCUIT ADJUSTMENTS
3-1. ADJUSTMENTS WITH COMMANDER
Service adjustments to this model can be performed using the supplied remote commander RM-YA005.

a. ENTERING SERVICE MODE
With the unit on standby
t [DISPLAY] t 5 t [VOL $+% ] t [POWER]
This operation sequence puts the unit into service mode.
This screen display is:

category

item no.
in decimal

item name

service data
in decimal

NVM
NG

service command

field
frequency

channel no./
video input name

GEOM

006

HSIZ

031

x

SERVICE

60

S VIDEO 1

release ID

software
version

service data
in binary

reserved
for factory

color system

power on time
(decimal)

SUS01

0.69U

0001 1111

FF FF

NTSC3

65535

Flash DCXO
111 11 11 1 7 11

FG

xy 111

Status Byte
#1 SSD

Status Byte
#2 SSD

000000

000000

VDSP_C Flag
CO_LOCKED
VDSP
Detected Stereo Type (Direct Value from CZ_ Stereo_Mode)
S : for Sony
A : Aiwa
U S : US/Latin/Taiwan
E U : Europe
G A : General Area
J P : Japan
0 1 : serial no. of the M/P release
for each destination

111

Needed for Nicam DCXO aligment Purpose

xy

Value of x = 0 - Unknown, 1 - BTSC, 2 - A2, 3 - NICAM,
4 - KOREAN, 5 - Japan, 6 - AV Stereo
Value of y = 0 - Mono, 1 - Stereo, 2 - Bilingual, 4 - SAP/Single

b. METHOD OF CANCELLATION FROM SERVICE MODE
Set the standby condition (Press [POWER] button on the commander), then press [POWER] button again, hereupon it becomes
TV mode.

c. METHOD OF WRITE INTO MEMORY
1.
2.
3.
4.
5.

Set to Service Mode.
Press 1 (UP) and 4 (DOWN), to select the adjustment item.
Change item by pressing 3, 6.
Press [MUTING] button to indicate WRITE on the screen.
Press - button to write into memory.

1, 4
r
3, 6
r
[MUTING]
r
-

Select the adjustment item.
Raise/lower the data value.
Writes.
Executes the writing.

d. MEMORY WRITE CONFIRMATION METHOD
1. After adjustment, pull out the plug from AC outlet, and then plug into AC outlet again.
2. Turn the power switch ON and set to Service Mode.
3. Call the adjusted items again to confirm adjustments were made.

– 10 –

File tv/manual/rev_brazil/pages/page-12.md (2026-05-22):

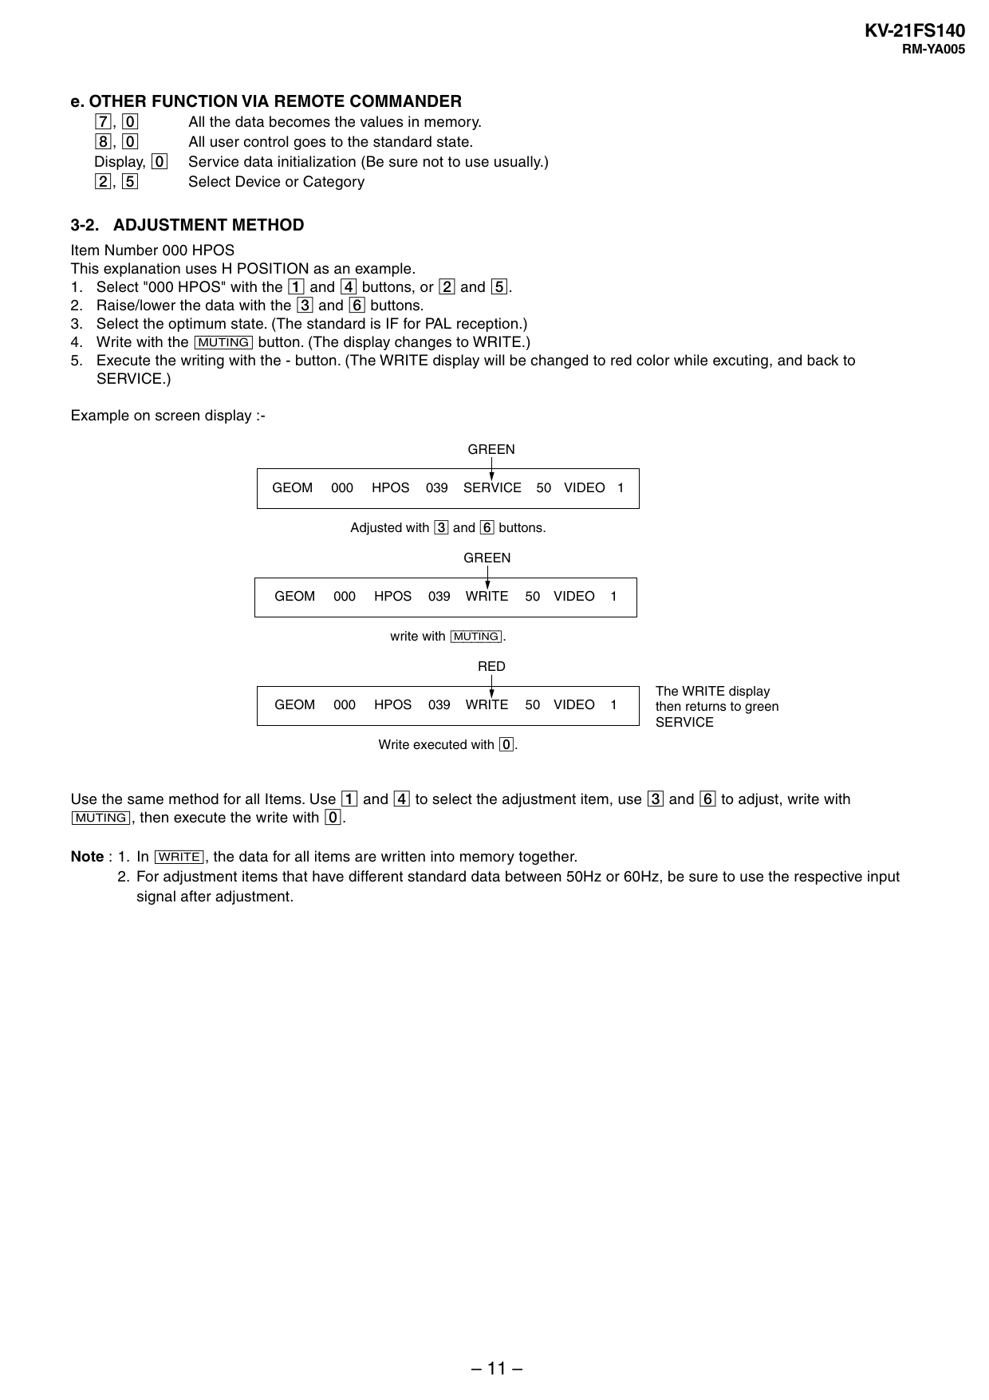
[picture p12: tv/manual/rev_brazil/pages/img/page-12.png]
page-12


KV-21FS140
RM-YA005

e. OTHER FUNCTION VIA REMOTE COMMANDER
7, 8, Display, 2, 5

All the data becomes the values in memory.
All user control goes to the standard state.
Service data initialization (Be sure not to use usually.)
Select Device or Category

3-2. ADJUSTMENT METHOD
Item Number 000 HPOS
This explanation uses H POSITION as an example.
1. Select "000 HPOS" with the 1 and 4 buttons, or 2 and 5.
2. Raise/lower the data with the 3 and 6 buttons.
3. Select the optimum state. (The standard is IF for PAL reception.)
4. Write with the [MUTING] button. (The display changes to WRITE.)
5. Execute the writing with the - button. (The WRITE display will be changed to red color while excuting, and back to
SERVICE.)
Example on screen display :GREEN
GEOM

000

HPOS

039

SERVICE

50 VIDEO 1

Adjusted with 3 and 6 buttons.
GREEN
GEOM

000

HPOS

039

WRITE

50

VIDEO

1

50

VIDEO

1

write with [MUTING].
RED
GEOM

000

HPOS

039

WRITE

The WRITE display
then returns to green
SERVICE

Write executed with -.

Use the same method for all Items. Use 1 and 4 to select the adjustment item, use 3 and 6 to adjust, write with
[MUTING], then execute the write with -.
Note : 1. In [WRITE], the data for all items are written into memory together.
2. For adjustment items that have different standard data between 50Hz or 60Hz, be sure to use the respective input
signal after adjustment.

– 11 –

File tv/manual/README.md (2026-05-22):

# Manuais — KV-21FS140

Dois manuais do mesmo modelo (KV-21FS140). Algumas informações existem só em um — consultar ambos se necessário.

| Pasta | Variante | Páginas | Destino | Índice |
|---|---|---|---|---|
| `rev_brazil/` | SCC-S80A-A | 57 | Brazil (PAL/NTSC multi) | [INDEX.md](rev_brazil/INDEX.md) |
| `rev_s79aa/` | SCC-S79A-A/B | 69 | Latin North/South (NTSC only) | [INDEX.md](rev_s79aa/INDEX.md) |

Cada pasta tem o PDF original e `pages/` com imagens (PNG 300dpi) e texto extraído por página.

Diferenças documentadas nos arquivos de `../../circuits/`.

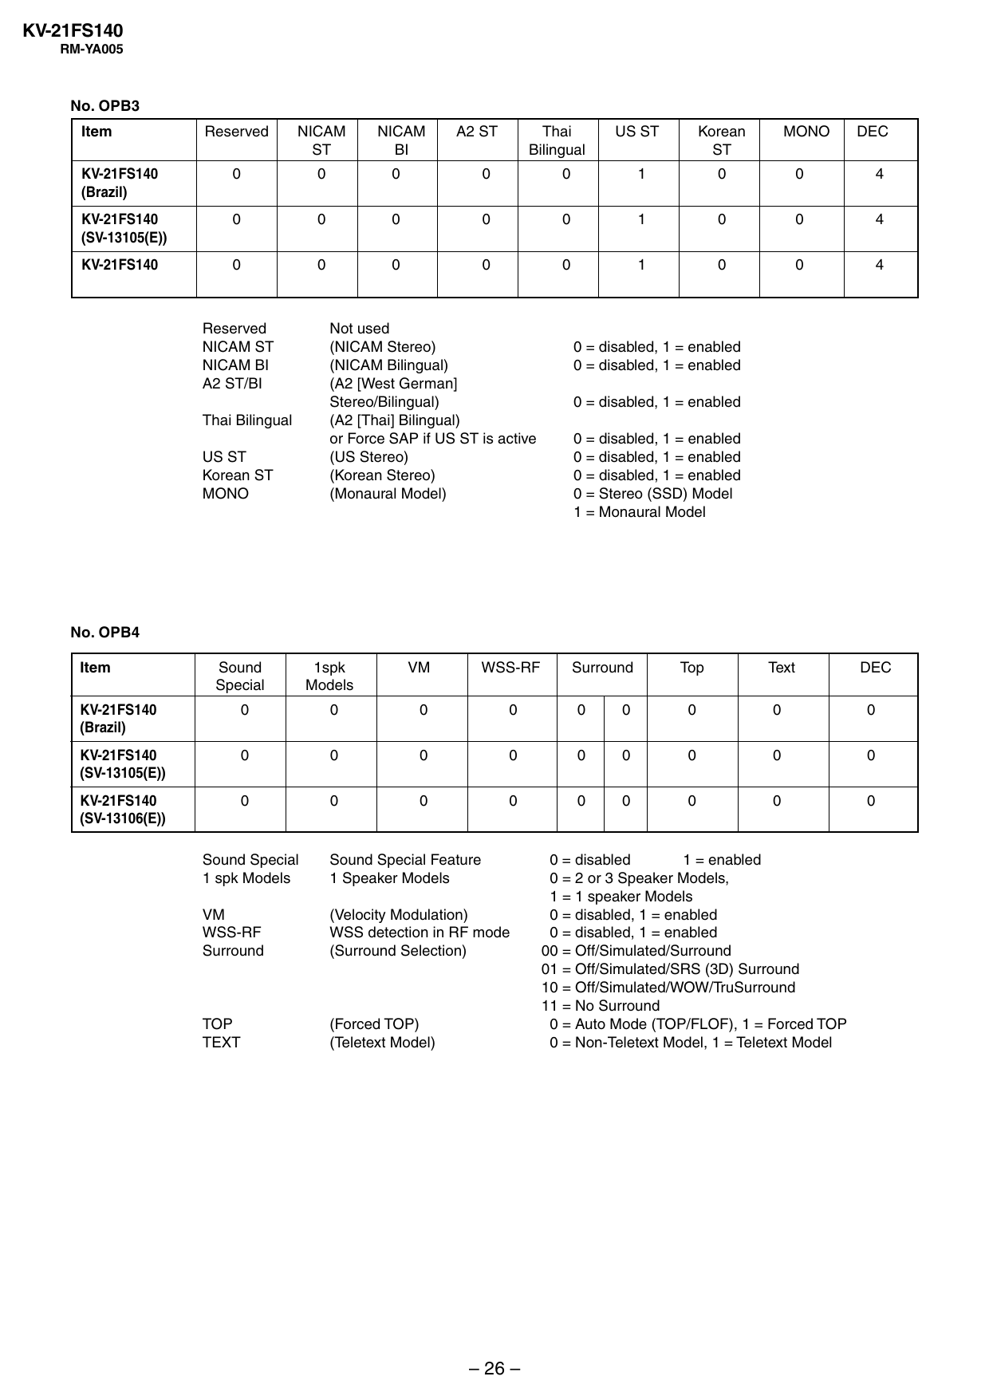
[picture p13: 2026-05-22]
tv/manual/rev_brazil/pages/img/page-27.png

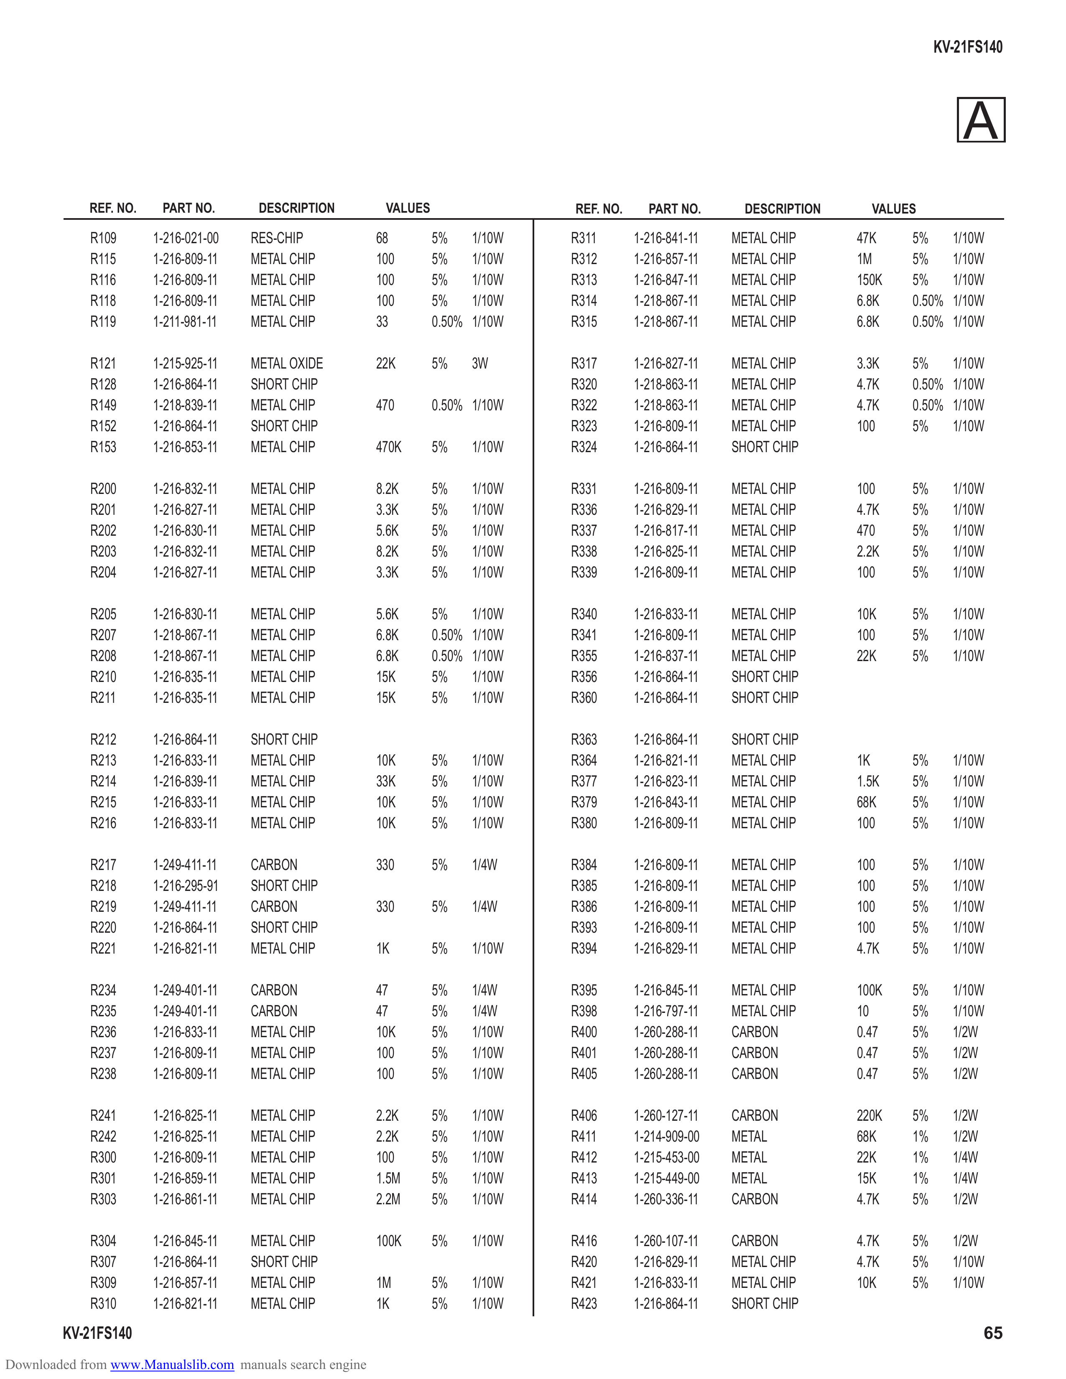
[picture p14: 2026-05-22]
tv/manual/rev_s79aa/pages/img/page-65.png

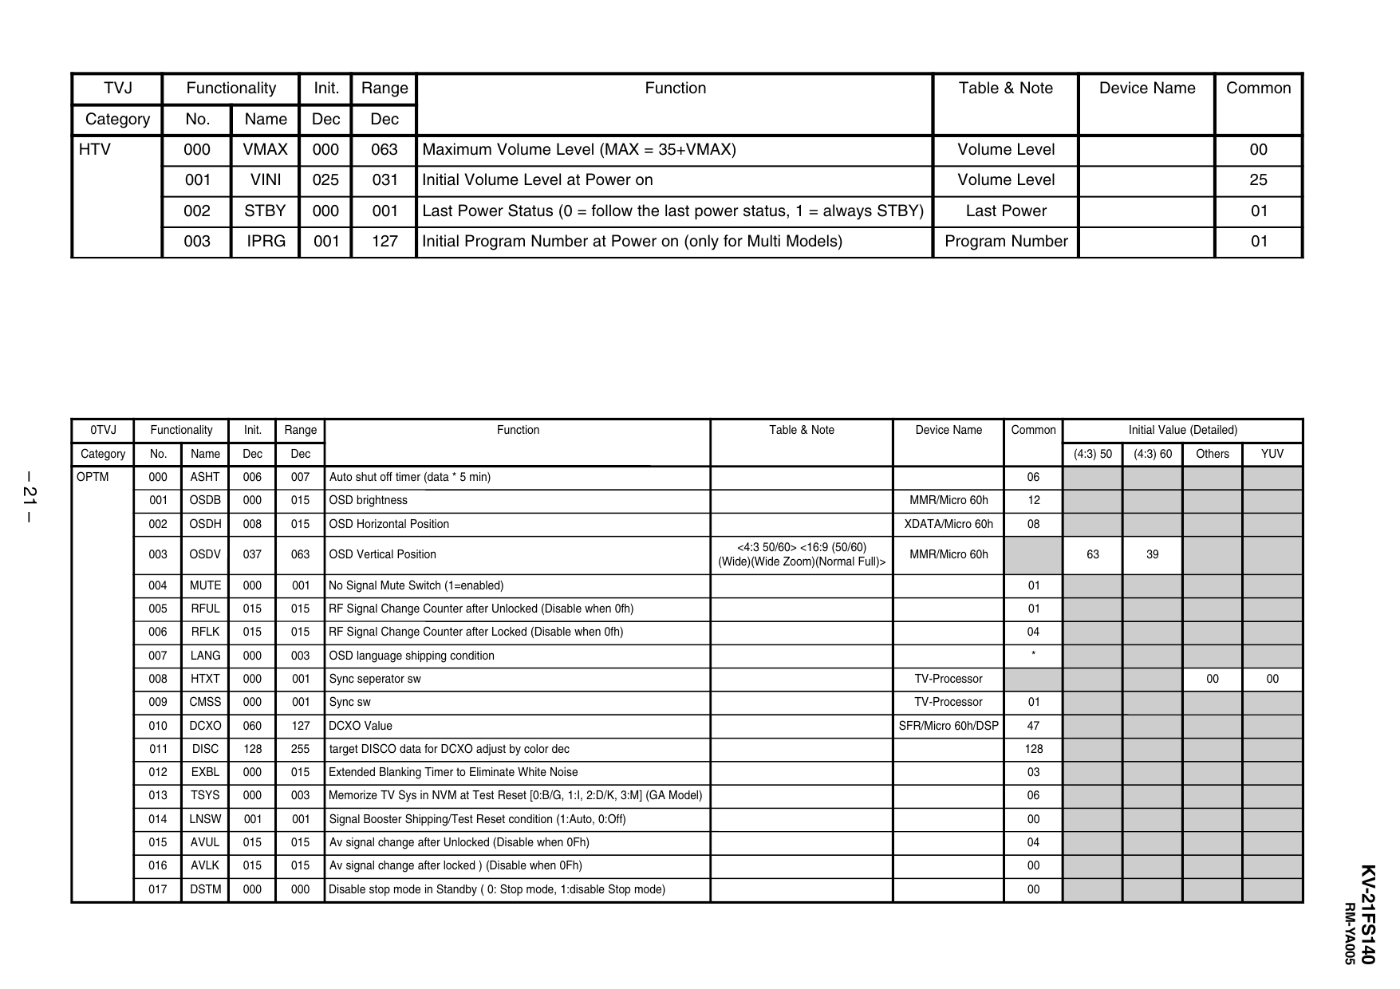
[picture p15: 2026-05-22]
tv/manual/rev_brazil/pages/img/page-22.png

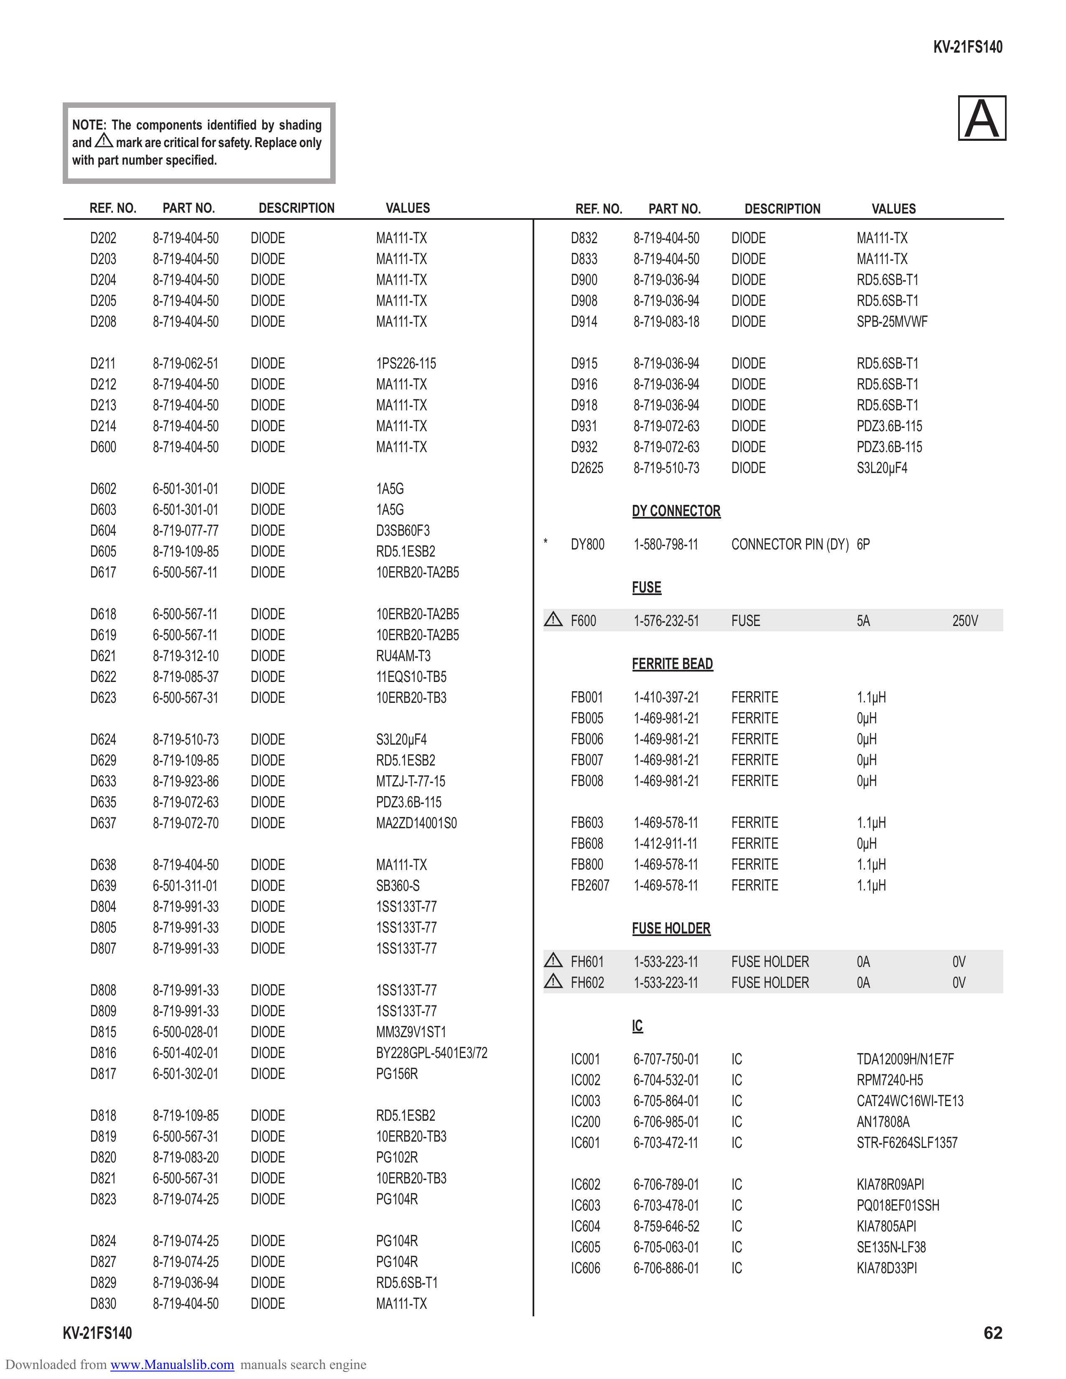
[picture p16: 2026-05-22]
tv/manual/rev_s79aa/pages/img/page-62.png

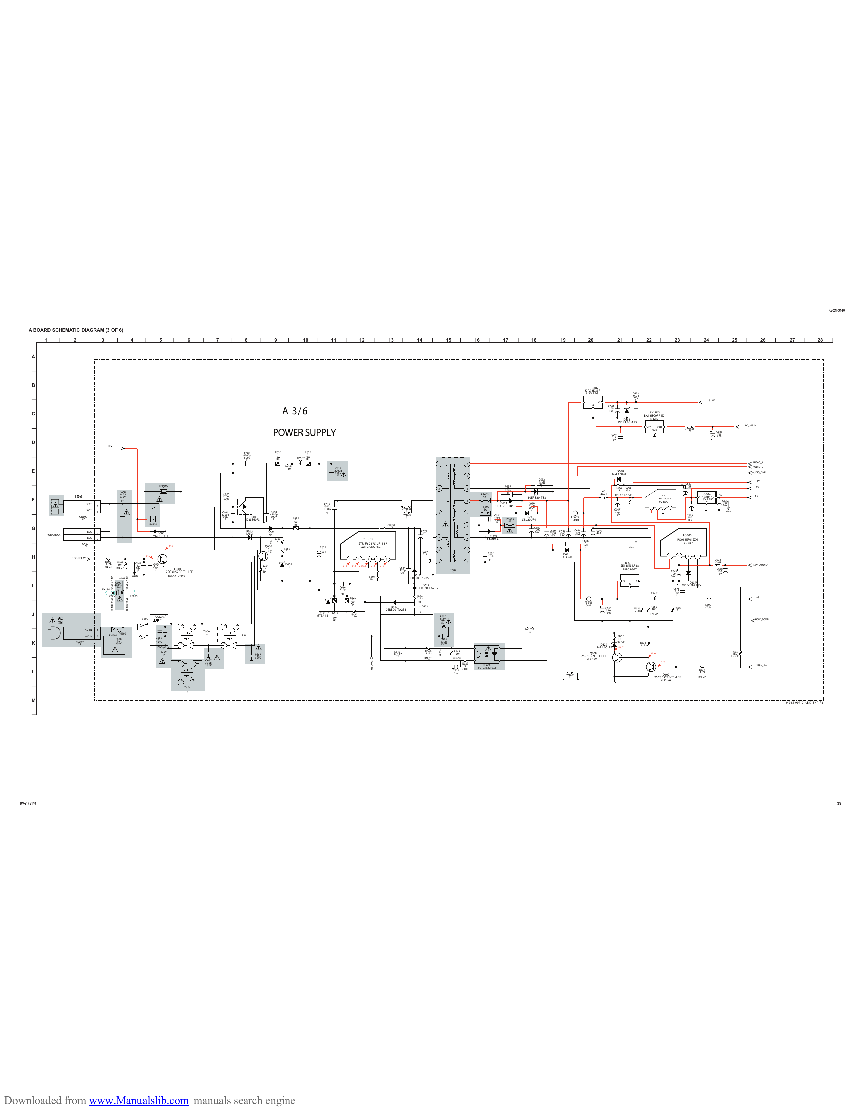
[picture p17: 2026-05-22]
tv/manual/rev_s79aa/pages/img/page-39.png

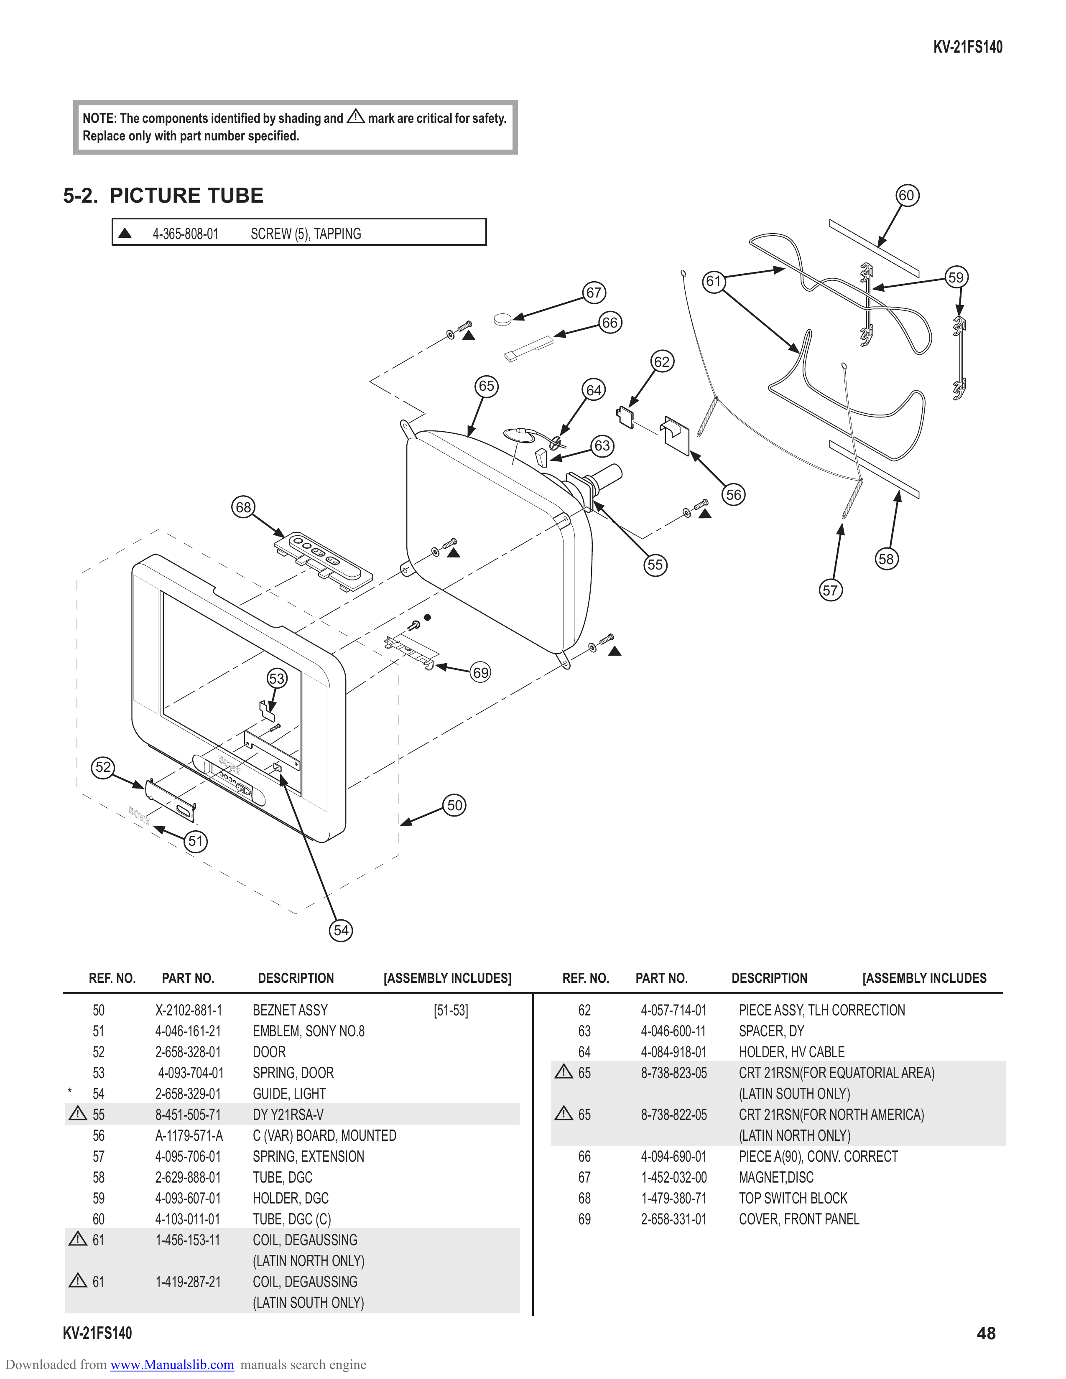
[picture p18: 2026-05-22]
tv/manual/rev_s79aa/pages/img/page-48.png

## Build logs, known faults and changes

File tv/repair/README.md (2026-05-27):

# Lista de Componentes — Reparo Pincushion KV-21FS140

**Sintoma:** Bordas curvadas para dentro, com spikes de largura normal intermitentes. Aparece em poucos segundos após ligar.
**Causa provável:** Componente ativo instável no circuito EW — C857/C861/C867 trocados sem resolver.

---

## Ordem de reparo

### Etapa 1 — Capacitores eletrolíticos (causa mais provável)

Trocar primeiro. Se resolver, não precisa continuar.

| Componente a comprar | Qtd | Ref na placa | Valor original | Local no circuito |
|---|---|---|---|---|
| ~~220µF 25V 105°C electrolytic~~ | ~~3x~~ | ~~C857, C861~~ | ~~220µF 25V~~ | ~~Trocados — não resolveu~~ |
| ~~33µF 160V 105°C electrolytic~~ | ~~2x~~ | ~~C867~~ | ~~33µF 160V~~ | ~~Trocado — não resolveu~~ |
| 100µF 35V 105°C electrolytic | 2x | C854 (+ 1 reserva) | 100µF 35V | Bootstrap vertical IC804 |

> **Atenção:** usar obrigatoriamente capacitores **105°C**. Não usar 85°C — área quente, falharão novamente rápido.
> C867: tensão mínima 160V — não substituir por tensão menor.

---

### Etapa 2 — Transistores e op-amp do circuito EW

Se etapa 1 não resolver completamente.

| Componente a comprar | Qtd | Ref na placa | Valor original | Função |
|---|---|---|---|---|
| 2SC1815 ou BC547 (NPN) | 2x | Q806, Q814 | 2SC1623-L5L6 | MIXER EW e auxiliares |
| KTA1279 (PNP) | 1x | Q809 | KTA1279 | Auxiliar EW (PNP — substituto diferente de Q806!) |
| 2SC3209LK | 2x | Q803, Q810 | 2SC3209LK | PIN AMP / H-DRIVE (original preferível) |
| JRC4558 ou NE5532 DIP-8 | 1x | IC802 | TJM4558CDT | Dual op-amp — processa sinal EWD |
| IRF614 | 1x | Q808 | IRF614-037 | S-CORRECTION MOSFET (difícil achar — pedir junto) |

> **Atenção pinout transistores japoneses:** 2SC1623 e 2SC1815 têm pinagem diferente de BC547 europeu.
> Confirmar EBC antes de soldar. Medir com multímetro no modo diodo antes de instalar.
>
> **Q809 é PNP (KTA1279)** — NÃO substituir com 2SC1815/BC547.
>
> **Q803 (PIN AMP):** opera em tensões mais altas. Preferir 2SC3209LK original ou equivalente de mesma classe.

---

### Etapa 3 — Diodos do circuito EW

Se etapa 1 e 2 não resolverem.

| Componente a comprar | Qtd | Ref na placa | Valor original | Função |
|---|---|---|---|---|
| UF4007 (fast recovery 1A 1000V) | 9x | D819, D821, D823, D824, D827 (+ reservas) | 10ERB20-TB3 / PG104R | Retificadores fast recovery EW |
| RD5.1ESB2 (Zener 5.1V) | 1x | D818 | RD5.1ESB2 | Referência Zener — NÃO substituir com UF4007 |

> UF4007 substitui apenas os fast recovery (10ERB20 / PG104R).
> D818 é Zener 5.1V — componente diferente, substituto diferente.

---

### Etapa 4 — Resistores fusíveis (FPRD)

Verificar visualmente antes de pedir. Trocar se houver sinal de queima ou se medição indicar valor incorreto.

| Componente a comprar | Qtd | Ref na placa | Valor | Função |
|---|---|---|---|---|
| 0.47Ω 1/2W | 2x | R400, R401 | 0.47Ω | Sensing corrente yoke H — fusíveis |
| 2.2Ω 1/4W | 1x | R891 | 2.2Ω | Fusível saída vertical IC804 |
| 3.3kΩ 1/10W | 1x | R895 | 3.3kΩ | Sensing corrente vertical |
| 47kΩ 1/4W | 1x | R888 | 47k | Divisor sinal EW |

---

## Lista de compra consolidada

```
CAPACITORES:
  3x  220µF 25V 105°C electrolytic
  2x  33µF 160V 105°C electrolytic
  2x  100µF 35V 105°C electrolytic

TRANSISTORES:
  2x  2SC1815 ou BC547 (NPN) — Q806, Q814
  1x  KTA1279 (PNP) — Q809
  2x  2SC3209LK — Q803, Q810
  1x  IRF614 — Q808

OP-AMP:
  1x  JRC4558 ou NE5532 DIP-8 — IC802

DIODOS:
  9x  UF4007 (fast recovery) — D819, D821, D823, D824, D827
  1x  RD5.1ESB2 (Zener 5.1V) — D818

RESISTORES:
  2x  0.47Ω 1/2W — R400, R401
  1x  2.2Ω 1/4W — R891
  1x  3.3kΩ 1/10W — R895
  1x  47kΩ 1/4W — R888
```

---

## Verificação gratuita — fazer ANTES de comprar qualquer coisa

### Parâmetros GEOM via service mode

NVM corrompida pode causar pincushion permanente sem relação com temperatura. Verificar antes de pedir peças.

**Entrar no service mode:**
```
[DISPLAY] → [5] → [VOL+] → [POWER]  (com TV em standby)
```

**Verificar e corrigir se necessário:**

| Item# | Nome | Valor correto |
|---|---|---|
| 006 | EWPW | 31 |
| 007 | UCOP | 17 |
| 008 | LCOP | 17 |
| 009 | EWTZ | 31 |
| 005 | HSIZ | 31 |

Se algum valor estiver errado: corrigir com [3]/[6], gravar com [MUTING] → [−].
Se corrigir o problema → NVM estava corrompida, não precisa trocar componentes.

### Juntas frias (cold solder joints)

Inspecionar visualmente com lupa ou luz rasante os pontos de solda em:
- Q806 (MIXER)
- IC802 (op-amp)
- L802 (bobina 22mH)
- Conectores CN801

Junta fria aparece como solda fosca, rachada ou com anel ao redor do componente.
Resolver com retoque de solda — sem custo.

### L802 — bobina EW (medir antes de pedir)

Medir resistência DC com multímetro nos terminais de L802 (bobina 22mH).
Deve ser poucos ohms (tipicamente 2–5Ω).
Leitura aberta (OL) = bobina rompida → causa pincushion independente de temperatura.
L802 é peça especializada — difícil de achar, pedir só se confirmado defeituoso.

---

## Diagnóstico rápido antes de trocar

Se tiver **spray de gelo (freeze spray):**
Ligar TV, aguardar pincushion aparecer, borrifar em C857/C861.
Se imagem corrigir momentaneamente → caps confirmados, etapa 1 resolve.

Se tiver **medidor de ESR:**
Medir C857/C861 com TV quente. ESR > 1Ω em 220µF 25V = cap ruim.

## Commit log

2026-05-22 chore: reorganize repo into tv/, scart/, consoles/
    - tv/manual/rev_brazil/: first manual (57p) + extracted pages
    - tv/manual/rev_s79aa/: second manual (69p) + extracted pages (new)
    - tv/circuits/, tv/repair/, tv/mod_rgb/: moved from root
    - scart/cables/: cable wiring per console
    - scart/: standard, switch, suppliers
    - consoles/nes/, n64/, snes/, megadrive/: console mod docs
    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
    [rgb_mod.kicad_sch]
2026-05-22 docs: add s79aa INDEX.md and cross-reference differences in circuits
    - tv/manual/rev_s79aa/INDEX.md: full index matching rev_brazil depth
    - self_diagnostic.md: note VOL-/VOL+ difference between variants
    - geom_service_params.md: note NTSC-only geometry modes for s79aa,
    add NTSC adjustment sequence and targets
    - service_mode_categories.md: table of differing params (FORF/LANG/SPCH)
    and OPB interpretation difference (PAL/NTSC multi vs NTSC-only)
    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
2026-05-22 docs: add README.md navigation to all folders; update manual/README
    - README.md (root): overview and top-level structure
    - tv/README.md, tv/circuits/README.md, tv/repair/README.md,
    tv/mod_rgb/README.md: navigation for tv subtree
    - consoles/README.md + per-console READMEs (nes, n64, snes, megadrive)
    - scart/cables/README.md
    - tv/manual/README.md: add INDEX.md links and correct s79aa destination
2026-05-22 refactor: standardize all filenames to snake_case lowercase
    - Rename SCHEMATIC_ANALYSIS.md → schematic_analysis.md
    - Rename block001-006 → block_001-006, cboard → c_board
    - Rename Trinitron_kv21fs140_sccs79aa.pdf → trinitron_kv21fs140_sccs79aa.pdf
    - Convert pages/*.txt → pages/*.md with embedded image reference
    - Move pages/*.png → pages/img/*.png
    - Update all internal links in README files
2026-05-22 fix: correct broken internal links after file renames
    - rgb_mod.md: fix 4 refs (cboard→c_board, block00X→block_00X, add ../ prefix)
    - n64.md, nes.md: mods.md→README.md (file never existed)
    - ps2.md: ps1_scart.md→ps1.md
2026-05-22 style: use full repo paths in link display text
    Replace relative ../path display text with absolute repo paths
    (e.g. ../circuits/foo.md → tv/circuits/foo.md) for readability.
    Link targets (href) unchanged.
2026-05-26 docs(mod_rgb): add brightness/contrast controls and YPbPr alternative
    - Add two implementation options for signal chain:
    - Option A: TLV2374 op-amp with brightness pot, 3-gang contrast pot,
    per-channel white balance trimpots; fix virtual GND from 2×10kΩ
    (2.5V, clipping at gain=2) to 33kΩ+10kΩ (~1.16V, headroom ≥1V)
    - Option B: LM1203N dedicated RGB video amp with native contrast/
    brightness/white balance control pins; requires 12V supply
    - Add RGB→YPbPr converter alternative section: J901 confirmed to
    accept 240p/15kHz (tested with PS1/FF8); document analog-only
    converters that pass 240p natively (RetroTINK RGB2COMP, AliExpress
    LM1881+BA7230LS); explain why upsc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
2026-05-27 fix(repair): update KV-21FS140 component list after cap swap failed
    C857/C861/C867 replaced — pincushion persists. Updated symptom description,
    corrected component values (C854=100µF, R891=2.2Ω, R895=3.3kΩ), identified
    Q809 as PNP (KTA1279), D818 as Zener 5.1V (not UF4007).
